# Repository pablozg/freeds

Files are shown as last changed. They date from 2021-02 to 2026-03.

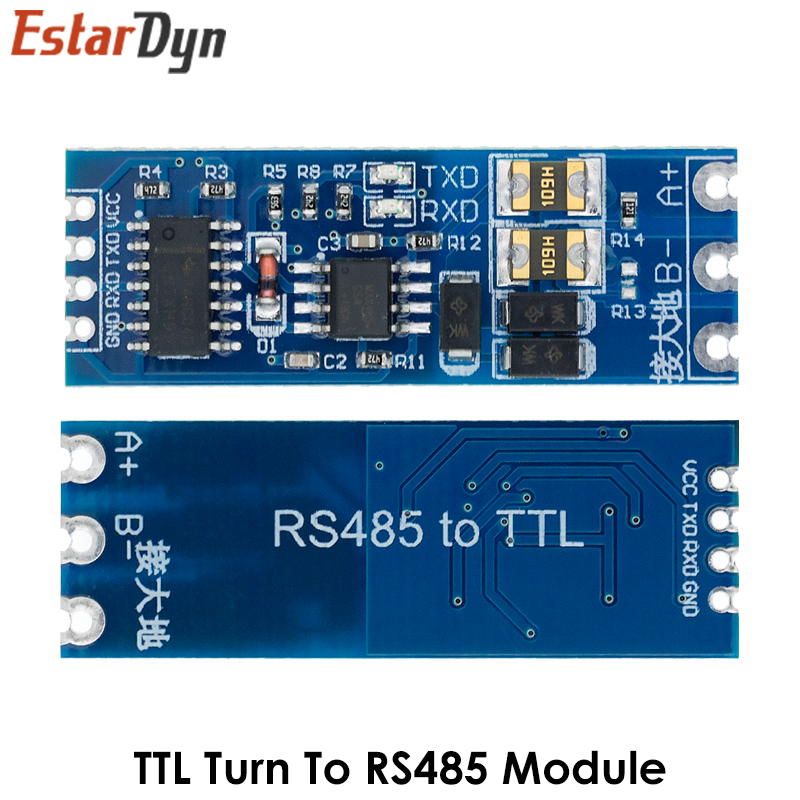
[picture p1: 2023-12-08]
hardware/Clinxer - Version ACS712/FreeDS/Hfd8c04c511834028811a94b4a634df0ex.jpg

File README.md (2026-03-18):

<h1 align="center">
    FreeDS
    <br>
    <a href="#">
        
    </a>
</h1>

**⚠️ ATTENTION / ADVERTENCIA** The project has evolved through different licensing stages. Please check the version you are using:

* **v1.0.7 rev2:** Open Source (GPL-3.0). Source code available in this repo.
* **Betas (up to v1.0.21):** Distributed under CC BY-ND 4.0.
* **v2.0.0 and above:** Proprietary EULA. Requires **Per-Device Activation**.

You can get more info in the Telegram Channel: [http://t.me/freeds_es](http://t.me/freeds_es) or check the community manual: [Community Manual](https://docs.google.com/document/d/1-XLCqHEbpqEPi4geI4CbANmGxodExC__zDvND89xjIU)

**FreeDS** is a universal surplus manager, totally independent of the energy source (photovoltaic and/or wind), created by **Pablo Zerón**, tested by Aeizoon, and PCB Design by amcalo.

---

## 🔑 License & Activation (v2.0.0+)

Starting from **version 2.0.0**, FreeDS uses a **Proprietary EULA**. 

- **Ownership:** The software is the exclusive property of **Pablo Zerón**.
- **Cloud Services:** Powered and managed by **Ibepower Technologies S.L.**
- **Activation:** A unique **Activation Key** is required for each device (linked to Hardware ID).

### How to get a Key?
Send an email to **derivadorfreeds@gmail.com** with:
1. Your **Device ID** (visible on the screen/web interface).
2. **DIY/Contributors:** Proof of contribution or self-assembly (image of the device) to request a **free key**.
3. **Commercial Use:** Request a quote if you are selling hardware with FreeDS firmware.

---

## 📜 License History

| Version Range | License Type | Description |
| :--- | :--- | :--- |
| **<= v1.0.7 rev2** | [GPL-3.0](https://opensource.org/licenses/GPL-3.0) | Open Source. Original legacy code. |
| **v1.0.8 - v1.0.21** | [CC BY-ND 4.0](https://creativecommons.org/licenses/by-nd/4.0/) | Creative Commons. No derivatives allowed. |
| **>= v2.0.0** | **Proprietary EULA** | Proprietary. Requires activation key per hardware. |

*Full legal terms can be found in the [EULA.md](./EULA.md) file.*

---

## ☕ Donate
If you find this project useful, consider supporting its development:



---

## Dependencies (for legacy v1.0.7 compilation)
- **TickerScheduler**: [Toshik/TickerScheduler](https://github.com/Toshik/TickerScheduler)
- **Async MQTT client**: [marvinroger/async-mqtt-client](https://github.com/marvinroger/async-mqtt-client)
- **ArduinoJson**: [bblanchon/ArduinoJson](https://github.com/bblanchon/ArduinoJson)
- **AsyncTCP**: [me-no-dev/AsyncTCP](https://github.com/me-no-dev/AsyncTCP)
- **ESPAsyncWebServer**: [me-no-dev/ESPAsyncWebServer](https://github.com/me-no-dev/ESPAsyncWebServer)
- **ThingPulse OLED SSD1306**: [ThingPulse/esp8266-oled-ssd1306](https://github.com/ThingPulse/esp8266-oled-ssd1306)
- **esp32ModbusTCP**: [bertmelis/esp32ModbusTCP](https://github.com/bertmelis/esp32ModbusTCP)

## Compile (Legacy v1.0.7)
1. **Download:** Clone this repo or download the [PID.zip](https://github.com/pablozg/freeds/archive/refs/heads/PID.zip).
2. **Library Setup:** Extract `lib.zip` into the `/lib` folder.
3. **IDE:** Open with **VSCode** and **PlatformIO**.
4. **Build:** Use PlatformIO to compile and upload to your ESP32.

---
Copyright (c) 2026 Pablo Zerón. Cloud services provided by Ibepower Technologies S.L.

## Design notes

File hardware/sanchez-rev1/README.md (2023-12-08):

La arquitectura "Sánchez rev1" se basa en las ideas de otras arquitecturas hardware para FreeDS, separando el diseño en dos PCBs que caben en las cajas estancas usadas por otras arquitecturas hardware.

La arquitectura Sánchez rev1 incluye:

- Conectores para RS485
- Conectores para sensores de temperatura
  - Espacio para un sensor montado en la parte inferior de la placa de control, pensado para que doblando las patillas pueda tocar el disipador del TRIAC
- Conectores para relés
  - Conector para ventilador controlado por relé 4
- Conectores para pinza amperimétrica
  - Conector de dos pines
  - Conector de jack de audio de 3.5mm

La novedad con respecto a otras arquitecturas es la circuitería y conectores para poder controlar un ventilador por PWM: la idea es que cuanto mayor sea el porcentaje de PWM, más trabajará el ventilador.

El diseño está hecho con KiCAD, y se incluyen los ficheros Gerber (ya compilados y por separado para cada una de las dos PCBs) para comodidad a la hora de pedir la fabricación de las placas.

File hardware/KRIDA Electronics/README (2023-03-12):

Thanks to Olegs Bugrovs from KRIDA Electronics for his contribution to freeDS project publishing
both the pcb schematics and the source code of his dimmer, making it easier to repair and/or upgrade.

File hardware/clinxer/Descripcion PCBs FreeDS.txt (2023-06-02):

Estas PCBs han sido diseñadas siguiendo los esquemas e indicaciones publicados en https://freeds.es con el programa Kicad.
En cuanto a sus dimensiones, estan pensadas para la caja sonoff, que es economica, robusta y tiene la tapa transparente para poder visualizar la pantalla.

He querido hacer unas placas que puedan ser utiles a la mayor parte posible de la gente. Asi, aprovechando la altura de la caja de unos 40mm he pensado en colocar dos circuitos impresos apilados.

El circuito inferior es la placa de potencia.
Se puede escoger entre montar el modulo chino (lowcost) desoldando las bornas y el triac que lleva y puenteando la puerta del modulo con el pin TP1 del circuito impreso, o montar el MOC3041 con sus tres resistencias (ultra lowcost) o cambiar de un sistema a otro para probar cual nos funciona mejor.
Por un tema de espacio, en los bornes de conexion de potencia he incluido uno para unir las tierras de entrada y salida, uno de entrada y salida para el neutro, y las fases de entrada y salida. Las pistas de conexion de potencia al triac y fusible no tienen mascara de soldadura para poder aumentar su seccion depositando una capa gruesa de estaño, soldando un hilo de cobre encima, o lo que se os ocurra.

La placa de control superior dispone de espacio para el modulo RS485 (modbus) a TTL para personas que lo necesiten. El modulo ESP32 escogido es el ESP32-WROOM-32U que tiene conexion de antena externa y deberia dar mas alcance de conexion wifi. La pantalla se monta separada del ESP32.
Tiene pines para conectar los sensores de temperatura, los reles externos, y el sensor de corriente SCT-013-030 si se desea utilizar. El ventilador puede conectarse a 5V para funcionamiento permanente o asociarlo al rele 4 para funcionamiento a partir de un pwm determinado.
Tambien puede colocarse el sensor de temperatura DS18B20 en la placa cerca del triac para poder unir al disipador.

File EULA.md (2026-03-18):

# TÉRMINOS LEGALES, POLÍTICA DE PRIVACIDAD Y CONDICIONES DE USO (EULA)

**Última actualización:** 01/01/2026

Este documento es un acuerdo legal entre el usuario final y **Pablo Zerón** (en adelante, "el Autor") respecto al software/firmware **FreeDS**, así como los términos de privacidad gestionados por **Ibepower Technologies S.L.** (en adelante, "el Proveedor de Servicios Cloud").

---

## 1. RESUMEN DE RESPONSABILIDADES

* **Propiedad Intelectual y Licencia:** **Pablo Zerón** (Autor y Propietario único del código).
* **Tratamiento de Datos y Cloud:** **Ibepower Technologies S.L.** (NIF: B13899117).
* **Finalidad del sistema:** Gestión de licencias, telemetría y servicios de monitorización en la nube.
* **Contacto para Activaciones:** `derivadorfreeds@gmail.com`

---

## 2. INFORMACIÓN DETALLADA

### 2.1 Propiedad Intelectual y Licencia de Uso
El firmware y software **FreeDS** es propiedad intelectual exclusiva de **Pablo Zerón**. 

* **Licencia Propietaria:** Este software (Versiones 2.0.0 o superior) **NO se distribuye bajo licencias Creative Commons**. Se otorga una licencia de uso sujeta a la activación mediante una clave única.
* **Activación por Dispositivo:** El software requiere una **Clave de Activación** vinculada de forma unívoca al identificador de hardware (Hardware ID / ESP32 ID) de cada dispositivo.
* **Restricciones:** Queda estrictamente prohibida la ingeniería inversa del sistema de activación, la distribución de copias activadas sin autorización previa y la eliminación de los créditos de autoría de Pablo Zerón.

### 2.2 Condiciones Comerciales y de Activación
El Autor se reserva el derecho de establecer las condiciones para la entrega de claves:

1.  **Uso Comercial / Reventa:** Cualquier entidad o tercero que comercialice hardware o servicios con el firmware FreeDS deberá obtener y abonar la tarifa por cada Clave de Activación generada.
2.  **Usuarios DIY y Colaboradores:** El Autor podrá facilitar claves **gratuitas** a usuarios particulares (montaje propio no baadas en soluciones comerciales), colaboradores activos o donantes, previa solicitud y validación.

### 2.3 Privacidad y Protección de Datos (RGPD)
Los servicios de infraestructura en la nube y bases de datos son operados por **Ibepower Technologies S.L.**

* **Finalidad:** Monitorización remota y validación técnica de la licencia vinculada al ID de hardware.
* **Datos Recopilados:** Telemetría técnica. Solo se tratarán datos personales (como el email) si el usuario se registra voluntariamente en la plataforma Cloud de Ibepower.
* **Derechos:** Puedes ejercer tus derechos de acceso, rectificación o supresión contactando con `info@ibepower.com`.

### 2.4 Procedimiento de Activación
Para solicitar la clave de activación, envía un correo a **derivadorfreeds@gmail.com** con:
1.  El **ID de dispositivo** (visible en la interfaz o pantalla del hardware).
2.  Justificante de colaboración/donativo (para claves gratuitas) o solicitud comercial.

---

*Pablo Zerón e Ibepower Technologies S.L. se reservan el derecho de modificar estos términos.*

# LEGAL TERMS, PRIVACY POLICY, AND TERMS OF USE (EULA)

**Last updated:** 01/01/2026

This document constitutes a legal agreement between the end-user and **Pablo Zerón** (hereinafter, "the Author") regarding the **FreeDS** software/firmware, as well as the privacy terms managed by **Ibepower Technologies S.L.** (hereinafter, "the Cloud Service Provider").

---

## 1. SUMMARY OF RESPONSIBILITIES

* **Intellectual Property and License:** **Pablo Zerón** (Author and sole Owner of the code).
* **Data Processing and Cloud Services:** **Ibepower Technologies S.L.** (Tax ID/NIF: B13899117).
* **System Purpose:** License management, telemetry, and cloud monitoring services.
* **Activation Contact:** `derivadorfreeds@gmail.com`

---

## 2. DETAILED INFORMATION

### 2.1 Intellectual Property and License of Use
The **FreeDS** firmware and software are the exclusive intellectual property of **Pablo Zerón**.

* **Proprietary License:** This software (Versions 2.0.0 or higher) is **NOT distributed under Creative Commons licenses**. A license of use is granted subject to activation via a unique key.
* **Per-Device Activation:** The software requires an **Activation Key** uniquely linked to the hardware identifier (Hardware ID / ESP32 ID) of each individual device.
* **Restrictions:** Reverse engineering of the activation system, distribution of activated copies without prior authorization, and the removal of Pablo Zerón's authorship credits are strictly prohibited.

### 2.2 Commercial and Activation Conditions
The Author reserves the right to establish the conditions for the issuance of activation keys:

1.  **Commercial Use / Resale:** Any entity or third party marketing hardware or services that include the FreeDS firmware must obtain and pay the established fee for each generated Activation Key.
2.  **DIY Users and Collaborators:** The Author may provide **free** activation keys to individual users (non-commercial self-builds not based on commercial solutions), active collaborators, or donors, subject to request and validation.

### 2.3 Privacy and Data Protection (GDPR)
Cloud infrastructure services and databases are operated by **Ibepower Technologies S.L.**

* **Purpose:** Remote monitoring and technical validation of the license linked to the hardware ID.
* **Data Collection:** Technical telemetry. Personal data (such as email) will only be processed if the user voluntarily registers on the Ibepower Cloud platform.
* **User Rights:** You may exercise your rights of access, rectification, or erasure by contacting `info@ibepower.com`.

### 2.4 Activation Procedure
To request the activation key required for software operation, please send an email to **derivadorfreeds@gmail.com** including:

1.  The **Device ID** (visible on the configuration interface or the hardware screen).
2.  **Proof:** Documentation of collaboration/donation (for free keys) or a commercial license inquiry.

---

*Pablo Zerón and Ibepower Technologies S.L. reserve the right to modify these terms to adapt them to technical or legal developments.*

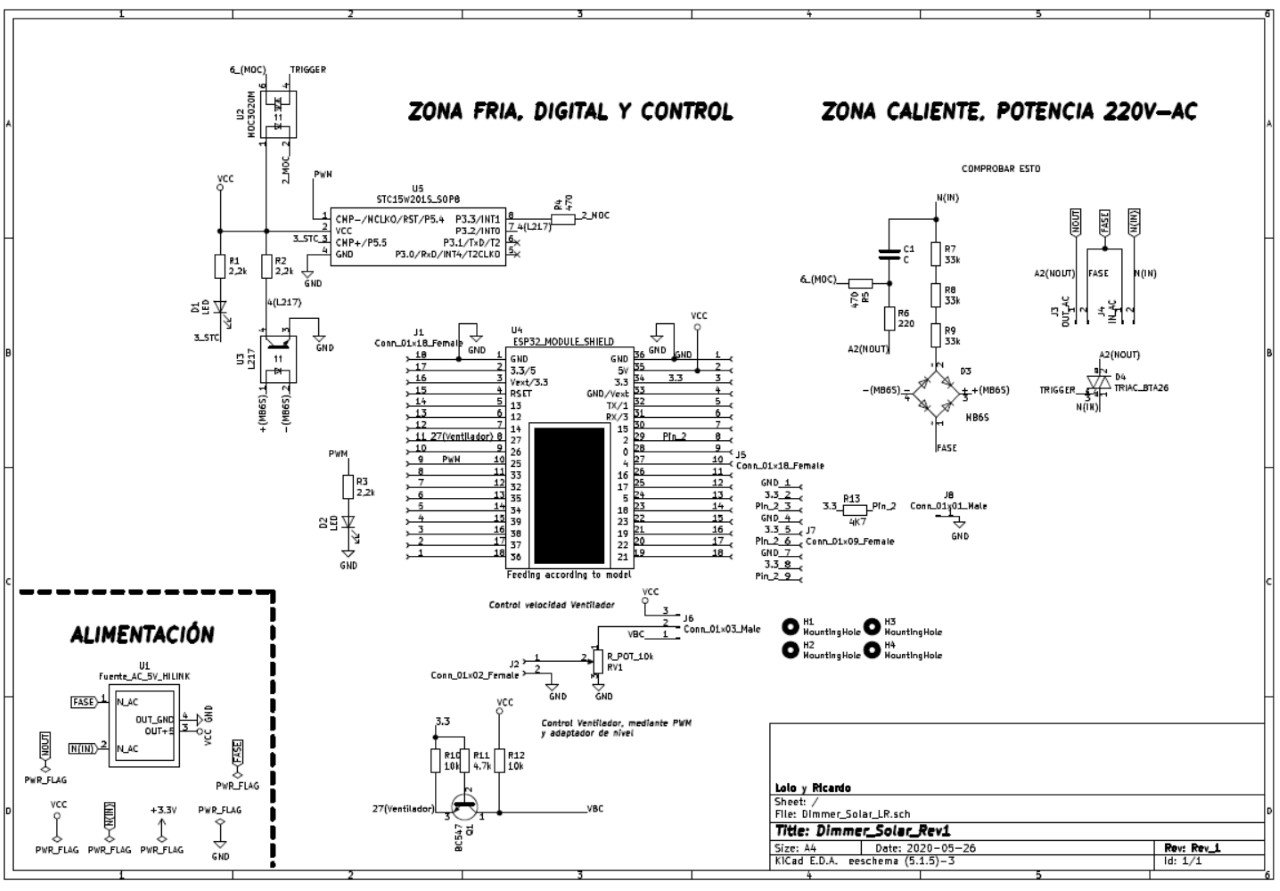
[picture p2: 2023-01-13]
Scheme PCB 1.0.jpg

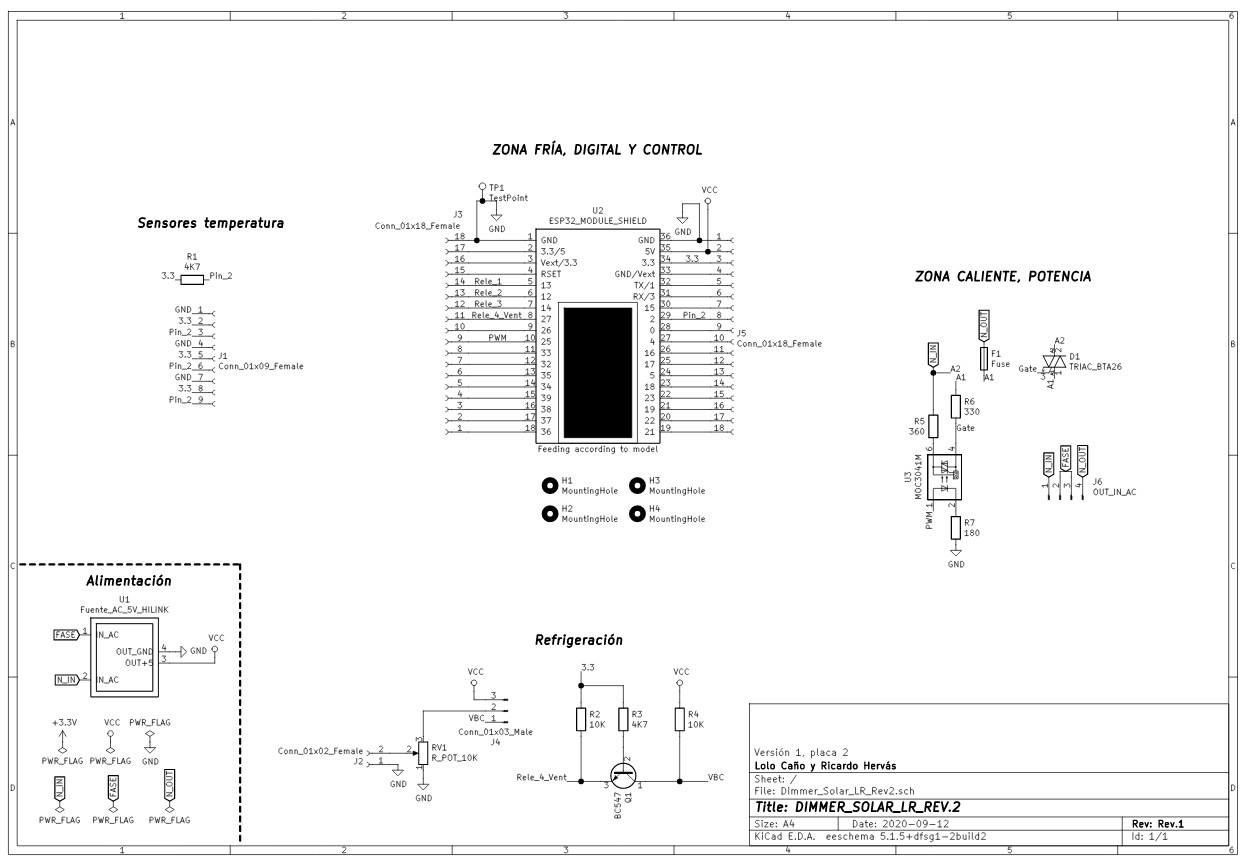
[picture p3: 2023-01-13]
Scheme PCB 2.0.jpg

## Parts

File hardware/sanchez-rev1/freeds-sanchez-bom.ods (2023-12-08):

Item | Qty | Reference(s) | Value | LibPart | Grupo | Footprint | Datasheet | DNP | Compras | Grupo | Nota
1 | 1 | AE1 | Antenna | Device:Antenna | Básico |  | ~ |  | https://www.aliexpress.com/item/32276257238.html | Básico
2 | 2 | C1, C2 | 10µF | Device:C_Small | Pinza Amperimétrica | Capacitor_THT:C_Disc_D4.7mm_W2.5mm_P5.00mm | ~ |  | https://www.aliexpress.com/item/1005001715033995.html | Pinza Amperimétrica
3 | 1 | D2 | 1N4007 | Diode:1N4007 |  | Diode_THT:D_DO-41_SOD81_P10.16mm_Horizontal | http://www.vishay.com/docs/88503/1n4001.pdf
4 | 1 | F1 | Fuse | Device:Fuse | Básico | Fuse:Fuseholder_Clip-5x20mm_Littelfuse_100_Inline_P20.50x4.60mm_D1.30mm_Horizontal | ~ |  | https://www.aliexpress.com/item/1005002876255086.html | Básico
5 | 2 | J1, J2 | Clema K1000 | Connector:Screw_Terminal_01x02 | Básico | componentes-auxiliares:Clema 20x14mm K1000 2P | ~ |  | https://www.aliexpress.com/item/4000170287617.html | Básico
6 | 2 | J3, J4 | Inter-PCB | Connector_Generic:Conn_01x04 | Básico | Connector_PinHeader_2.54mm:PinHeader_1x04_P2.54mm_Vertical | ~ |  |  | Básico
7 | 1 | J5 | Pinza Amper. | Connector:Conn_01x02_Male | Pinza Amperimétrica | Connector_PinHeader_2.54mm:PinHeader_1x02_P2.54mm_Vertical | ~ |  | https://www.aliexpress.com/item/32758380907.html | Pinza Amperimétrica
8 | 1 | J6 | CT Clamp | Connector:AudioJack2 | Pinza Amperimétrica | Connector_Audio:Jack_3.5mm_CUI_SJ1-3525N_Horizontal | ~ |  | https://www.aliexpress.com/item/1005004657628758.html https://www.aliexpress.com/item/32871877936.html | Pinza Amperimétrica | PJ3F07 / PJ-324M
9 | 1 | J7 | Temp sensor | Connector:Conn_01x03_Pin | Temperatura | Connector_PinHeader_2.54mm:PinHeader_1x03_P2.54mm_Vertical | ~ |  | https://www.aliexpress.com/item/32758380907.html | Temperatura
10 | 1 | J8 | Temp Sensor | Connector:Conn_01x03_Pin | Temperatura | Connector_PinHeader_2.54mm:PinHeader_1x03_P2.54mm_Vertical | ~ |  | https://www.aliexpress.com/item/32758380907.html | Temperatura
11 | 1 | J9 | R4_FAN | Connector:Conn_01x03_Pin | Ventilador relé | Connector_PinHeader_2.54mm:PinHeader_1x03_P2.54mm_Vertical | ~ |  | https://www.aliexpress.com/item/32758380907.html | Ventilador relé
12 | 1 | J10 | RELÉS | Connector:Conn_01x08_Pin | Relés | Connector_PinHeader_2.54mm:PinHeader_1x08_P2.54mm_Vertical | ~ |  | https://www.aliexpress.com/item/32758380907.html | Relés
13 | 1 | J16 | Conn_01x02_Male | Connector:Conn_01x02_Male | Ventilador PWM | Connector_PinHeader_2.54mm:PinHeader_1x02_P2.54mm_Vertical | ~ |  | https://www.aliexpress.com/item/32758380907.html | Ventilador PWM
14 | 1 | M1 | 40mm 5V PWM Fan | Motor:Fan_4pin |  |  | https://noctua.at/en/products/fan/nf-a4x10-pwm/specification | DNP | https://www.aliexpress.com/item/1005003661639143.html |  | https://electronics.stackexchange.com/questions/446128/5v-4-pin-noctua-a4x10-on-raspberry-pi
15 | 1 | M2 | 40mm Fan | Motor:Fan |  |  | ~ |  | https://www.aliexpress.com/item/33050954650.html
16 | 1 | N1 | Housing | Mechanical:Housing | Básico |  | ~ |  | https://www.aliexpress.com/item/32856717327.html | Básico
17 | 1 | PS1 | HLK-PM01 | Converter_ACDC:HLK-PM01 | Básico | Converter_ACDC:Converter_ACDC_HiLink_HLK-PMxx | http://www.hlktech.net/product_detail.php?ProId=54 |  | https://www.aliexpress.com/item/32408565688.html | Básico
18 | 1 | Q1 | BTA26-600BW | Triac_Thyristor:BTA16-600BW | Básico | componentes-auxiliares:TOP3_Vertical | https://www.st.com/resource/en/datasheet/bta16.pdf |  | https://www.aliexpress.com/item/32508392409.html | Básico
19 | 1 | Q2 | BC337 | Transistor_BJT:BC337 | Ventilador relé | Package_TO_SOT_THT:TO-92_Inline | https://diotec.com/tl_files/diotec/files/pdf/datasheets/bc337.pdf |  | https://www.aliexpress.com/item/1005003391155385.html | Ventilador relé
20 | 1 | Q3 | DS18B20 | Sensor_Temperature:DS18B20 | Temperatura | Package_TO_SOT_THT:TO-92_Inline | http://datasheets.maximintegrated.com/en/ds/DS18B20.pdf |  | https://www.aliexpress.com/item/1783091649.html | Temperatura
21 | 1 | Q4 | BS170 | Transistor_FET:BS170 |  | Package_TO_SOT_THT:TO-92_Inline | https://www.onsemi.com/pub/Collateral/BS170-D.PDF |  | https://www.aliexpress.com/item/33043571478.html
22 | 1 | R1 | 360Ω | Device:R_Small | Básico | Resistor_THT:R_Axial_DIN0207_L6.3mm_D2.5mm_P10.16mm_Horizontal | ~ |  | https://www.aliexpress.com/item/1005001931818502.html | Básico
23 | 1 | R2 | 330Ω | Device:R_Small | Básico | Resistor_THT:R_Axial_DIN0207_L6.3mm_D2.5mm_P10.16mm_Horizontal | ~ |  | https://www.aliexpress.com/item/1005001931818502.html | Básico
24 | 2 | R3, R4 | 180Ω | Device:R_Small | Básico | Resistor_THT:R_Axial_DIN0207_L6.3mm_D2.5mm_P10.16mm_Horizontal | ~ |  | https://www.aliexpress.com/item/1005001931818502.html | Básico
25 | 3 | R5, R6, R9 | 10KΩ | Device:R_Small | Pinza Amperimétrica | Resistor_THT:R_Axial_DIN0207_L6.3mm_D2.5mm_P10.16mm_Horizontal | ~ |  | https://www.aliexpress.com/item/1005001931818502.html | Pinza Amperimétrica
26 | 1 | R7 | 4.7KΩ | Device:R_Small | Temperatura | Resistor_THT:R_Axial_DIN0207_L6.3mm_D2.5mm_P10.16mm_Horizontal | ~ |  | https://www.aliexpress.com/item/1005001931818502.html | Temperatura
27 | 1 | R8 | 3.3Ω | Device:R_Small | Ventilador PWM | Resistor_THT:R_Axial_DIN0207_L6.3mm_D2.5mm_P10.16mm_Horizontal | ~ |  | https://www.aliexpress.com/item/1005001931818502.html | Ventilador PWM
28 | 1 | SW1 | PRG | Switch:SW_SPST | Botón | Button_Switch_THT:SW_Tactile_SPST_Angled_PTS645Vx83-2LFS | ~ |  | https://www.aliexpress.com/item/32912894177.html | Botón
29 | 1 | U2 | MOC3041M | Relay_SolidState:MOC3041M | Básico | Package_DIP:DIP-6_W7.62mm | https://www.onsemi.com/pub/Collateral/MOC3043M-D.pdf |  | https://www.aliexpress.com/item/32870289997.html | Básico
30 | 1 | U3 | HW-0519 (Módulo RS485-TTL) | module:HW-519_MODBUS | Modbus | componentes-auxiliares:HW-519 TTL-RS485 |  |  | https://www.aliexpress.com/item/1005001621746811.html | Modbus
31 | 1 | U4 | ESP32-WROOM-32U | Espressif:ESP32-DevKitC | Básico | Espressif:ESP32-DevKitC | https://docs.espressif.com/projects/esp-idf/zh_CN/latest/esp32/hw-reference/esp32/get-started-devkitc.html |  | https://www.aliexpress.com/item/32864722159.html | Básico
32 | 1 | U5 | SSD1306_I2C_128x64 | OLED_SSD1312_I2C:SSD1312_I2C_128x64 | Básico | componentes-auxiliares:OLED_SSD1306_I2C_0.96 |  |  | https://www.aliexpress.com/item/32638662748.html | Básico

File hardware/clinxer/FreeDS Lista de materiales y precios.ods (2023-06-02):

Id | Identificador | Huella | Cantidad | Identificación | Precio | Suministrador y ref
1 | U3 | MW-519 MODBUS | 1 | Modulo MODBUS | 1,88 | https://es.aliexpress.com/item/1005001621746811.html
2 | R1 | R_0805_2012Metric_Pad1.20x1.40mm_HandSolder | 1 | 180R
3 | U1 | OLED_SSD1306_I2C_0.96 | 1 | SSD1306_I2C_128x64 | 1,69 | https://es.aliexpress.com/item/32638662748.html
6 | R2 | R_0805_2012Metric_Pad1.20x1.40mm_HandSolder | 1 | 4K7
7 | Q1 | TO-92_Inline | 1 | DS18B20 | 0,34 | https://es.aliexpress.com/item/1783091649.html?curPageLogUid=4cPm6rJjSKd2
9 | Q2 | TO-92_Inline | 1 | BC337 | 1,4 | https://es.aliexpress.com/item/1005003391155385.html?curPageLogUid=M835OcH09qsy
10 | SW1 | SW_Tactile_SPST_Angled_6X6X12 | 1 | PRG |  | https://es.aliexpress.com/item/32912894177.html?scm_id=1007.12873.274955.0&scm-url=1007.12873.274955.0
11 | U2 | ESP32-WROOM-32U | 1 | ESP32-WROOM-32U | 4,05 | https://es.aliexpress.com/item/32864722159.html
14 |  | Caja sonoff |  |  | 6,39 | https://es.aliexpress.com/item/32856717327.html
15 |  | Disipador y ventilador |  |  | 5,54 | https://es.aliexpress.com/item/33050954650.html
 |  |  |  |  | 1,27 | GASTOS DE ENVIO PANTALLA ANTENA Y MICRO
18 | J2 | PinHeader_1x04_P2.54mm_Vertical | 1 | Tiras DE PINES MACHO | 1,5 | https://es.aliexpress.com/item/32758380907.html?curPageLogUid=IyVioYqjNETk
19 | PS1 | Converter_ACDC_HiLink_HLK-PMxx | 1 | HLK-PM01 | 3,5 | https://es.aliexpress.com/item/32408565688.html?curPageLogUid=ZmRvf0wLucnI
20 | J1 | KF7.62_4P | 1 | Screw_Terminal_01x04 KF7.62_4P | 0,402 | https://es.aliexpress.com/item/33018709631.html
21 | U5 | YYAC-35 PWM TRIAC | 1 | Modulo de Control PWM de potencia | 6,6 | https://es.aliexpress.com/item/1005004149677279.html
22 | F1 | Fuseholder_Clip-5x20mm_Littelfuse_100_Inline_P20.50x4.60mm_D1.30mm_Horizontal | 1 | Fuse | 1,5 | https://es.aliexpress.com/item/1005002876255086.html?curPageLogUid=At3GBBWHi4sC
 | Q3 | TOP3_Vertical | 1 | BTA26-600BW | 0,72 | https://es.aliexpress.com/item/32508392409.html
 |  |  |  | Mica, separadores, etc | 5
 |  | PCBs |  | JPLC | 2,864 | 5 parejas con envio Global Standard Direct Line
 |  |  |  |  | 44,646

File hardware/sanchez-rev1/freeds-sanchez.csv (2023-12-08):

Source: | /home/ivan/devel/freeds-pcb/sanchez/freeds-sanchez/freeds-sanchez.kicad_sch
Date: | vie 14 jul 2023 13:41:45
Tool: | Eeschema 7.0.3+dfsg-1
Generator: | /usr/share/kicad/plugins/bom_csv_grouped_by_value.py
Component Count: | 38
Collated Components:
Item | Qty | Reference(s) | Value | LibPart | Footprint | Datasheet | DNP | Compras | Grupo | Nota
1 | 1 | AE1 | Antenna | Device:Antenna |  | ~ |  | https://www.aliexpress.com/item/32276257238.html | Básico
2 | 2 | C1, C2 | 10µF | Device:C_Small | Capacitor_THT:C_Disc_D4.7mm_W2.5mm_P5.00mm | ~ |  | https://www.aliexpress.com/item/1005001715033995.html | Pinza Amperimétrica
3 | 1 | D2 | 1N4007 | Diode:1N4007 | Diode_THT:D_DO-41_SOD81_P10.16mm_Horizontal | http://www.vishay.com/docs/88503/1n4001.pdf
4 | 1 | F1 | Fuse | Device:Fuse | Fuse:Fuseholder_Clip-5x20mm_Littelfuse_100_Inline_P20.50x4.60mm_D1.30mm_Horizontal | ~ |  | https://www.aliexpress.com/item/1005002876255086.html | Básico
5 | 2 | J1, J2 | Clema K1000 | Connector:Screw_Terminal_01x02 | componentes-auxiliares:Clema 20x14mm K1000 2P | ~ |  | https://www.aliexpress.com/item/4000170287617.html | Básico
6 | 2 | J3, J4 | Inter-PCB | Connector_Generic:Conn_01x04 | Connector_PinHeader_2.54mm:PinHeader_1x04_P2.54mm_Vertical | ~ |  |  | Básico
7 | 1 | J5 | Pinza Amper. | Connector:Conn_01x02_Male | Connector_PinHeader_2.54mm:PinHeader_1x02_P2.54mm_Vertical | ~ |  | https://www.aliexpress.com/item/32758380907.html | Pinza Amperimétrica
8 | 1 | J6 | CT Clamp | Connector:AudioJack2 | Connector_Audio:Jack_3.5mm_CUI_SJ1-3525N_Horizontal | ~ |  | https://www.aliexpress.com/item/1005004657628758.html https://www.aliexpress.com/item/32871877936.html | Pinza Amperimétrica | PJ3F07 / PJ-324M
9 | 1 | J7 | Temp sensor | Connector:Conn_01x03_Pin | Connector_PinHeader_2.54mm:PinHeader_1x03_P2.54mm_Vertical | ~ |  | https://www.aliexpress.com/item/32758380907.html | Temperatura
10 | 1 | J8 | Temp Sensor | Connector:Conn_01x03_Pin | Connector_PinHeader_2.54mm:PinHeader_1x03_P2.54mm_Vertical | ~ |  | https://www.aliexpress.com/item/32758380907.html | Temperatura
11 | 1 | J9 | R4_FAN | Connector:Conn_01x03_Pin | Connector_PinHeader_2.54mm:PinHeader_1x03_P2.54mm_Vertical | ~ |  | https://www.aliexpress.com/item/32758380907.html | Ventilador relé
12 | 1 | J10 | RELÉS | Connector:Conn_01x08_Pin | Connector_PinHeader_2.54mm:PinHeader_1x08_P2.54mm_Vertical | ~ |  | https://www.aliexpress.com/item/32758380907.html | Relés
13 | 1 | J16 | Conn_01x02_Male | Connector:Conn_01x02_Male | Connector_PinHeader_2.54mm:PinHeader_1x02_P2.54mm_Vertical | ~ |  | https://www.aliexpress.com/item/32758380907.html | Ventilador PWM
14 | 1 | M1 | 40mm 5V PWM Fan | Motor:Fan_4pin |  | https://noctua.at/en/products/fan/nf-a4x10-pwm/specification | DNP | https://www.aliexpress.com/item/1005003661639143.html |  | https://electronics.stackexchange.com/questions/446128/5v-4-pin-noctua-a4x10-on-raspberry-pi
15 | 1 | M2 | 40mm Fan | Motor:Fan |  | ~ |  | https://www.aliexpress.com/item/33050954650.html
16 | 1 | N1 | Housing | Mechanical:Housing |  | ~ |  | https://www.aliexpress.com/item/32856717327.html | Básico
17 | 1 | PS1 | HLK-PM01 | Converter_ACDC:HLK-PM01 | Converter_ACDC:Converter_ACDC_HiLink_HLK-PMxx | http://www.hlktech.net/product_detail.php?ProId=54 |  | https://www.aliexpress.com/item/32408565688.html | Básico
18 | 1 | Q1 | BTA26-600BW | Triac_Thyristor:BTA16-600BW | componentes-auxiliares:TOP3_Vertical | https://www.st.com/resource/en/datasheet/bta16.pdf |  | https://www.aliexpress.com/item/32508392409.html | Básico
19 | 1 | Q2 | BC337 | Transistor_BJT:BC337 | Package_TO_SOT_THT:TO-92_Inline | https://diotec.com/tl_files/diotec/files/pdf/datasheets/bc337.pdf |  | https://www.aliexpress.com/item/1005003391155385.html | Ventilador relé
20 | 1 | Q3 | DS18B20 | Sensor_Temperature:DS18B20 | Package_TO_SOT_THT:TO-92_Inline | http://datasheets.maximintegrated.com/en/ds/DS18B20.pdf |  | https://www.aliexpress.com/item/1783091649.html | Temperatura
21 | 1 | Q4 | BS170 | Transistor_FET:BS170 | Package_TO_SOT_THT:TO-92_Inline | https://www.onsemi.com/pub/Collateral/BS170-D.PDF |  | https://www.aliexpress.com/item/33043571478.html
22 | 1 | R1 | 360Ω | Device:R_Small | Resistor_THT:R_Axial_DIN0207_L6.3mm_D2.5mm_P10.16mm_Horizontal | ~ |  | https://www.aliexpress.com/item/1005001931818502.html | Básico
23 | 1 | R2 | 330Ω | Device:R_Small | Resistor_THT:R_Axial_DIN0207_L6.3mm_D2.5mm_P10.16mm_Horizontal | ~ |  | https://www.aliexpress.com/item/1005001931818502.html | Básico
24 | 2 | R3, R4 | 180Ω | Device:R_Small | Resistor_THT:R_Axial_DIN0207_L6.3mm_D2.5mm_P10.16mm_Horizontal | ~ |  | https://www.aliexpress.com/item/1005001931818502.html | Básico
25 | 3 | R5, R6, R9 | 10KΩ | Device:R_Small | Resistor_THT:R_Axial_DIN0207_L6.3mm_D2.5mm_P10.16mm_Horizontal | ~ |  | https://www.aliexpress.com/item/1005001931818502.html | Pinza Amperimétrica
26 | 1 | R7 | 4.7KΩ | Device:R_Small | Resistor_THT:R_Axial_DIN0207_L6.3mm_D2.5mm_P10.16mm_Horizontal | ~ |  | https://www.aliexpress.com/item/1005001931818502.html | Temperatura
27 | 1 | R8 | 3.3Ω | Device:R_Small | Resistor_THT:R_Axial_DIN0207_L6.3mm_D2.5mm_P10.16mm_Horizontal | ~ |  | https://www.aliexpress.com/item/1005001931818502.html | Ventilador PWM
28 | 1 | SW1 | PRG | Switch:SW_SPST | Button_Switch_THT:SW_Tactile_SPST_Angled_PTS645Vx83-2LFS | ~ |  | https://www.aliexpress.com/item/32912894177.html | Botón
29 | 1 | U2 | MOC3041M | Relay_SolidState:MOC3041M | Package_DIP:DIP-6_W7.62mm | https://www.onsemi.com/pub/Collateral/MOC3043M-D.pdf |  | https://www.aliexpress.com/item/32870289997.html | Básico
30 | 1 | U3 | HW-0519 (Módulo RS485-TTL) | module:HW-519_MODBUS | componentes-auxiliares:HW-519 TTL-RS485 |  |  | https://www.aliexpress.com/item/1005001621746811.html | Modbus
31 | 1 | U4 | ESP32-WROOM-32U | Espressif:ESP32-DevKitC | Espressif:ESP32-DevKitC | https://docs.espressif.com/projects/esp-idf/zh_CN/latest/esp32/hw-reference/esp32/get-started-devkitc.html |  | https://www.aliexpress.com/item/32864722159.html | Básico
32 | 1 | U5 | SSD1306_I2C_128x64 | OLED_SSD1312_I2C:SSD1312_I2C_128x64 | componentes-auxiliares:OLED_SSD1306_I2C_0.96 |  |  | https://www.aliexpress.com/item/32638662748.html | Básico

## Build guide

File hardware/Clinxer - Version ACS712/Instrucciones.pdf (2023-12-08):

FREEDS

Toda la información descrita en este manual está sacada del proyecto FreeDS y quiero agradecer a sus desarrolladores y colaboradores su difusión desinteresada.

El diseño de las PCBs

Este diseño consta de dos placas interconectadas por una tira de pines. Tal y como se ha realizado hace falta un poco de maña y algunas herramientas como soldador de punta muy fina para los componentes SMD, desoldador de aire caliente, y herramientas varias para el mecanizado como diferentes tipos de brocas, machos de roscar, limas, etc.

Este montaje lleva varias horas y es algo a tener en cuenta antes de decidirse a llevarlo a cabo. Con este manual solo se pretende intentar aportar alguna idea y contribuir a este gran proyecto.

Circuito impreso de potencia.

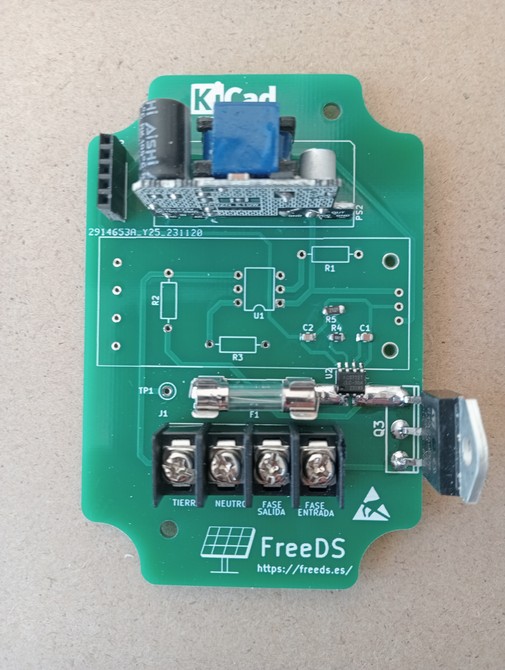
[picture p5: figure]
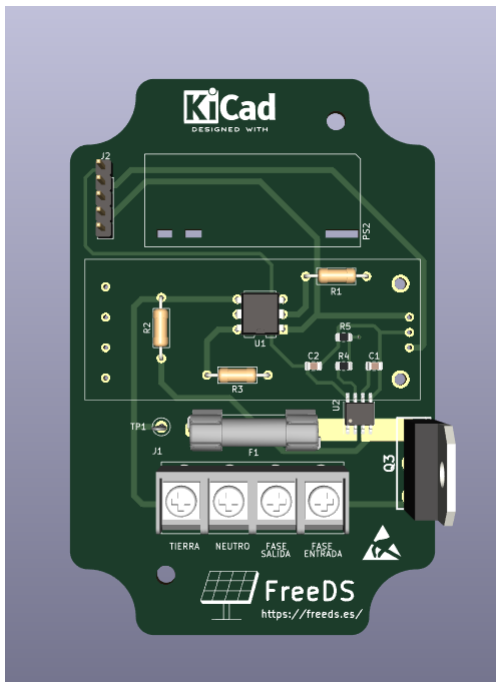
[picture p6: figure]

Incorpora los bornes de conexión, fuente de alimentación de 5V 2A, fusible y triac. Las pistas de potencia no llevan mascara de soldadura para poder aumentar su sección depositando estaño en su superficie.

Esta preparado para realizar el montaje ultralowcost (soldando los componentes de la imagen 3D de la izquierda, fuente de alimentación incluida), o el diseño lowcost incorporando un modulo PWM,

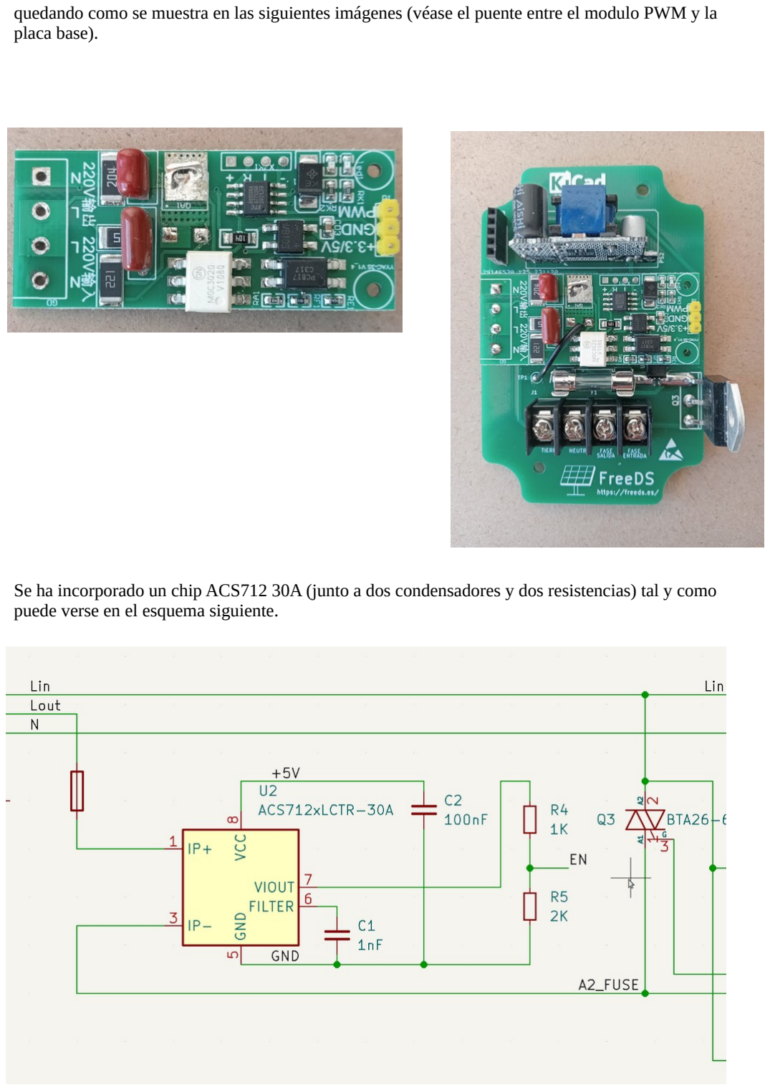
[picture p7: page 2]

quedando como se muestra en las siguientes imágenes (véase el puente entre el modulo PWM y la placa base).

Se ha incorporado un chip ACS712 30A (junto a dos condensadores y dos resistencias) tal y como puede verse en el esquema siguiente.

Dicho chip proporciona la analógica para la medición de energía a la salida del TRIAC y el software se encarga de realizar la conversión para la gestión y visualización de este consumo.

La ventaja frente a la pinza es su reducido tamaño y poco precio, por lo que se puede incluir de serie en el circuito simplificando el montaje.

Como inconveniente citar que es un circuito invasivo ya que está intercalado en el circuito de potencia en serie con el triac. Aun así, el modelo empleado es de 30A por lo que no debería dar problemas.

Circuito impreso superior para el microprocesador.

Incorpora la placa del microprocesador ESP32-WROOM-32U (con antena externa), la pantalla, y el control del ventilador y los sensores de temperatura, conector para salidas a relés y pulsador.
Se puede instalar un módulo de comunicaciones (opcional) para los sistemas cerrados donde el inversor no pueda comunicar con el FreeDS y necesite hacerlo a través de un meter externo.

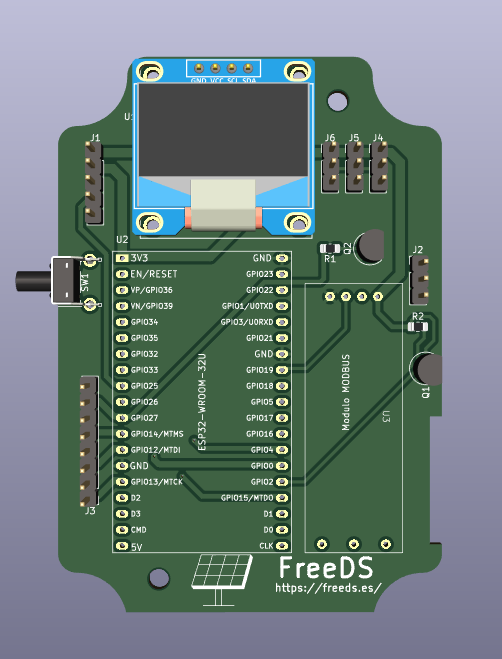
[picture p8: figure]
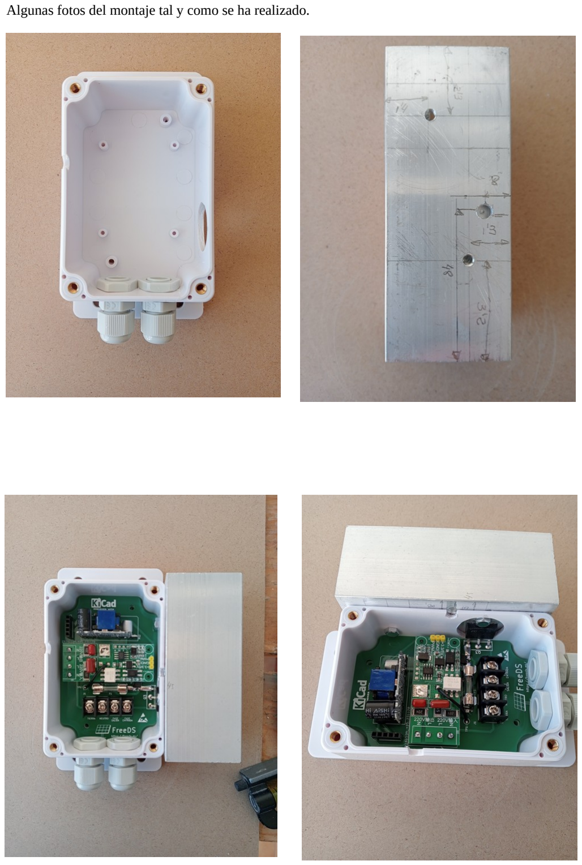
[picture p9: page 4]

Algunas fotos del montaje tal y como se ha realizado.

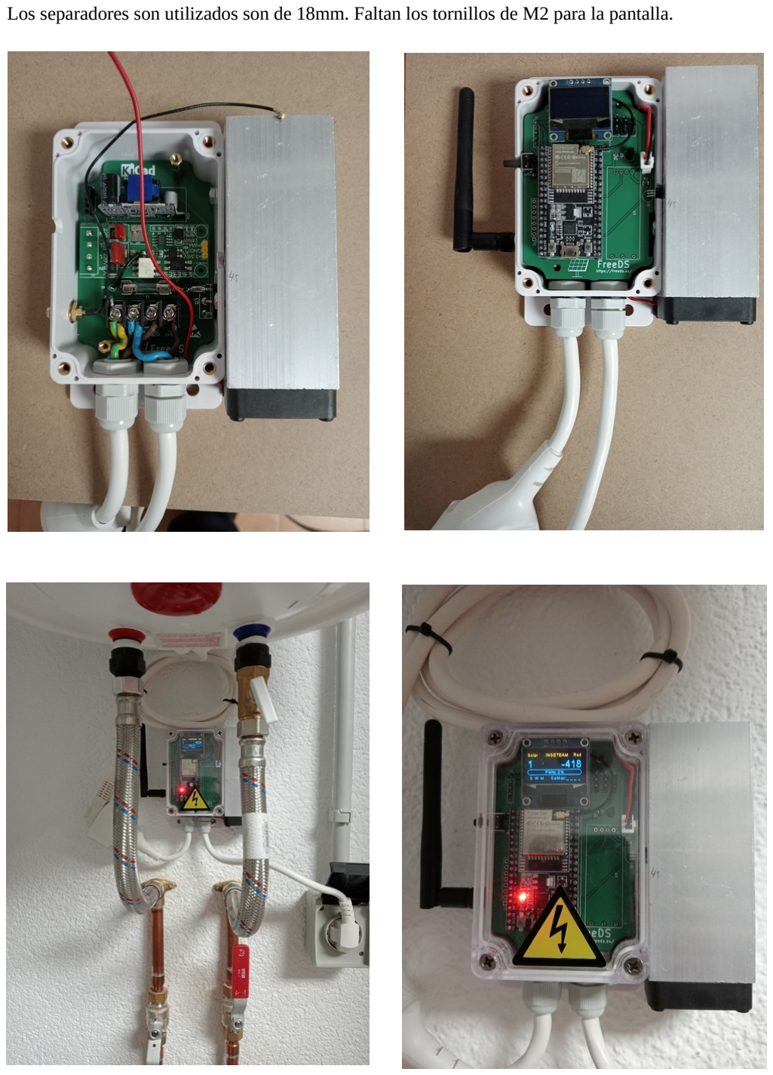
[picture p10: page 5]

Los separadores son utilizados son de 18mm. Faltan los tornillos de M2 para la pantalla.

Lista de los principales materiales y enlaces de aliexpress:

Caja sonoff
https://es.aliexpress.com/item/32856717327.html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 (https://es.aliexpress.com/item/32856717327.html)

Disipador de 40x40x100
https://es.aliexpress.com/item/1005003352858467.html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 (https://es.aliexpress.com/item/1005003352858467.html)

Micro ESP32-WROOM-32U (con conector de antena externa) https://es.aliexpress.com/item/32864722159.html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 (https://es.aliexpress.com/item/32864722159.html)

SSD1306
https://es.aliexpress.com/item/32638662748.html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 (https://es.aliexpress.com/item/32638662748.html)

Antena externa
https://es.aliexpress.com/item/32957527411.html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 (https://es.aliexpress.com/item/32957527411.html)

ACS712TELC-30A
https://es.aliexpress.com/item/1005003973175552.html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 (https://es.aliexpress.com/item/1005003973175552.html)

Ventilador 40x40x10 5V
https://es.aliexpress.com/item/32640103358.html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 (https://es.aliexpress.com/item/32640103358.html)

Módulo de Control PWM
https://es.aliexpress.com/item/1005004149677279.html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 (https://es.aliexpress.com/item/1005004149677279.html)

Conector de bloque de terminales https://es.aliexpress.com/item/1005003493308832.html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 (https://es.aliexpress.com/item/1005003493308832.html) Fuente de alimentación 5V 2A. https://es.aliexpress.com/item/1005001970797548.html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 (https://es.aliexpress.com/item/1005001970797548.html) Modulo RS485
https://es.aliexpress.com/item/1005001621746811.html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 (https://es.aliexpress.com/item/1005001621746811.html)

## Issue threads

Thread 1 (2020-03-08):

Fallo PWM manual

Tjchispas, 2020-03-08:
Hola, ante todo darte las gracias por el curro que te has pegado.
El problema que le encuentro es que al activar el PWM manualmente en la monitorización web del esp si aparece el porcentaje correcto, pero por mqtt envía uno totalmente diferente en 50% por mqtt envía pwm=283 mi derivador esta conectado por mqtt y funciona de 0 a 100, no he podido probar con energía solar era demasiado tarde, en caso de que necesites mas datos o servir de betatester no dudes en contactar. Saludos

pablozg, 2020-03-08:
Hola, efectivamente era un fallo a la hora de convertir el valor de pwm para enviarlo por mqtt, bájate los binarios que acabo de subir y actualizas mediante la página web. No importa el orden, solamente tienes que esperar a que reinicie para actualizar el siguiente.

Tjchispas, 2020-03-08:
Ahora perfecto gracias, al 50% 750w de mi termo de 1500w, me gusta el modo de actualizar muy simple y efectivo.
Una petición para futuras versiones, puedes poner el configurar uno de los relés mqtt como un pwm mqtt, tengo un ESP8266 con tasmota configurado como dimmer y lo enlazo con el porcentaje de pwm mediante node red, pero hacerlo desde el FreeDs seria mucho mas fácil y podría usarlo mas gente.

pablozg, 2020-03-08:
No te entiendo con lo del relé pwm mqtt. ¿Puedes poner un ejemplo?

Respecto a lo del mqtt, el manual está puliendose, pero estos son los comandos por mqtt que puedes usar:

freeds/cmnd/pwm -> Acepta 1 para encender y 0 para apagar
freeds/cmnd/pwmman -> Acepta 1 para manual y 0 para auto
freeds/cmnd/pwmmanvalue -> Acepta valores de 0 a 100 que corresponde al % en modo manual
freeds/cmnd/screen -> Acepta valores de 0 a 4 corresponden a las pantallas de información en el oled
freeds/cmnd/pwmfrec -> Acepta valores entre 0 y 3000 corresponde a la frecuencia pwm
freeds/cmnd/brightness -> Acepta valores de 0 a 100 % corresponde al brillo de la pantalla

Tjchispas, 2020-03-08:
A cojonudo que ya tienes implementados los comandos, perfecto crearé algunos switch en HA

Le que no he sido capaz de explicarte es simplemente que uno de los 4 reles que de pueden configurar desde la web sea un pwm por mqtt con tasmota

Tjchispas, 2020-03-08:
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

pablozg, 2020-03-08:
Lo que quieres hacer es que cuando se active el relé envie un comando mqtt que tu elijas, en este caso uno para activar un switch en tasmota, no?

Tjchispas, 2020-03-08:
No exactamente lo que debe de enviar el el porcentaje pwm para que el tasmota configurado como dimmer actué sobre el dimmer físico, el esp32 no esta conectado físicamente al dimmer, por eso uso node red no encontré otro modo de enlazarlos, tampoco tengo los conocimientos suficientes

pablozg, 2020-03-08:
Vale, pero además de enviar el pwm con valor, el tema lo debes escribir tú, ya que si no lo indicas no hay forma de saber a quien enviarlo.

Ok, lo tengo en cuenta y pensaré como integrarlo.

altusis1, 2020-03-09:
hola

altusis1, 2020-03-09:
hola pablozg. Muchas gracias por compartir esta maravilla de programa.
Tengo algunas dudas que si puedes me gustaria aclarases.
1-Tenéis algún grupo en telegram?
2-tengo sdm120 + Módulo TTL a RS485(xy-017)+ esp2866. Con lo que consigo que la info que aporta el sdm la paso a home assistant mediante mqtt. Puedo usar esto para conectarlo a freeds?
Un saludo muchas gracias por tu gran aporte.

vacarisses, 2020-03-15:
Hola,
el topic freeds/cmnd/pwmman a 0 para poner el PWM en AUTO no funciona, podrias poner un listado de topics.

Gracias

pablozg, 2020-03-15:
Gracias por el aviso, ya está solucionado, en cuanto pueda subo la nueva versión que será la 1.0.3.

Un poco más arriba puse el listado de comandos mqtt actuales, pero te los vuelvo a poner aquí, si creéis necesario alguno más indicarlo.

````
freeds/cmnd/pwm -> Acepta 1 para encender y 0 para apagar
freeds/cmnd/pwmman -> Acepta 1 para manual y 0 para auto
freeds/cmnd/pwmmanvalue -> Acepta valores de 0 a 100 que corresponde al % en modo manual
freeds/cmnd/screen -> Acepta valores de 0 a 4 corresponden a las pantallas de información en el oled
freeds/cmnd/pwmfrec -> Acepta valores entre 0 y 3000 corresponde a la frecuencia pwm
freeds/cmnd/brightness -> Acepta valores de 0 a 100 % corresponde al brillo de la pantalla
````

vacarisses, 2020-03-15:
Perfecto!!! Gracias, para mi con eso ya puedo automatizar en homeassistant, por otro lado, como puntalización ayer monte el ESP01 y en la web, no aparece que hay que puentearlo para que funcione, hasta que no lo hice no me funciono, solo como dato.

Gracias por tu proyecto y por tu ayuda

lito333, 2020-04-01:
Hola amigo gran trabajo.
Yo no puedo conectarlo porque el inversor que tengo es un easun power 5kw y no esta en la lista,pero tengo el icc solar que tiene mqtt.
mi pregunta es no se puede conectar mediante mqtt al icc solar,si es asi hay algun manual o alguna guia,
gracias y un saludo

Closed 2020-05-02.

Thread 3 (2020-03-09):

Vale, pero además de enviar el pwm con valor, el tema lo debes escribir tú, ya que si no lo indicas no hay forma de saber a quien enviarlo.

altusis1, 2020-03-09:
Vale, pero además de enviar el pwm con valor, el tema lo debes escribir tú, ya que si no lo indicas no hay forma de saber a quien enviarlo.

Ok, lo tengo en cuenta y pensaré como integrarlo.

_Originally posted by @pablozg in https://github.com/pablozg/freeds/issues/1#issuecomment-596253783_

altusis1, 2020-03-09:
hola pablozg. Lo primero agradecerte en trabajo que estas haciendo pra que podamos utilizar esta maravilla de programa.
Si es posible me gustaria podrías solucionar una duda que tengo.
Tengo un sdm120 + un convertidor serie  a 485 + un esp 8266. Con ello lo que consigo es enviar los datos del sdm 120 medianto mqtt a home assistant.
Puedo hacer que freeds recoja estos datos?

pablozg, 2020-03-09:
Hola, lo puedes hacer sin problema, sólo tienes que usar tasmota que tiene soporte para el sdm y mqtt, eliges la opción solax mqtt y configuras como tema del meter tudispositivo\tele\SENSOR, con eso debe conectarse y obtener datos del meter. También debes bajar la velocidad de publicación de tasmota a 10 segundos.

altusis1, 2020-03-09:
muchas gracias ahora lo pruebo

altusis1, 2020-03-09:
perdona no consigo que enlace.

Esta es mi configuración del sdm 120.
Host ()
192.168.2.50
Port (1883)
1883
Client (DVES_CAECB6)
DVES_%06X
User (DVES_USER)
test1
Password
••••
Topic = %topic% (sonoff)
SDM_120
Full Topic (%prefix%/%topic%/)
%prefix%/%topic%/

y esto lo que le envió a home assistan

19:32:30 MQT: tele/SDM_120/SENSOR = {"Time":"2020-03-09T19:32:30","ENERGY":{"Total":2180.327,"ActivePower":1203,"ApparentPower":1225,"ReactivePower":-246,"Frequency":50,"Factor":0.98,"Voltage":231,"Current":5.400,"PhaseAngle":0.00,"ImportActivePower":2142,"ExportActivePower":38,"ImportReactivePower":37,"ExportReactivePower":625,"TotalReactivePower":662}}

Configuración freeds:
monitorizacion - solax mqtt (tasmota)
configuración -

DATOS MQTT
MQTT Activado
MQTT Broker:
192.168.2.50
MQTT Usuario:
test1
MQTT Password:
•••••
MQTT Puerto:
1883
Tema R1:
freeds/relay/1/STATUS
Tema R2:
freeds/relay/2/STATUS
Tema R3:
freeds/relay/3/STATUS
Tema R4:
freeds/relay/4/STATUS
Tema Solax:
tele/PZEM004T/SENSOR         **meter midiendo aporte solar**
Tema Meter:
tele/SDM_120/SENSOR           **meter midiendo entrada acometida**
CAMBIO DE PASSWORD
Clave de acceso:
Nueva clave de acceso:
API REMOTA
Web Api:

altusis1, 2020-03-09:
puede crear conflicto por estar enlazo a home assistant?

altusis1, 2020-03-09:
perdona otro dato importante no tengo todavía el esp32 con la pantalla y estoy utilizando uno normal sin pantalla el esp32 devkit v1

altusis1, 2020-03-09:
veo que me esta cogiendo la energía diaria solar del pzem. Aunque el valor aparece y desaparece.

Error en la recepción de los datos de medida
Monitorización
Potencia solar:
0.00 W
Potencia de red:
0.00 W
Energía diaria solar:
1.77 KWH
Potencia string 1:
0.00 W (0.00 V) (0.00 A)
Potencia string 2:
0.00 W (0.00 V) (0.00 A)
PWM (AUTO):

que coincide con lo leido hoy por el pzem

PZEM004T_V3 Module
Pzem004T

Voltage | 231 V
Energy Today 0.030 A
Energy Today 0 W
Energy Today 7 VA
Power Factor 7 VAr
Power Factor 0.00
Power Factor 50 Hz
Energy Today  1.775 kWh
Power Factor 1.179 kWh
Power Factor 162.459 kWh

pablozg, 2020-03-10:
Buenos días, he subido la release 1.0.1 donde se corrige el fallo en la obtención de los datos mediante mqtt, pruébalo y me comentas.

altusis1, 2020-03-10:
Buenas tardes muchas gracias por tu dedicación y esfuerzo.
he subido los firmware.bin y spiffs.bin atravas de la web como indicas.
veo que la versión ahora es la
Copyright © 2020. Derivador de energía solar excedente 1.0.1
Basado en openDS+ de Iqas, betatester: Aeizoon, (C) 2020 Pablo Zerón
Fecha compilación: Mar 10 2020 11:47:46

y después de ello sigo con el mismo problema.

Error en la recepción de los datos de medida
Monitorización
Potencia solar:
38.00 W
Potencia de red:
0.00 W
Energía diaria solar:
2.37 KWH
Potencia string 1:
0.00 W (0.00 V) (0.00 A)
Potencia string 2:
0.00 W (0.00 V) (0.00 A)
PWM (AUTO):

no recoge la lectura del sdm120. pero si la del pzem.
esta es la confi que tengo puesta.

Configuración
DATOS MQTT
MQTT Activado
MQTT Broker:
192.168.2.50
MQTT Usuario:
test1
MQTT Password:
•••••
MQTT Puerto:
1883
Tema R1:
freeds/relay/1/STATUS
Tema R2:
freeds/relay/2/STATUS
Tema R3:
freeds/relay/3/STATUS
Tema R4:
freeds/relay/4/STATUS
Tema Solax:
tele/PZEM004T/SENSOR
Tema Meter:
tele/SDM_120/SENSOR
CAMBIO DE PASSWORD
Clave de acceso:
Nueva clave de acceso:
API REMOTA
Web Api:
CONFIGURACIÓN PANTALLA OLED
Apagado autómatico de la pantalla desactivado
Tiempo para apagado automático (ms):
30000
CONFIGURACIÓN METER
Baud rate:
9600
Meter Id:
1
TIEMPO MÁXIMO DE ERROR
Tiempo máximo de error (ms):
20000
TIEMPO DE ADQUISICIÓN DE DATOS
Tiempo adquisición datos (ms):
1500

si invierto de esta manera

Tema Solax:
tele/SDM_120/SENSOR
Tema Meter:
tele/PZEM004T/SENSOR

aparece y desaparece el Error en la recepción de los datos de medida
Potencia solar:
0.00 W
Potencia de red:
-18.00 W                  esta media es la producción de los paneles solares que es positiva POWER 18W pero la convierte en negativa

Energía diaria solar:
0.00 KWH
Potencia string 1:
0.00 W (0.00 V) (0.00 A)
Potencia string 2:
0.00 W (0.00 V) (0.00 A)
PWM (AUTO):
17 %
SAL

no se donde puede estar el error ?

Si necesitas que realice algún tipo de prueba me comentas.
Un saludo y gracias por tu tiempo y dedicación.

altusis1, 2020-03-10:
se me olvida , si dejo solo el pzem no monitoriza nada

Tema Solax:
tele/PZEM004T/SENSOR
Tema Meter:

si añado
Tema Solax:
tele/PZEM004T/SENSOR
Tema Meter:
ddsu666/
o
tele/SDM_120/SENSOR

entonces recoge datos del pzem pero no quiere los del sdm120
Potencia solar:
10.00 W
Potencia de red:
0.00 W
Energía diaria solar:
2.38 KWH

pablozg, 2020-03-10:
Fijate en tu log de tasmota y en el mío:

Tu log:
````
tele/SDM_120/SENSOR = {"Time":"2020-03-09T19:32:30","ENERGY":{"Total":2180.327,"ActivePower":1203,"ApparentPower":1225,"ReactivePower":-246,"Frequency":50,"Factor":0.98,"Voltage":231,"Current":5.400,"PhaseAngle":0.00,"ImportActivePower":2142,"ExportActivePower":38,"ImportReactivePower":37,"ExportReactivePower":625,"TotalReactivePower":662}}
````

Mi log sdm120:
````
 Casa/PB/sdm120/tele/SENSOR = {"Time":"2020-03-10T19:18:20","ENERGY":{"TotalStartTime":"2020-03-06T10:10:01","Total":[2765.851,1951.085,2012.301],"Yesterday":13.198,"Today":9.491,"ExportActive":[551.061,185.302,365.759],"Period":2.93,"Power":367.50,"ApparentPower":391.41,"ReactivePower":139.30,"Factor":0.93,"Frequency":50.00,"Voltage":229.3,"Current":1.80,"ImportActive":2765.852,"ImportReactive":592.294,"ExportReactive":76.662,"PhaseAngle":0.00}}
````

Mi log ddsu666:
````
Casa/PB/ddsu666/tele/SENSOR = {"Time":"2020-03-10T19:21:27","ENERGY":{"TotalStartTime":"2020-03-09T00:00:00","Total":[2768.080,42310.609,3406.769],"Yesterday":4.660,"Today":3.860,"ExportActive":[953.010,662.020,290.990],"Period":0,"Power":429,"ApparentPower":475,"ReactivePower":161,"Factor":0.91,"Frequency":50,"Voltage":231,"Current":2.057}}
````

Si te das cuenta en los míos se reporta el valor de consumo de energía como "Power", que es el valor que leo en el derivador, por lo que creo que tienes una versión antigua de tasmota (yo tengo la 8.1.0.2), primero prueba a actualizarla y me comentas.

Respecto a que el valor desaparece es un acción programada, ya que una vez que supera el tiempo indicado sin leer el valor del meter resetea los valores a 0 y comienza de nuevo la cuenta.

Un saludo.

altusis1, 2020-03-10:
actualizado a la Tasmota 8.1.0 by Theo Arends y funciona lo tenea en la 6.6 . muchas gracias. 👍 fantástico, ............. que guay cundo funciona todo. bueno me queda cambiarlo en home assistant

Potencia solar:
0.00 W
Potencia de red:
-2302.00 W
Energía diaria solar:
2.38 KWH
Potencia string 1:
0.00 W (0.00 V) (0.00 A)
Potencia string 2:

o porque es negativa la potencia de red , no tendria que ser + puesto que entra de la acometida a casa

pablozg, 2020-03-10:
Viene heredado del firmware original de iqas y se ha mantenido por
compatibilidad y para no liar a las personas que usan opends+ y quieren
pasar a freeds.

El mar., 10 mar. 2020 20:33, altusis1 <notifications@github.com> escribió:

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

altusis1, 2020-03-10:
ok muchas gracias por la aclaración

Closed 2020-03-10.

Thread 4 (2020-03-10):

Reinicios con inversor Fronius

usuariokike, 2020-03-10:
Hola, gracias de antemano por vuestro trabajo, estoy probado el gestor con un inversor Fronius y se reinicia constantemente, con el IQUAS no ocurre, no se si a alguien más le ocurre.

pablozg, 2020-03-10:
Hola, necesito más datos para valorar que puede ocurrir, necesito saber si sale algún mensaje en la Pantalla y si tienes opción de conectar el esp32 al ordenador y abrir un monitor serie (por ejemplo el que viene en el ide de arduino) con una velocidad de 115200bps para poder ver exactamente donde da el fallo.

Antes probaría si no lo has hecho ya, a borrar primero el esp32 antes de subir el nuevo firmware.

Cuando tengas el log del puerto serie lo añades en el mensaje y así puedo hacerme una idea de lo que pasa.

Gracias.

usuariokike, 2020-03-10:
Hola, es lo que he podido capturar del monitor serie.

CPU0 reset reason: Vbat power on reset
CPU1 reset reason: for APP CPU, reseted by PRO CPU

Testing EEPROM Library

EEPROM Size: 1028 bytes
[D][WiFiGeneric.cpp:337] _eventCallback(): Event: 0 - WIFI_READY
[WiFi-event] event: [D][WiFiGeneric.cpp:337] _eventCallback(): Event: 2 - STA_START
2
0
Connecting to Wi-Fi...
[I][WiFiMulti.cpp:84] addAP(): [WIFI][APlistAdd] add SSID: HOME
[E][WiFiMulti.cpp:55] addAP(): [WIFI][APlistAdd] no ssid or ssid too long
[D][WiFiGeneric.cpp:337] _eventCallback(): Event: 1 - SCAN_DONE
[WiFi-event] event: 1
[I][WiFiMulti.cpp:114] run(): [WIFI] scan done
[I][WiFiMulti.cpp:119] run(): [WIFI] 2 networks found
[D][WiFiMulti.cpp:151] run():        0: [11][C0:25:E9:7B:4A:6A] Home_2 (-79) *
[D][WiFiMulti.cpp:149] run():  --->   1: [1][44:D4:37:3F:7A:39] HOME (-82) *
[I][WiFiMulti.cpp:160] run(): [WIFI] Connecting BSSID: 44:D4:37:3F:7A:39 SSID: HOME Channal: 1 (-82)
[D][WiFiGeneric.cpp:337] _eventCallback(): Event: 7 - STA_GOT_IP
[D][WiFiGeneric.cpp:381] _eventCallback(): STA IP: 192.168.1.159, MASK: 255.255.255.0, GW: 192.168.1.1
7
WiFi connected
IP address:
192.168.1.159
[D][WiFiGeneric.cpp:337] _eventCallback(): Event: 7 - STA_GOT_IP
[D][WiFiGeneric.cpp:381] _eventCallback(): STA IP: 192.168.1.159, MASK: 255.255.255.0, GW: 192.168.1.1
7
WiFi connected
IP address:
192.168.1.159
[I][WiFiMulti.cpp:174] run(): [WIFI] Connecting done.
[D][WiFiMulti.cpp:175] run(): [WIFI] SSID: HOME
[D][WiFiMulti.cpp:176] run(): [WIFI] IP: 192.168.1.159
[D][WiFiMulti.cpp:177] run(): [WIFI] MAC: 44:D4:37:3F:7A:39
[D][WiFiMulti.cpp:178] run(): [WIFI] Channel: 1

WiFi connected
SSID:
HOME
IP address:
192.168.1.159
[D][WiFiGeneric.cpp:337] _eventCallback(): Event: 1 - SCAN_DONE
[WiFi-event] event: 1
HOME
Home_2
Welcome to FreeDS
Hostname: freeds_cbdc
mDNS responder started
[V][HTTPClient.cpp:235] beginInternal(): url: http://192.168.1.181/solar_api/v1/GetPowerFlowRealtimeData.fcgi
[D][HTTPClient.cpp:276] beginInternal(): host: 192.168.1.181 port: 80 url: /solar_api/v1/GetPowerFlowRealtimeData.fcgi
[D][HTTPClient.cpp:1025] connect():  connected to 192.168.1.181:80
[V][HTTPClient.cpp:1123] handleHeaderResponse(): RX: 'HTTP/1.1 200 OK'
[V][HTTPClient.cpp:1123] handleHeaderResponse(): RX: 'Content-Type: application/json'
[V][HTTPClient.cpp:1123] handleHeaderResponse(): RX: 'Cache-Control: no-cache, no-store, must-revalidate'
[V][HTTPClient.cpp:1123] handleHeaderResponse(): RX: 'Pragma: no-cache'
[V][HTTPClient.cpp:1123] handleHeaderResponse(): RX: 'Expires: 0'
[V][HTTPClient.cpp:1123] handleHeaderResponse(): RX: 'Transfer-Encoding: chunked'
[V][HTTPClient.cpp:1123] handleHeaderResponse(): RX: 'Date: Tue, 10 Mar 2020 18:27:52 GMT'
[V][HTTPClient.cpp:1123] handleHeaderResponse(): RX: 'Server: webserver'
[V][HTTPClient.cpp:1123] handleHeaderResponse(): RX: ''
[D][HTTPClient.cpp:1158] handleHeaderResponse(): code: 200
[D][HTTPClient.cpp:1165] handleHeaderResponse(): Transfer-Encoding: chunked
[D][HTTPClient.cpp:797] writeToStream():  read chunk len: 918
[D][HTTPClient.cpp:1295] writeToStreamDataBlock(): connection closed or file end (written: 918).
[D][HTTPClient.cpp:797] writeToStream():  read chunk len: 0
[D][HTTPClient.cpp:361] disconnect(): still data in buffer (2), clean up.

[D][HTTPClient.cpp:368] disconnect(): tcp keep open for reuse

[D][HTTPClient.cpp:368] disconnect(): tcp keep open for reuse

[V][HTTPClient.cpp:235] beginInternal(): url: http://192.168.1.181/solar_api/v1/GetPowerFlowRealtimeData.fcgi
[D][HTTPClient.cpp:276] beginInternal(): host: 192.168.1.181 port: 80 url: /solar_api/v1/GetPowerFlowRealtimeData.fcgi
[D][HTTPClient.cpp:991] connect(): already connected, reusing connection
[V][HTTPClient.cpp:1123] handleHeaderResponse(): RX: 'HTTP/1.1 200 OK'
[V][HTTPClient.cpp:1123] handleHeaderResponse(): RX: 'Content-Type: application/json'
[V][HTTPClient.cpp:1123] handleHeaderResponse(): RX: 'Cache-Control: no-cache, no-store, must-revalidate'
[V][HTTPClient.cpp:1123] handleHeaderResponse(): RX: 'Pragma: no-cache'
[V][HTTPClient.cpp:1123] handleHeaderResponse(): RX: 'Expires: 0'
[V][HTTPClient.cpp:1123] handleHeaderResponse(): RX: 'Transfer-Encoding: chunked'
[V][HTTPClient.cpp:1123] handleHeaderResponse(): RX: 'Date: Tue, 10 Mar 2020 18:27:53 GMT'
[V][HTTPClient.cpp:1123] handleHeaderResponse(): RX: 'Server: webserver'
[V][HTTPClient.cpp:1123] handleHeaderResponse(): RX: ''
[D][HTTPClient.cpp:1158] handleHeaderResponse(): code: 200
[D][HTTPClient.cpp:1165] handleHeaderResponse(): Transfer-Encoding: chunked
[D][HTTPClient.cpp:797] writeToStream():  read chunk len: 918
[D][HTTPClient.cpp:1295] writeToStreamDataBlock(): connection closed or file end (written: 918).
[D][HTTPClient.cpp:797] writeToStream():  read chunk len: 0
[D][HTTPClient.cpp:361] disconnect(): still data in buffer (2), clean up.

[D][HTTPClient.cpp:368] disconnect(): tcp keep open for reuse

[D][HTTPClient.cpp:368] disconnect(): tcp keep open for reuse

[V][HTTPClient.cpp:235] beginInternal(): url: http://192.168.1.181/solar_api/v1/GetPowerFlowRealtimeData.fcgi
[D][HTTPClient.cpp:276] beginInternal(): host: 192.168.1.181 port: 80 url: /solar_api/v1/GetPowerFlowRealtimeData.fcgi
[D][HTTPClient.cpp:991] connect(): already connected, reusing connection
[V][HTTPClient.cpp:1123] handleHeaderResponse(): RX: 'HTTP/1.1 200 OK'
[V][HTTPClient.cpp:1123] handleHeaderResponse(): RX: 'Content-Type: application/json'
[V][HTTPClient.cpp:1123] handleHeaderResponse(): RX: 'Cache-Control: no-cache, no-store, must-revalidate'
[V][HTTPClient.cpp:1123] handleHeaderResponse(): RX: 'Pragma: no-cache'
[V][HTTPClient.cpp:1123] handleHeaderResponse(): RX: 'Expires: 0'
[V][HTTPClient.cpp:1123] handleHeaderResponse(): RX: 'Transfer-Encoding: chunked'
[V][HTTPClient.cpp:1123] handleHeaderResponse(): RX: 'Date: Tue, 10 Mar 2020 18:27:55 GMT'
[V][HTTPClient.cpp:1123] handleHeaderResponse(): RX: 'Server: webserver'
[V][HTTPClient.cpp:1123] handleHeaderResponse(): RX: ''
[D][HTTPClient.cpp:1158] handleHeaderResponse(): code: 200
[D][HTTPClient.cpp:1165] handleHeaderResponse(): Transfer-Encoding: chunked
[D][HTTPClient.cpp:797] writeToStream():  read chunk len: 918
[D][HTTPClient.cpp:1295] writeToStreamDataBlock(): connection closed or file end (written: 918).
[D][HTTPClient.cpp:797] writeToStream():  read chunk len: 0
[D][HTTPClient.cpp:361] disconnect(): still data in buffer (2), clean up.

[D][HTTPClient.cpp:368] disconnect(): tcp keep open for reuse

[D][HTTPClient.cpp:368] disconnect(): tcp keep open for reuse

[V][HTTPClient.cpp:235] beginInternal(): url: http://192.168.1.181/solar_api/v1/GetPowerFlowRealtimeData.fcgi
[D][HTTPClient.cpp:276] beginInternal(): host: 192.168.1.181 port: 80 url: /solar_api/v1/GetPowerFlowRealtimeData.fcgi
[D][HTTPClient.cpp:991] connect(): already connected, reusing connection
[V][HTTPClient.cpp:1123] handleHeaderResponse(): RX: 'HTTP/1.1 200 OK'
[V][HTTPClient.cpp:1123] handleHeaderResponse(): RX: 'Content-Type: application/json'
[V][HTTPClient.cpp:1123] handleHeaderResponse(): RX: 'Cache-Control: no-cache, no-store, must-revalidate'
[V][HTTPClient.cpp:1123] handleHeaderResponse(): RX: 'Pragma: no-cache'
[V][HTTPClient.cpp:1123] handleHeaderResponse(): RX: 'Expires: 0'
[V][HTTPClient.cpp:1123] handleHeaderResponse(): RX: 'Transfer-Encoding: chunked'
[V][HTTPClient.cpp:1123] handleHeaderResponse(): RX: 'Date: Tue, 10 Mar 2020 18:27:56 GMT'
[V][HTTPClient.cpp:1123] handleHeaderResponse(): RX: 'Server: webserver'
[V][HTTPClient.cpp:1123] handleHeaderResponse(): RX: ''
[D][HTTPClient.cpp:1158] handleHeaderResponse(): code: 200
[D][HTTPClient.cpp:1165] handleHeaderResponse(): Transfer-Encoding: chunked
[D][HTTPClient.cpp:797] writeToStream():  read chunk len: 918
[D][HTTPClient.cpp:1295] writeToStreamDataBlock(): connection closed or file end (written: 918).
[D][HTTPClient.cpp:797] writeToStream():  read chunk len: 0
[D][HTTPClient.cpp:361] disconnect(): still data in buffer (2), clean up.

[D][HTTPClient.cpp:368] disconnect(): tcp keep open for reuse

[D][HTTPClient.cpp:368] disconnect(): tcp keep open for reuse

[V][HTTPClient.cpp:235] beginInternal(): url: http://192.168.1.181/solar_api/v1/GetPowerFlowRealtimeData.fcgi
[D][HTTPClient.cpp:276] beginInternal(): host: 192.168.1.181 port: 80 url: /solar_api/v1/GetPowerFlowRealtimeData.fcgi
[D][HTTPClient.cpp:991] connect(): already connected, reusing connection
[V][HTTPClient.cpp:1123] handleHeaderResponse(): RX: 'HTTP/1.1 200 OK'
[V][HTTPClient.cpp:1123] handleHeaderResponse(): RX: 'Content-Type: application/json'
[V][HTTPClient.cpp:1123] handleHeaderResponse(): RX: 'Cache-Control: no-cache, no-store, must-revalidate'
[V][HTTPClient.cpp:1123] handleHeaderResponse(): RX: 'Pragma: no-cache'
[V][HTTPClient.cpp:1123] handleHeaderResponse(): RX: 'Expires: 0'
[V][HTTPClient.cpp:1123] handleHeaderResponse(): RX: 'Transfer-Encoding: chunked'
[V][HTTPClient.cpp:1123] handleHeaderResponse(): RX: 'Date: Tue, 10 Mar 2020 18:27:58 GMT'
[V][HTTPClient.cpp:1123] handleHeaderResponse(): RX: 'Server: webserver'
[V][HTTPClient.cpp:1123] handleHeaderResponse(): RX: ''
[D][HTTPClient.cpp:1158] handleHeaderResponse(): code: 200
[D][HTTPClient.cpp:1165] handleHeaderResponse(): Transfer-Encoding: chunked
[D][HTTPClient.cpp:797] writeToStream():  read chunk len: 918
[D][HTTPClient.cpp:1295] writeToStreamDataBlock(): connection closed or file end (written: 918).
[D][HTTPClient.cpp:797] writeToStream():  read chunk len: 0
[D][HTTPClient.cpp:361] disconnect(): still data in buffer (2), clean up.

[D][HTTPClient.cpp:368] disconnect(): tcp keep open for reuse

[D][HTTPClient.cpp:368] disconnect(): tcp keep open for reuse

[V][HTTPClient.cpp:235] beginInternal(): url: http://192.168.1.181/solar_api/v1/GetPowerFlowRealtimeData.fcgi
[D][HTTPClient.cpp:276] beginInternal(): host: 192.168.1.181 port: 80 url: /solar_api/v1/GetPowerFlowRealtimeData.fcgi
[D][HTTPClient.cpp:991] connect(): already connected, reusing connection
[V][HTTPClient.cpp:1123] handleHeaderResponse(): RX: 'HTTP/1.1 200 OK'
[V][HTTPClient.cpp:1123] handleHeaderResponse(): RX: 'Content-Type: application/json'
[V][HTTPClient.cpp:1123] handleHeaderResponse(): RX: 'Cache-Control: no-cache, no-store, must-revalidate'
[V][HTTPClient.cpp:1123] handleHeaderResponse(): RX: 'Pragma: no-cache'
[V][HTTPClient.cpp:1123] handleHeaderResponse(): RX: 'Expires: 0'
[V][HTTPClient.cpp:1123] handleHeaderResponse(): RX: 'Transfer-Encoding: chunked'
[V][HTTPClient.cpp:1123] handleHeaderResponse(): RX: 'Date: Tue, 10 Mar 2020 18:27:59 GMT'
[V][HTTPClient.cpp:1123] handleHeaderResponse(): RX: 'Server: webserver'
[V][HTTPClient.cpp:1123] handleHeaderResponse(): RX: ''
[D][HTTPClient.cpp:1158] handleHeaderResponse(): code: 200
[D][HTTPClient.cpp:1165] handleHeaderResponse(): Transfer-Encoding: chunked
[D][HTTPClient.cpp:797] writeToStream():  read chunk len: 918
[D][HTTPClient.cpp:1295] writeToStreamDataBlock(): connection closed or file end (written: 918).
[D][HTTPClient.cpp:797] writeToStream():  read chunk len: 0
[D][HTTPClient.cpp:361] disconnect(): still data in buffer (2), clean up.

[D][HTTPClient.cpp:368] disconnect(): tcp keep open for reuse
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

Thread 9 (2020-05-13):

Modbus Victron

avm162, 2020-05-13:
Hola Pablo,
No se si lo tienes reportado. Al usar los datos Modbus del Victron, me da un error en el Unit id 288 en la instancia 239( en errores del modbus del del CCGX. Gran trabajo.
Gracias.

pablozg, 2020-05-13:
Hola, lo primero necesito que actualices a la última versión, tienes que borrarlo y graba todo de nuevo, ya que han habido numerosos cambios.

Cuando lo hayas hecho dime si te sigue saliendo el error.

Gracias.

https://github.com/pablozg/freeds/releases/download/1.0.5/FreeDS_Pre1.0.5Rev7.zip

avm162, 2020-05-13:
Sigue igual. De hecho el id 239 corresponde al VE.Direct por usb. Normalmente se consulta los valores principales en el id 100. No se si ahí puede estar el fallo.

pablozg, 2020-05-13:
Hola, el victron está así porque otro usuario estuvo haciendo pruebas y lo dejamos funcionando con esos valores.

Del id 239 obtengo:
 Frecuencia (red), potencia (red), voltaje (batería), intensidad (batería) y temperatura.

y del id 100 la potencia de las baterías.

Mándame un privado por alguno de los grupos de telegram de solares o solax. y te mando una versión sacando los datos desde el id 100, ¿puedes enviarme que instancias tienes disponibles en tu victron?

metragi, 2020-05-20:
Hola, yo tengo el mismo problema que avm162. No tengo ninguno de estos grupos de telegrama pero si me dejas enlace te mando la lista de ids que permite de un Excel de victron y las instancias que tengo disponibles, que también tengo un Carlo gavazzi. Gracias y un saludo

pablozg, 2020-05-20:
> Hola, yo tengo el mismo problema que avm162. No tengo ninguno de estos grupos de telegrama pero si me dejas enlace te mando la lista de ids que permite de un Excel de victron y las instancias que tengo disponibles, que también tengo un Carlo gavazzi. Gracias y un saludo

Hola, en principio este problema ya está solucionado, en breve sacaré de nuevo la revisión 8 donde estará funcionado. Si aún así tuvieras alguna pega me lo dices.

Gracias

Closed 2020-05-30.

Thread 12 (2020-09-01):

HomeAssistant

rdaguerre, 2020-09-01:
Hola, como estas? te felicito por este proyecto.
Tengo un mpp solar 5048gk y lo conecte por MQTT (usando ned-kelly/docker-voltronic-homeassistant) y después de ardua lucha pude hacer que mandara al servidor. Después eso si fácilmente me quedo conectado con HomeAssistant.
Debido a que tengo todos los datos ahí tanto ahora lo del inversor como el consumo a la red (por un esphome sonoff pow R1 tambien en HA)
Estaria bueno poder sacar los datos de consumo de la carga y consumo hacia la red (y temperatura) desde un servidor mqtt …
Si tenes alguna idea de como hacerlo te agradezco
Saludos
muy amable

Ronnie

pablozg, 2020-09-02:
Hola, no uso HomeAssitant, por lo que no te puedo ayudar, pero si puedo añadir a los parámetros que publica mediante mqtt, el consumo de la carga (debes saber que es estimado ya que freeds no soporta la medición de la carga mediante pinza), ya que el consumo de red ya lo indica en el valor "wgrid" donde negativo es que está consumiendo y positivo es que está vertiendo, igual que la temperatura del inversor que es publicada en el valor "invtemp".

Siento no poder ayudarte más.

rdaguerre, 2020-09-10:
Capaz que no me explique bien. En vez de que el consumo venga por el RS485 o el inversor o etc... que el freeds lo saque de una publicacion en un servidor mqtt. Esto permitiria que todos que no sea compatible lo pueda leer de ahi y ahi si que trabaje normalmente. No se si me explique? saludos y muy amable, saludos

pablozg, 2020-09-14:
Hola eso ya lo hace usando la opción tasmota mqtt, los datos los extrae de una publicación json como la siguiente, siempre la puedes replicar con nodered o similar y elegir esa opción.

Meter:

````
Casa/PB/sdm230/tele/SENSOR = {"Time":"2020-09-14T14:54:56","ENERGY":{"TotalStartTime":"2020-05-27T21:00:58","Total":2183.985,"TotalTariff":[986.462,1197.499],"Yesterday":8.521,"Today":3.552,"ExportActive":1470.398,"ExportTariff":[512.002,958.178],"Period":1.96,"Power":2172.84,"ApparentPower":2178.72,"ReactivePower":-51.48,"Factor":1.00,"Frequency":50,"Voltage":225.6,"Current":9.68,"ImportActive":1634.135,"ImportReactive":577.035,"ExportReactive":46.551,"PhaseAngle":358.63}}
````

En el caso del meter solo necesitas crear el valor 'power' dentro de ENERGY.

Solar:
````
Casa/PB/solaxX1/tele/SENSOR = {"Time":"2020-09-14T14:58:17","ENERGY":{"TotalStartTime":"2020-09-14T14:56:07","Total":5855.4,"TotalTariff":[14638.5,20284.6],"Yesterday":17.4,"Today":6.2,"Period":0.00,"Power":2591.00,"ApparentPower":2631.12,"ReactivePower":457.70,"Factor":0.98,"Frequency":50.00,"Voltage":230.8,"Current":11.40,"SolarPower":2712.50,"Pv1Voltage":176.4,"Pv1Current":8.00,"Pv1Power":1411.20,"Pv2Voltage":185.9,"Pv2Current":7.00,"Pv2Power":1301.30,"Temperature":50.0,"Runtime":5631,"Status":"Working","Error":0},"TempUnit":"C"}
````

Closed 2021-02-14.

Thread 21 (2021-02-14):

Homeassistant

tfael, 2021-02-14:
Hola, algún plan de desarrollar una integración en Homeassistant?

pablozg, 2021-02-14:
Hola, en estos momentos estoy liado con temas de trabajo y estoy ultimando la última versión que voy a publicar antes de centrarme en el trabajo y serán unos dos o tres meses en los que sólo tocaré el proyecto para temas urgentes.

Respecto a HA no creo que vaya a desarrollar ninguna implementación a no ser que alguien lo haga por su cuenta, ya que uso Domoticz en su lugar y como te digo ahora mismo no tengo demasiado tiempo libre, pero te animo a que lo intentes tú directamente.

Un saludo.

jorgestima, 2021-09-28:
I'm also using HA and indeed, it would be great to have some integration. For example, if just two things were possible to integrate in HA as ON/OFF button and target power value, that would be really good.

fizcris, 2021-09-28:
Hi,

I have started to do the integration here [aquí](https://github.com/fizcris/home-assistant-freeds).

But since then I have found [MQTT discovery](https://www.home-assistant.io/docs/mqtt/discovery/), whit this there is no need anymore for a has integration as if MQTT discovery is included in the ESP32 all the sensors would be automatically available in hassio as long as they are using the same broker.

pablozg, 2021-09-28:
> I'm also using HA and indeed, it would be great to have some integration. For example, if just two things were possible to integrate in HA as ON/OFF button and target power value, that would be really good.

Hi, I suggest you to suscribe to the [Telegram Channel](https://t.me/freeds_es) and ask for the HA integration, I think someone it has done.

You can use a 'POST' message to freeDS to switch ON/OFF with http://FREEDSIP/tooglebuttons?data=6
And switch it between AUTO / MAN with http://FREEDSIP/tooglebuttons?data=7

Or use mqtt as fizcris said, in the future we can integrate MQTT discovery topics.

jorgestima, 2021-09-28:
I know that MQTT is a possibility and very powerfull but more complicated to configure. As only recently I've entered in HA world, it is not easy for me to configure that. So, if a simple tool in HACS would be available, for me it would be great.

jorgestima, 2021-09-28:
Many thanks @fizcris

I will have a look on that. I already have all that data because I have my Goodwe solar inverter communicating using GoodWe Inverter Solar Sensor UDP installed by HACS.

What I was really looking for was to turn ON/OFF the excess power compensation and adjust the target power value using HA. Therefore, I could program and interact with all my other devices in just one single monitoring/control platform.

Do you have any idea on how this could be made in HA?

fizcris, 2021-09-29:
Hi,

That's not possible to do at the moment for any third party app regarding
an Goodwe inverter as we are still understanding how to change the
registers of the inverter using inverse engineering.

I think it will be available shortly as most of the protocol is understood
now but I suggest you to join the discord group of the Goodwe integration
to follow/assist with the development of such avanced features.

Regards

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

jorgestima, 2021-09-29:
Well, I think that I didn't explain correctly. The idea is not to change or interact with inverter. What I was saying is putting HA sending commands to MCU/FreeDS to turn ON/OFF the excess power compensation and adjust the target power value.

So, you already sent the code to read values from MCU using MQTT in HA. What would be the code to send command to turn ON/OFF compensation and change target power value?

IvanSanchez, 2023-04-07:
Hi, folks,

I've found out that setting up MQTT is a bit too fiddly, so in the end I've created a HASS integration that relies on the `http://$ip/events` endpoint - values available at that endpoint are automatically exposed as HASS sensors.

It may be buggy at the moment, and can only handle one FreeDS in the same network (because of #82), but the basics work.

See https://gitlab.com/IvanSanchez/homeassistant-freeds

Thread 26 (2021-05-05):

Placa de potencia

Moradventure, 2021-05-05:
Hola.
Soy nuevo por aquí, en primer lugar felicitar a los desarrolladores por este proyecto.
Planteo mi problema por si a alguien le ha sucedido antes. Tengo configurado Freeds, con la visualización web correcta y corriendo la rutina correctamente, modificando los parámetros y con la lectura de consumo desde un medidor SDM 120, la lógica de control de escedente en la visualización funciona correctamente.
Sin embargo en la placa de potencia, alimentada a 230v, en la salida me da permanentemente 230v en vacío, 0v si le conecto la resistencia del termo electrico de 1500w y 20v si le conecto una bombilla. No consigo tener alimentacion ni regulación al termo. No se si la placa de potencia viene mala o algo estoy haciendo yo mal. La placa de potencia es la Tindie.
Agradezco cualquier comentario.
Un saludo.

pablozg, 2021-05-05:
Hola, este repositorio es sólo para mantener el código, no se da soporte a los problemas de funcionamiento desde aquí.

Por eso te recomiendo que entres al grupo oficial de Telegram usando el siguiente enlace y formules allí tu consulta.

https://t.me/freeds_es

Saludos.

Closed 2021-05-05.

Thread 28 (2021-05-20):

Errores en la compilación y en la ejecución

fjsalc, 2021-05-20:
Hola, estoy tratando de hacer algunas pequeñas modificaciones, pero la verdad, es que me está resultando imposible porque de partida no va bien, lo que me hace sospechar que las librerías que se utilizan, o no están actualizadas, o bien no son con las que realmente se compilan finalmente con el programa. Voy a explicar paso a paso los errores con los que me he ido encontrando.

1. Me he bajado la versión PID como aconseja @pablozg, y sin hacer ningún cambio intento compilarla en **platformio**. Primer error: no compila porque dice que no encuentra el archivo _**preprocessor.hpp**_ de la librería **ArduinoJson**. Lo busco, y efectivamente, no está. Para resolverlo actualizo la librería a la última versión, que sí trae dicho archivo. Problema resuelto, ahora ya compila por completo **FreeDS**.
2. Cuando paso el programa al **wifi kit 32** y empieza a ejecutarse, por el terminal aparece un error: "_**Error al analizar el archivo de lenguajes**_". No parece un error importante porque permite que se siga ejecutando el programa.
3. Lo peor viene ahora. Consigo conectarme vía wifi al AP creado FreeDS, aunque en el display no aparece el texto "**_Conectarse al   SSID_**" ni la IP a la que conectarse. De todos modos me puedo conectar a la web en la IP 192.168.1.4, selecciono la wifi de mi casa o la del inversor, y no conecta con ninguna de las dos. Aparece el mensaje en el display de "**_WIFI ERROR_**". Y en el terminal conectado a platformio aparece ésto:
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

Agradecería que alguien pudiera echarme una mano en este punto en el que ya no veo una posible solución. Espero hacer una pequeña contribución al proyecto.

Gracias

pablozg, 2021-05-20:
Hola, efectivamente ArduinoJson no viene incluido en el repositorio, respecto a los textos, debes compilar el fichero spiffs.bin y subirlo también al esp32.

Primero lo compilas desde la consola de platformio con  `pio run -t buildfs`
Y luego lo subes con `pio run -t uploadfs`

Sobre el error al conectar puede ser por señal o por la clave que tenga el ssid, pero dudo mucho que sea problema de compilación.

También decirte que la versión subida al repositorio no está totalmente actualizada, ahora mismo estoy liado con temas de trabajo, pero en un mes o así ya podré retomar de nuevo el proyecto.

¿Qué cambios quieres hacer?

Saludos.

fjsalc, 2021-05-21:
Gracias @pablozg.

He compilado y subido el fichero **_spiffs_**.bin y ahora los mensajes aparecen correctamente en el display. Sin embargo, sigo teniendo problemas con las conexión a las wifi. He probado varias veces  y siempre da el mismo error, el que puse en el mensaje anterior. Por supuesto no es problema de la contraseña, e incluso para probar si es problema de hardware, he subido al ESP32 los binarios de la versión PID y funcionan correctamente, se conectan a las wifi. Por eso sigo pensando que es un problema de versiones de librerías wifi o algo así.

Lo que quiero hacer es que dé la posibilidad de tener en cuenta la compensación por horas. Todo el que tiene compensación de excedentes reconocido por la comercializadora y distribuidora, se le hace primero una compensación dentro de cada hora, donde los Kwh vertidos se compensan con los consumidos. Este el mejor modo de rentabilizar los KWh que produce tu instalación solar. Por ello, sería interesante que el freeds calculara el balance de Kwh vertidos y consumidos en cada hora para no activar el consumo de las salidas o del derivador si en la hora que corre se ha consumido más de lo que se ha vertido. Como esta situación viene bien sólo en determinadas circunstancias, habría que poner un interruptor en la web para decidir si se activa o no este modo.
 Yo tengo hecho ya los cambios en los fuentes para hacer la contabilidad de este balance por horas y hacer que se pare o activen las salidas y el derivador. Lo único que me queda es buscarle un sitio en el display para mostrar cuál es este balance en cada momento y el activar o desactivar este modo de funcionamiento en la web.  Si quieres te paso lo que he hecho o lo subo como un fork para que puedas utilizarlo y no te calientes mucho la cabeza, aunque no es muy difícil.

pablozg, 2021-05-23:
Hola he actualizado el código fuente a la versión que tengo actualmente y he subido un archivo .zip con las librerias tal y como las tengo yo en mi sistema.

Prueba a compilar con las librerías que he subido, si te sigue fallando ya debe ser problema de configuración del platformio.

Respecto a los cambios, cuando lo tengas todo compilado y probado, crea un pull request para que me sea más sencillo comprobar los cambios y hacer los ajustes si fueran necesarios.

Gracias.

fjsalc, 2021-05-28:
Hola de nuevo. Bien parece que ahora va todo mejor. Compila sin problemas y pasa el código al ESP32. El único inconveniente es que yo tengo un Solax (no híbrido) y cuando lo conecto en modo local lee perfectamente los datos de producción y de consumo. Sin embargo, cuando lo conecto a través del ESP01 (no local), se conecta al inversor, pero ya no le llegan bien los parámetros. Parece como si no interpretara bien el vector de datos que le llega.

En el código fuente que subiste no está la fuente de los programas del ESP01, no? Si es así, te pediría que lo subieras también, o al menos el binario, porque para mí es más fácil hacer los cambios y correcciones sobre la conexión no local, es decir, usando el ESP01. (Por cierto, el ESP01 está bien porque funciona perfectamente con OpenDS en conexión no local)

Gracias.

pablozg, 2021-05-28:
El binario para el esp01 lo tienes en el zip de las releases: [https://github.com/pablozg/freeds/releases/download/1.0.7/FreeDS_1.0.7Rev2.zip](url)

Ten en cuenta que el binario del esp01 ya no es compatible con opends por eso no te lee los datos, en cuanto lo programes, tendrás que elegir en la configuración el ssid del solax para que lo envíe al esp01.

Si los datos no te salen de forma correcta prueba a enviar el comando "solaxVersion 2" desde la consola o "solaxVersion 3", el comando depende de la versión de solax que tengas.

fjsalc, 2021-05-29:
Gracias  @pablozg.

El comando era lo que faltaba. Ya puedo compilar y comprobar los cambios. Te aviso cuando los tenga subidas las modificaciones.

Closed 2021-08-23.

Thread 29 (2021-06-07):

Error conectar wifi solax v2 local

polcino, 2021-06-07:
Hola, buenas noches. Ante todo dar las gracias a pablozg y a la gente que esta trabajando en este proyecto.

No se si estoy haciendo algo mal, pero despues de seleccionar la wifi local del solax y meter la clave, el ESP32 reinicia y siempre me dices ERROR WIFI.

He probado con la 1.0.7 beta, la 1.0.7 Final y la 1.0.6 todas con el mismo resultado.

He cambiado la clave de la wifi local, mismo error, sin embargo a la wifi de casa si conecta bien.

No se si hago algo mal o es algun otro tipo de problema.

Saludos

xelect75, 2021-06-08:
Olá, parabens por todo o trabalho neste projecto.
Eu não consigo conectar na minha rede DHCP, dá sempre "Error Wifi"
quais são os requisitos para conectar correctamente numa rede wifi?
Obrigado,
Nelson

RoyGeova07, 2024-08-16:
Hola, todo esta bien

Closed 2021-11-18.

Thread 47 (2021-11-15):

Bug error WiFiMulti

ABarrosoG, 2021-11-15:
Con la placa HELTEC HTIT-WB32 (WIFI KIT 32), v2, no se puede conectar a la red wifi local, se abre la configuración de AP, se introducen los datos y este es el resultado de error en la versión FreeDS.1.1.0004.Beta, FreeDS_1.1.0.Beta, y también con la versión FreeDS_1.0.7Rev2.
Aunque si funciona con el binario de la versión FreeDS_1.0.7Rev1, pero el código fuente de la Rev1 no está publicado, solo están los de la Rev2.
```
/////inicio de ejemplo del loop en el terminal de arduino
..................[WiFi-event] event: 1
Time before enter in failsafe mode: 25 seconds
.[WiFi-event] event: 1
Time before enter in failsafe mode: 22 seconds
[E][WiFiMulti.cpp:187] run(): [WIFI] Connecting Failed (6).
.[W][WiFiGeneric.cpp:391] _eventCallback(): Reason: 8 - ASSOC_LEAVE
[WiFi-event] event: 5
WiFi lost connection
..................[WiFi-event] event: 1
Time before enter in failsafe mode: 25 seconds
.[WiFi-event] event: 1
Time before enter in failsafe mode: 22 seconds
[E][WiFiMulti.cpp:187] run(): [WIFI] Connecting Failed (6).
.[W][WiFiGeneric.cpp:391] _eventCallback(): Reason: 8 - ASSOC_LEAVE
[WiFi-event] event: 5
WiFi lost connection
..................[WiFi-event] event: 1
Time before enter in failsafe mode: 25 seconds
.[WiFi-event] event: 1
Time before enter in failsafe mode: 22 seconds
[E][WiFiMulti.cpp:187] run(): [WIFI] Connecting Failed (6).
.[W][WiFiGeneric.cpp:391] _eventCallback(): Reason: 8 - ASSOC_LEAVE
[WiFi-event] event: 5
WiFi lost connection
..................[WiFi-event] event: 1
Time before enter in failsafe mode: 25 seconds
.[WiFi-event] event: 1
Time before enter in failsafe mode: 22 seconds
[E][WiFiMulti.cpp:187] run(): [WIFI] Connecting Failed (6).
.[W][WiFiGeneric.cpp:391] _eventCallback(): Reason: 8 - ASSOC_LEAVE
[WiFi-event] event: 5
WiFi lost connection
..................[WiFi-event] event: 1
Time before enter in failsafe mode: 25 seconds
.[WiFi-event] event: 1
Time before enter in failsafe mode: 22 seconds
[E][WiFiMulti.cpp:187] run(): [WIFI] Connecting Failed (6).
.[W][WiFiGeneric.cpp:391] _eventCallback(): Reason: 8 - ASSOC_LEAVE
[WiFi-event] event: 5
WiFi lost connection
/////fin de ejemplo del loop
```
Esta es la salida del terminal por Visual Studio Code: (evidentemente he probado en todos los puntos de acceso pero no conecta a ninguno)
```
[WiFi-event] event: 1
[I][WiFiMulti.cpp:114] run(): [WIFI] scan done
[I][WiFiMulti.cpp:119] run(): [WIFI] 4 networks found
[D][WiFiMulti.cpp:149] run():  --->   0: [2][74:5D:29:4A:FE:6D] ElWifi (-46) *
[D][WiFiMulti.cpp:151] run():        1: [10][E4:4B:D6:1C:67:FC] OpenWrt (-72) *
[D][WiFiMulti.cpp:151] run():        2: [10][00:05:B8:77:10:9F] Bio (-81) *
[D][WiFiMulti.cpp:151] run():        3: [6][10:0D:B0:0A:B8:1C] OpenWrt (-87) *
[I][WiFiMulti.cpp:160] run(): [WIFI] Connecting BSSID: 74:9D:79:0A:FE:3D SSID: ElWifi Channel: 2 (-46)
[E][WiFiMulti.cpp:187] run(): [WIFI] Connecting Failed (6).
.[D][WiFiMulti.cpp:195] run(): [WIFI] delete old wifi config...
[D][WiFiMulti.cpp:198] run(): [WIFI] start scan
[D][WiFiGeneric.cpp:374] _eventCallback(): Event: 5 - STA_DISCONNECTED
[W][WiFiGeneric.cpp:391] _eventCallback(): Reason: 8 - ASSOC_LEAVE
WiFi lost connection
...[D][WiFiGeneric.cpp:374] _eventCallback(): Event: 1 - SCAN_DONE
[WiFi-event] event: 1
.[D][WiFiGeneric.cpp:374] _eventCallback(): Event: 1 - SCAN_DONE
[WiFi-event] event: 1
```

pablozg, 2021-11-16:
He grabado desde cero uno de mis esp32 y como puedes observar se conecta a la primera

```
20:00:56.395 -> ESP model ESP32-D0WDQ6, Revision 1, SDK version v3.3.5-1-g85c43024c, Core: 160Mhz, Xtal: 40Mhz, APB: 80Mhz, MAC Address: 24:6F:28:21:DD:30, Heap Size: 341472, Free Heap: 310072
20:00:56.395 -> Testing EEPROM Library
20:00:56.395 -> EEPROM Size: 2048 bytes
20:00:58.517 -> Configuration Not Found, initializing
20:01:00.540 -> DATA SAVED!!!!
20:01:00.633 -> Current language: es
20:01:00.680 -> CPU0 reset reason: Vbat power on reset
20:01:00.680 -> CPU1 reset reason: for APP CPU, reseted by PRO CPU
20:01:00.680 -> ESP reset reason: Reset due to power-on event
20:01:00.917 -> Local IP address: 192.168.4.1
20:01:00.917 -> SSID: FreeDS - 192.168.4.1
20:01:00.917 -> Hostname: freeds_dd30
20:01:06.652 -> SSID 0 - Invitados (100%, -28 dBm), BSSID: C6:AD:34:B7:64:E7
20:01:06.652 -> SSID 1 - Consolas (100%, -28 dBm), BSSID: C6:AD:34:B7:64:E8
20:01:06.652 -> SSID 2 - Isabella (100%, -30 dBm), BSSID: C4:AD:34:B7:64:E7
20:01:06.652 -> SSID 3 - Consolas (58%, -71 dBm), BSSID: 4A:8F:5A:80:8B:72
20:01:06.652 -> SSID 4 - Isabella (56%, -72 dBm), BSSID: 48:8F:5A:80:8B:71
20:01:06.652 -> SSID 5 - VegaFibra_EXT_402C2 (52%, -74 dBm), BSSID: B0:4E:26:C3:FC:94
20:01:06.652 -> SSID 6 - Invitados (50%, -75 dBm), BSSID: 4A:8F:5A:80:8B:71
20:01:06.652 -> SSID 7 - Consolas (44%, -78 dBm), BSSID: 4A:8F:5A:80:77:66
20:01:06.652 -> SSID 8 - Invitados (44%, -78 dBm), BSSID: 4A:8F:5A:80:77:65
20:01:06.698 -> SSID 9 - Isabella (42%, -79 dBm), BSSID: 48:8F:5A:80:77:65
20:01:06.698 -> SSID 10 - VegaFibra_EB49E_EXT (36%, -82 dBm), BSSID: 98:DA:C4:44:73:B3
20:01:06.698 -> SSID 11 - VegaFibra_325A2_EXT (26%, -87 dBm), BSSID: 40:3F:8C:A2:52:EA
20:01:06.698 -> SSID 12 - VegaFibra_EB49E (18%, -91 dBm), BSSID: E0:CC:7A:15:6D:2C
20:01:34.745 -> DATA SAVED!!!!, RESTARTING!!!!ets Jun  8 2016 00:22:57
20:01:35.311 ->
20:01:35.311 -> rst:0xc (SW_CPU_RESET),boot:0x13 (SPI_FAST_FLASH_BOOT)
20:01:35.311 -> configsip: 0, SPIWP:0xee
20:01:35.311 -> clk_drv:0x00,q_drv:0x00,d_drv:0x00,cs0_drv:0x00,hd_drv:0x00,wp_drv:0x00
20:01:35.311 -> mode:DIO, clock div:2
20:01:35.311 -> load:0x3fff0018,len:4
20:01:35.311 -> load:0x3fff001c,len:1044
20:01:35.311 -> load:0x40078000,len:10124
20:01:35.311 -> load:0x40080400,len:5828
20:01:35.311 -> entry 0x400806a8
20:01:36.868 -> ESP model ESP32-D0WDQ6, Revision 1, SDK version v3.3.5-1-g85c43024c, Core: 160Mhz, Xtal: 40Mhz, APB: 80Mhz, MAC Address: 24:6F:28:21:DD:30, Heap Size: 341328, Free Heap: 309176
20:01:36.868 -> Testing EEPROM Library
20:01:36.868 -> EEPROM Size: 2048 bytes
20:01:39.035 -> Current language: es
20:01:39.081 -> CPU0 reset reason: Software reset CPU
20:01:39.081 -> CPU1 reset reason: Software reset CPU
20:01:39.081 -> ESP reset reason: Software reset via esp_restart
20:01:41.194 -> [WiFi-event] event: 0
20:01:41.194 -> Time before enter in failsafe mode: 27 seconds
20:01:41.194 -> [WiFi-event] event: 2
20:01:41.194 -> Connecting to Wi-Fi...
20:01:43.359 -> [WiFi-event] event: 1
20:01:43.359 -> Time before enter in failsafe mode: 25 seconds
20:01:46.930 -> [WiFi-event] event: 4
20:01:46.930 -> [WiFi-event] event: 7
20:01:46.930 -> WiFi connected to IP address: 10.10.0.78
20:01:46.930 ->
20:01:49.048 -> Welcome to FreeDS
20:01:49.048 -> Hostname: freeds_dd30
20:01:49.048 -> mDNS responder started
20:01:49.095 -> Booting Relay 1 Forced Off
20:01:49.095 -> Booting Relay 2 Forced Off
20:01:49.095 -> Booting Relay 3 Forced Off
20:01:49.095 -> Booting Relay 4 Forced Off
20:01:49.095 -> Desactivando timer mqtt
20:01:50.041 -> ws[/uptime][1] connect
20:01:51.882 -> [WiFi-event] event: 1
20:01:51.882 -> SSID 0 - Isabella (100%, -28 dBm), BSSID: C4:AD:34:B7:64:E7
20:01:51.882 -> SSID 1 - Invitados (100%, -28 dBm), BSSID: C6:AD:34:B7:64:E7
20:01:51.882 -> SSID 2 - Consolas (100%, -29 dBm), BSSID: C6:AD:34:B7:64:E8
20:01:51.882 -> SSID 3 - Consolas (58%, -71 dBm), BSSID: 4A:8F:5A:80:8B:72
20:01:51.882 -> SSID 4 - Invitados (58%, -71 dBm), BSSID: 4A:8F:5A:80:8B:71
20:01:51.882 -> SSID 5 - Isabella (58%, -71 dBm), BSSID: 48:8F:5A:80:8B:71
20:01:51.882 -> SSID 6 - VegaFibra_EXT_402C2 (52%, -74 dBm), BSSID: B0:4E:26:C3:FC:94
20:01:51.882 -> SSID 7 - Invitados (40%, -80 dBm), BSSID: 4A:8F:5A:80:77:65
20:01:51.882 -> SSID 8 - Consolas (38%, -81 dBm), BSSID: 4A:8F:5A:80:77:66
20:01:51.882 -> SSID 9 - Isabella (36%, -82 dBm), BSSID: 48:8F:5A:80:77:65
20:01:51.882 -> SSID 10 - VegaFibra_325A2_EXT (30%, -85 dBm), BSSID: 40:3F:8C:A2:52:EA
20:01:51.882 -> SSID 11 - VegaFibra_EB49E_EXT (24%, -88 dBm), BSSID: 98:DA:C4:44:73:B3
20:01:51.882 -> SSID 12 - VegaFibra_EB49E (16%, -92 dBm), BSSID: E0:CC:7A:15:6D:2C
```

Closed 2021-11-18.

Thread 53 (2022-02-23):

Battery SOC with Goodwe ES/EM

jorgestima, 2022-02-23:
In my case that I have a inverter Goodwe EM, the battery SOC value in FreeDS is wrong. For example, it shows 13568% when the real value is 53%. It seems that the shown value must be divided by 256 to get the corret SOC value.

Also, it shows the battery with negative power and providing power, which is wrong, because battery negative power means that it is charging.

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

pablozg, 2022-09-14:
Please, check with the last beta again.

ibm8999, 2022-10-04:
Buenas noches Pablo
Lo comenté por el grupo y te lo pongo por aquí también.
La beta 12 funcionando perfectamente en GoodWe.

Muchas gracias por tu trabajo
Un saludo
Paco

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

Closed 2022-10-12.

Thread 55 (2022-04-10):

Huawei RTU

epserra, 2022-04-10:
Gracias por el entorno.
Puedes para los que hemos perdido el modbus tcp de Huawei incluir la conexión de modbus-rtu a traves del conversor modbus ?
Gracias

diyeasy-es, 2022-08-03:
Hola, acabo de hacerle una modificación partiendo del branch PID que hay en el repositorio y parece que me está funcionando.

En mi caso tomé un ESP32 y le soldé el conversor modbus que recomiendan en la WEB siguiendo el diagrama de conexión de la web  http://freeds.es/img/WIFI%20Kit%2032.jpg

Despues conecté el pin 1 del conector del inversor (B) con el pin (B) del conversor modbus y el pin 2 del conector del inversor (A) con el pin (A) del conversor modbus. Si esos pines los hubiera usado tu instalador creo que podrias probar con el pin 3 y 4 y si los tuvieras libres

Adjunto los binarios por si los quieres probar y te funcionan... Supongo que tendrás que flashearlos por USB como indican en la web

[FreeDS_1.1.0010_ModHuaweiRTU.zip](https://github.com/pablozg/freeds/files/9252240/FreeDS_1.1.0010_ModHuaweiRTU.zip)

Muchas gracias a los desarrolladores por compartir las fuentes que me han permitido hacer la modificación. Copio y pego la función que he creado por si quieren incluirla en el release oficial

const uint16_t HuaweiRTU_start_addresses[] {
  37113,   // HUAWEI Wgrid (2)             [W]    0
  32114,   // HUAWEI Wtoday(2)             [W]    1
  32064,   // HUAWEI Wsolar(2)             [W]   2
  32016,   // HUAWEI PV1v (1)      [KVAR] 3
  32017,   // HUAWEI PV1c (1)               4
  32018,   // HUAWEI PV2v (1)           [Hz]   5
  32019,   // HUAWEI PV2c (1)       [kWh]  6
  32087,   // HUAWEI Temperature (1)       [kWh]  7
  37001,   // HUAWEI BatteryW (2)
};

void huaweiRTU(void)
{
  bool data_ready = modbusReceiveReady();

  if (data_ready) {
    uint8_t buffer[14];  // At least 5 + (2 * 2) = 9

    uint32_t error = modbusReceiveBuffer(buffer, 2);
 //   for(int i = 0; i<8;i++){Serial.print(buffer[i],HEX);Serial.print(" ");}
 //   Serial.println();

    if (error) {
      INFOV("HUAWEI RTU error: %i\n", error);
    } else {
      int32_t value32 = int32_t(
            (uint8_t)(buffer[3]) << 24 |
            (uint8_t)(buffer[4]) << 16 |
            (uint8_t)(buffer[5]) << 8 |
            (uint8_t)(buffer[6]));

      int16_t value16 = int16_t(
            (uint8_t)(buffer[3]) << 8 |
            (uint8_t)(buffer[4]));

      switch(meter.read_state) {
        case 0: //power_meter_active_power
          inverter.wgrid = (float)(value32 / 1.0); //Gain 1
          //Serial.print("power_meter_active_power: "); Serial.println(inverter.wgrid, 0);
          break;

        case 1: //daily_yield_energy
          inverter.wtoday = (float)(value32 / 100.0); //Gain 100
          //Serial.print("daily_yield_energy: "); Serial.println(inverter.wtoday,2);
          break;

        case 2: //input_power
          inverter.wsolar = (float)(value32 / 1.0); //Gain 1
          //Serial.print("input_power: "); Serial.println(inverter.wsolar,0);
          break;

        case 3://pv_01_voltage
          inverter.pv1v = (float)(value16 / 10.0); //Gain 10
          //Serial.print("pv_01_voltage: "); Serial.println(inverter.pv1v,1);
          break;

        case 4://pv_01_current
          inverter.pv1c = (float)(value16 / 100.0); //Gain 100
          //Serial.print("pv_01_current: "); Serial.println(inverter.pv1c,2);
          break;

        case 5://pv_02_voltage
          inverter.pv2v = (float)(value16 / 10.0); //Gain 10
          //Serial.print("pv_02_voltage: "); Serial.println(inverter.pv2v,1);
          break;

        case 6://pv_02_current
          inverter.pv2c = (float)(value16 / 100.0); //Gain 100
          //Serial.print("pv_02_current: "); Serial.println(inverter.pv2c,2);
          break;

        case 7: //internal_temperature
          inverter.temperature = (float)(value16 / 10.0); //Gain 10
          //Serial.print("internal_temperature: "); Serial.println(inverter.temperature,1);
          break;

        case 8: //storage_unit_1_charge_discharge_power
          inverter.batteryWatts = (float)(value32 / 1.0); //Gain 1
          //Serial.print("storage_unit_1_charge_discharge_power: "); Serial.println(inverter.batteryWatts,0);
          break;
      }

      meter.read_state++;

      // Error.VariacionDatos = false;
      Error.RecepcionDatos = false;
      timers.ErrorRecepcionDatos = millis();

      if (meter.read_state == 9) { // 8
        meter.read_state = 0;

        inverter.pw1 = inverter.pv1v * inverter.pv1c;
        inverter.pw2 = inverter.pv2v * inverter.pv2c;
      }
    }
  } // end data ready

  if (0 == meter.send_retry || data_ready) {
    meter.send_retry = 5;
    modbusSend(config.idMeter, 0x03, HuaweiRTU_start_addresses[meter.read_state], 2);
  } else {
    meter.send_retry--;
  }
}

pablozg, 2022-08-04:
@diyeasy-es El código que se encuentra en el repositorio no es el correspondiente a la Beta 10, contactame por telegram y te pasaré una versión de la última beta con la modificación que has hecho para que compruebes si funciona correctamente, así podré liberar una nueva versión con ese cambio.

crywolf87, 2022-10-03:
@pablozg Me ofrezco a probar el software modbus huawei y deja feedback de la operación si me permites probarlo, gracias

pablozg, 2022-10-04:
> @pablozg Me ofrezco a probar el software modbus huawei y deja feedback de la operación si me permites probarlo, gracias

Sólo tienes que bajarte la última beta disponible para probarlo.

Si no eres miembro del grupo de telegram puedes unirte mediante este enlace: https://t.me/freeds_es

geo99918, 2024-04-29:
Hi guys,
I'm also interested in the Modbus RTU version for Huawei, reason being that the Modbus TCP is not 100% stable.
Where do we get the Modbus RTU version to test it ?
Thank you.

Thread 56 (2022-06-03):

Heltec WiFi Kit 32 reboot loop after soldering pin headers

luisbarreto, 2022-06-03:
Hi Everyone,
First of all thank you for all the work around this excellent open source project!

I've been running the Heltec WiFi Kit 32 (v2) since the end of year 2021 just connected to an USB power source and my home wifi and internal MQTT.

Recently I started to have a little spare time to build my box.
After soldering the WiFi Kit 32 the pin headers, the connection to (previously configured) wifi keeps rebooting eventually connecting to the configured wifi about 5% of the time (at most).

When this occurred to the board I was using for several months without issues I thought the I could have bricked the board due to some short-circuit, excessive heat or something like that.
Since then I flashed the firmware (1.0.7 Final Rev 2) without pins soldered and after confirming everything was working I then soldered the pin headers to 4 additional wifi kits and all experience the same issue.

I consider myself pretty confident at soldering, used lower than I usually use soldering temperature (320ºC), as little solder as possible, nor short circuits and in the last boar I only soldered the pins to power, PWM, DS18B20 and external temporary switch.

If I let the boards turned on, they eventually connect to my wifi, but most of the time they just reboot time after time and are not connected.

at the console I get:

```
ets Jun  8 2016 00:22:57

rst:0x1 (POWERON_RESET),boot:0x17 (SPI_FAST_FLASH_BOOT)
configsip: 0, SPIWP:0xee
clk_drv:0x00,q_drv:0x00,d_drv:0x00,cs0_drv:0x00,hd_drv:0x00,wp_drv:0x00
mode:DIO, clock div:1
load:0x3fff0018,len:4
load:0x3fff001c,len:1044
load:0x40078000,len:10044
load:0x40080400,len:5900
entry 0x400806ac
Testing EEPROM Library
EEPROM Size: 2048 bytes
Current language: es
Connecting to Wi-Fi...
[I][WiFiMulti.cpp:84] addAP(): [WIFI][APlistAdd] add SSID: homeNetwork
[I][WiFiMulti.cpp:84] addAP(): [WIFI][APlistAdd] add SSID: MIWIFI2
[D][WiFiGeneric.cpp:374] _eventCallback(): Event: 0 - WIFI_READY
[WiFi-event] event: 0
[D][WiFiGeneric.cpp:374] _eventCallback(): Event: 2 - STA_START
[WiFi-event] event: 2
[D][WiFiGeneric.cpp:374] _eventCallback(): Event: 1 - SCAN_DONE
[WiFi-event] event: 1
[I][WiFiMulti.cpp:114] run(): [WIFI] scan done
[I][WiFiMulti.cpp:119] run(): [WIFI] 9 networks found
[D][WiFiMulti.cpp:151] run():        0: [11][xx:xx:xx:xx:xx:xx] homeNetwork_2 (-45) *
[D][WiFiMulti.cpp:149] run():  --->   1: [11][xx:xx:xx:xx:xx:xx] homeNetwork (-46) *
[D][WiFiMulti.cpp:151] run():        2: [11][xx:xx:xx:xx:xx:xx] REDACTED (-82) *
[D][WiFiMulti.cpp:149] run():  --->   3: [1][xx:xx:xx:xx:xx:xx] homeNetwork (-87) *
[D][WiFiMulti.cpp:151] run():        4: [1][xx:xx:xx:xx:xx:xx] REDACTED (-88) *
[D][WiFiMulti.cpp:151] run():        5: [1][xx:xx:xx:xx:xx:xx] REDACTED (-89)
[D][WiFiMulti.cpp:151] run():        6: [1][xx:xx:xx:xx:xx:xx] REDACTED (-90)
[D][WiFiMulti.cpp:151] run():        7: [11][xx:xx:xx:xx:xx:xx] REDACTED (-92) *
[D][WiFiMulti.cpp:151] run():        8: [11][xx:xx:xx:xx:xx:xx] REDACTED (-93) *
[I][WiFiMulti.cpp:160] run(): [WIFI] Connecting BSSID: xx:xx:xx:xx:xx:xx SSID: homeNetwork Channel: 11 (-46)
E (11625) wifi:Set status to INIT
[D][WiFiGeneric.cpp:374] _eventCallback(): Event: 5 - STA_DISCONNECTED
[W][WiFiGeneric.cpp:391] _eventCallback(): Reason: 203 - ASSOC_FAIL
[WiFi-event] event: 5
WiFi lost connection
[E][WiFiMulti.cpp:184] run(): [WIFI] Connecting Failed.
.[D][WiFiMulti.cpp:195] run(): [WIFI] delete old wifi config...
[D][WiFiMulti.cpp:198] run(): [WIFI] start scan
...[D][WiFiGeneric.cpp:374] _eventCallback(): Event: 1 - SCAN_DONE
[WiFi-event] event: 1
.[D][WiFiGeneric.cpp:374] _eventCallback(): Event: 1 - SCAN_DONE
[WiFi-event] event: 1
[I][WiFiMulti.cpp:114] run(): [WIFI] scan done
[I][WiFiMulti.cpp:119] run(): [WIFI] 11 networks found
[D][WiFiMulti.cpp:151] run():        0: [11][xx:xx:xx:xx:xx:xx] homeNetwork_2 (-47) *
[D][WiFiMulti.cpp:149] run():  --->   1: [11][xx:xx:xx:xx:xx:xx] homeNetwork (-47) *
[D][WiFiMulti.cpp:151] run():        2: [9][xx:xx:xx:xx:xx:xx] REDACTED (-77) *
[D][WiFiMulti.cpp:151] run():        3: [11][xx:xx:xx:xx:xx:xx] REDACTED (-84) *
[D][WiFiMulti.cpp:151] run():        4: [1][xx:xx:xx:xx:xx:xx] REDACTED (-87) *
[D][WiFiMulti.cpp:151] run():        5: [1][xx:xx:xx:xx:xx:xx] REDACTED (-88)
[D][WiFiMulti.cpp:151] run():        6: [1][xx:xx:xx:xx:xx:xx] REDACTED (-89)
[D][WiFiMulti.cpp:149] run():  --->   7: [1][xx:xx:xx:xx:xx:xx] homeNetwork (-89) *
[D][WiFiMulti.cpp:151] run():        8: [11][xx:xx:xx:xx:xx:xx] REDACTED (-92) *
[D][WiFiMulti.cpp:151] run():        9: [3][xx:xx:xx:xx:xx:xx] REDACTED (-93) *
[D][WiFiMulti.cpp:151] run():        10: [9][xx:xx:xx:xx:xx:xx] REDACTED (-94) *
[I][WiFiMulti.cpp:160] run(): [WIFI] Connecting BSSID: xx:xx:xx:xx:xx:xx SSID: homeNetwork Channel: 11 (-47)
[E][WiFiMulti.cpp:184] run(): [WIFI] Connecting Failed.
.[D][WiFiMulti.cpp:195] run(): [WIFI] delete old wifi config...
[D][WiFiMulti.cpp:198] run(): [WIFI] start scan
....[D][WiFiGeneric.cpp:374] _eventCallback(): Event: 1 - SCAN_DONE
[WiFi-event] event: 1
AP Not valid, Waiting 30 seconds before restart, press 'prg' button to defaults settings or 'rst' button to restart now
ets Jun  8 2016 00:22:57

rst:0x1 (POWERON_RESET),boot:0x17 (SPI_FAST_FLASH_BOOT)
configsip: 0, SPIWP:0xee
clk_drv:0x00,q_drv:0x00,d_drv:0x00,cs0_drv:0x00,hd_drv:0x00,wp_drv:0x00
mode:DIO, clock div:1
load:0x3fff0018,len:4
load:0x3fff001c,len:1044
load:0x40078000,len:10044
load:0x40080400,len:5900
entry 0x400806ac
Testing EEPROM Library
EEPROM Size: 2048 bytes
Current language: es
Connecting to Wi-Fi...
[I][WiFiMulti.cpp:84] addAP(): [WIFI][APlistAdd] add SSID: homeNetwork
[I][WiFiMulti.cpp:84] addAP(): [WIFI][APlistAdd] add SSID: MIWIFI2
[D][WiFiGeneric.cpp:374] _eventCallback(): Event: 0 - WIFI_READY
[WiFi-event] event: 0
[D][WiFiGeneric.cpp:374] _eventCallback(): Event: 2 - STA_START
[WiFi-event] event: 2
[D][WiFiGeneric.cpp:374] _eventCallback(): Event: 1 - SCAN_DONE
[WiFi-event] event: 1
[I][WiFiMulti.cpp:114] run(): [WIFI] scan done
[I][WiFiMulti.cpp:119] run(): [WIFI] 5 networks found
[D][WiFiMulti.cpp:151] run():        0: [11][xx:xx:xx:xx:xx:xx] homeNetwork_2 (-58) *
[D][WiFiMulti.cpp:149] run():  --->   1: [11][xx:xx:xx:xx:xx:xx] homeNetwork (-59) *
[D][WiFiMulti.cpp:151] run():        2: [11][xx:xx:xx:xx:xx:xx] REDACTED (-80) *
[D][WiFiMulti.cpp:151] run():        3: [9][xx:xx:xx:xx:xx:xx] REDACTED (-91) *
[D][WiFiMulti.cpp:151] run():        4: [4][xx:xx:xx:xx:xx:xx] REDACTED (-92) *
[I][WiFiMulti.cpp:160] run(): [WIFI] Connecting BSSID: xx:xx:xx:xx:xx:xx SSID: homeNetwork Channel: 11 (-59)
[D][WiFiGeneric.cpp:374] _eventCallback(): Event: 4 - STA_CONNECTED
[WiFi-event] event: 4
[D][WiFiGeneric.cpp:374] _eventCallback(): Event: 7 - STA_GOT_IP
[D][WiFiGeneric.cpp:419] _eventCallback(): STA IP: 1.1.1.82, MASK: 255.255.255.0, GW: 1.1.1.1
WiFi connected to IP address: 1.1.1.82
[I][WiFiMulti.cpp:174] run(): [WIFI] Connecting done.
[D][WiFiMulti.cpp:175] run(): [WIFI] SSID: homeNetwork
[D][WiFiMulti.cpp:176] run(): [WIFI] IP: 1.1.1.82
[D][WiFiMulti.cpp:177] run(): [WIFI] MAC: xx:xx:xx:xx:xx:xx
[D][WiFiMulti.cpp:178] run(): [WIFI] Channel: 11
Desactivando timer mqtt
[D][WiFiGeneric.cpp:374] _eventCallback(): Event: 1 - SCAN_DONE
[WiFi-event] event: 1
SSID 0 - wifi (92%, -54 dBm)
SSID 1 - wifi_2 (92%, -54 dBm)
SSID 2 - NOS-E736 (40%, -80 dBm)
SSID 3 - MEO-F255F0 (18%, -91 dBm)
SSID 4 - Vodafone-2EB31B (16%, -92 dBm)
SSID 5 - NOS-13B7 (12%, -94 dBm)
Welcome to FreeDS
Hostname: freeds_9c9c
mDNS responder started
Relay 1 Forced Off
Relay 2 Forced Off
Relay 3 Forced Off
Relay 4 Forced Off
ets Jun  8 2016 00:22:57
```

As I said FreeDS worked without issues for months before I soldered the pin headers.
This network has 2 Access Points for the whole house coverage as can be seen in the wifi scan.
It does not help to shut down one of those keeping only one in the spectrum...
I also tested with a really easy and simple WPA password in a new SSID homeNetwork_2, but it does not help either...

From the Access Point logs, I mostly get:

`xx:xx:xx:xx:xx:xx@wlan1: disconnected, extensive data loss, signal strength -55` (MAC Address of the WiFi 32 Kit)

This make me suspect that somehow I might be introducing some kind of interference when soldering the pin headers...

Any help or hint would be very appreciated.

Thanks

pablozg, 2022-06-04:
Hi, Please try first the last beta version https://github.com/pablozg/freeds/releases/download/1.1.0_Beta/FreeDS_1.1.0010_Beta.zip, because the Rev 2 is obsolete, if you still having issues then write here or you can use the official telegram channel at: https://t.me/freeds_es.

Thanks.

luisbarreto, 2022-06-09:
Hi Pablo,

Thanks for taking time answering me, mostly because this hardly seem to be a FreeDS specific software problem by itself...
I flashed the latest firmware Release 1.1.0010 Beta but the issue remains.
Considering this, the issue isn't probably not FreeDS related, so sorry for raising this issue here, you can close it anytime you want.

Even so I just want to share a little more on the subject.
The connection to the wifi network is poor and I consistently seed the message `disconnected, extensive data loss, signal strength -51` being logged on the Access Point logs.

I've been testing this issue with 4 Heltec WiFi Kit 32 with same results regardless the FreeDS version (tested 1.0.7 Final Rev 2 and 1.1.0010 Beta) or the board itself - all 4 suffer from the same wifi connectivity issue and this seems to be mainly a hardware/antenna design or at some extent might need some work at the wifi library level...
For the record, I was running one of these boards with FreeDS 1.0.7 Final Rev 2, for more than 4 months, without soldering their pin headers (fed by micro USB), without any noticeable problem. As soon as I soldered the pin headers, the wifi connectivity problems started.

Things already tested and their outcomes regarding the wifi connectivity of these boards:
Baseline for comprehension:
- 1 SSID with 2 APs (both Mikrotik haP AC2), basically wired connected bridges, to extend the wifi range;

- channels 1 and 11 used initially, one  on each AP. It seems that changing the AP on channel 11 to channel 6 might have improved (very) little - channel 11 seems more crowded by neighbors;
- change from 20/40 channel bandwidth to just 20 Mhz (only) does not seem to improve anything;
- change from G/N band to either G or N (only) does not seem to improve anything;
- powering from micro USB or +5V pin (low noise good quality adapter +5v 1A) doesn't seem to have any impact

Seems that the pin headers cause some kind of antenna or impedance problem that make this board very difficult to work with even on a relatively small house.
For contextual purposes, I have several wifi networked devices like ESP8266, Sonoff's and shellys, inside the walls, on a balcony at a higher distance from the nearest AP and none of these have had any connectivity issues for several years now.

A final question: would it be feasible to put together an ESP32 with a separate 0.96" OLED display for this purpose using the same codebase and libraries?

Thanks.

Closed 2022-09-14.

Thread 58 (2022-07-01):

What does the 'Inverter/LoadWatts' topic mean?

dml33, 2022-07-01:
Hi.

I am trying to publish via MQTT the set of topics related to the "ICC Solar MQTT" inverter type, as stated in the FreeDS manual:

```
Para dispositivo "ICC Solar MQTT".- Los topics son:
"Inverter/GridWatts" // Potencia de red
"Inverter/MPPT1_Watts" // Potencia string 1
"Inverter/MPPT2_Watts" // Potencia string 2
"Inverter/MPPT1_Volts" // Tension string 1
"Inverter/MPPT2_Volts" // Tension string 2
"Inverter/MPPT1_Amps" // Corriente string 1
"Inverter/MPPT2_Amps" // Corriente string 2
"Inverter/PvWattsTotal" // Potencia solar
"Inverter/SolarKwUse" // Energía diaria solar
"Inverter/BatteryVolts" // Voltaje batería
"Inverter/BatteryAmps" // Corriente bateria
"Inverter/BatteryWatts" // Potencia batería
"Inverter/BatterySOC" // Nivel batería
"Inverter/LoadWatts" // Consumo actual
"Inverter/Temperature" // Temperatura Inversor
```

What is exactly the "Inverter/LoadWatts" topic about? What is it used for?

Because, with that description, it would be equivalent to "Inverter/GridWatts", which is the current grid power (negative: taken from the grid; positive: exported to the grid).

Thanks for the clarification.

Best regards.

pablozg, 2022-07-04:
Hi, LoadWatts means the total amount of watts of the load connected to the inverted, if you have your whole house connected to the inverter, then you should put the total watts that the house is using.

GridWatts means the amount of watts exporting / importing from the grid.

dml33, 2022-07-05:
Thank you, Pablo.

Understood. It is the current total consumption of the house. In my case, since the inverter does not give it directly, I have to calculate it as (PvWattsTotal + BatteryWatts) - GridWatts.

Great!

Closed 2022-09-14.

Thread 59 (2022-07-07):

Toggle PWM without writting eeprom each time

jorgemiguel4, 2022-07-07:
I have been using freeds for a few weeks now coupled with home assistant and it's been great.  In Portugal we have a "quarter hour netmetering" period, to squeeze most of the solar energy sometimes I have to toggle PWM on/off every couple minutes or so.  My weblog looks like this:
11:45:00 - [Command] PWM control: ON
11:45:00 - [Eeprom] DATA SAVED!!!!
11:45:56 - [Command] PWM control: OFF
11:45:56 - [Eeprom] DATA SAVED!!!!
11:54:00 - [Command] PWM control: ON
11:54:00 - [Eeprom] DATA SAVED!!!!
11:54:06 - [Command] PWM control: OFF
11:54:06 - [Eeprom] DATA SAVED!!!!
11:55:02 - [Command] PWM control: ON
11:55:02 - [Eeprom] DATA SAVED!!!!
11:58:26 - [Command] PWM control: OFF
11:58:26 - [Eeprom] DATA SAVED!!!!

Is there a way to disable eeprom writes to preserve eeprom or is a non issue?

pablozg, 2022-07-07:
Hi,

It's not a problem because freeDS is receiving a manual instruction, so freeDS needs to save the actual state to avoid failure on a eventul power loss or reboot.

If you send the "pwm to shutdown" command, freeDS needs to know and store it, because if you restart or shutdown it, when it starts up it will be in the same operating mode before the restart or shutdown.

Maybe you should take a look at your hassio routine to avoid sending continuous on/off commands.

jorgemiguel4, 2022-07-07:
I already keep the current state to avoid some writes but it's hard to do better since I have to pause PWM to recover some energy after use of some devices that consume more than my solar production in the 15min interval. I would be nice to have a flag in the payload to make it permanent or volatile.

pablozg, 2022-10-04:
Hola, @jorgemiguel4, tu propuesta la he integrado para la siguente beta que publique, si quieres probarla únete al grupo de telegram: https://t.me/freeds_es y te la mando por privado.

El payload es así:
```
/*
	Payload
	0 PWM OFF Permanent
	1 PWM ON  Permanent
	2 PWM OFF Volatile
	3 PWM ON  Volatile
*/
```

Y el comando se envia a ``` nombre_de_host/cmnd ``` y en formato json: ``` {"command":"pwm","payload":"3"} ```

jorgemiguel4, 2022-10-04:
Muchas gracias @pablozg

svcabre, 2022-11-05:
Hola @jorgemiguel4 @pablozg,

Esta programación es realmente interesante para alargar la vida del ESP32. Podrías añadir esta opción de Volatile o Permanent también para PWM AUTO/MAN

pablozg, 2022-11-09:
> Hola @jorgemiguel4 @pablozg,
>
> Esta programación es realmente interesante para alargar la vida del ESP32. Podrías añadir esta opción de Volatile o Permanent también para PWM AUTO/MAN

Hola, efectivamente para la opción de cambio entre auto / man también está implementado, lo podrás probar en cuanto se publique la beta 13.

svcabre, 2022-11-12:
Hola @pablozg,

Acabo de actualizar mi ESP32 otra vez desde 0 usando el programarESP32.bat y he realizado las pruebas.

La implementación funciona correctamente para PWM ON o OFF

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

Pero en cambio para PWM MAN o AUTO me sigue apareciendo [Eeprom] DATA SAVED!!!!

20:23:27 - [Command] PWM control: OFF
20:23:30 - [Command] PWM control: ON
20:23:32 - [Command] PWM control: OFF
20:23:33 - [Command] PWM control: ON
20:23:47 - [Command] PWM mode set to: AUTO
20:23:47 - [Eeprom] DATA SAVED!!!!
20:23:49 - [Command] PWM mode set to: MANUAL
20:23:49 - [Eeprom] DATA SAVED!!!!
20:23:51 - [Command] PWM mode set to: AUTO
20:23:51 - [Eeprom] DATA SAVED!!!!
20:23:52 - [Command] PWM mode set to: MANUAL
20:23:52 - [Eeprom] DATA SAVED!!!!

Estoy utilizando MQTT y desde NodeRed mando los siguientes comandos:

Para AUTO {"command":"pwmman","payload":"2"}
Para MAN  {"command":"pwmman","payload":"3"}

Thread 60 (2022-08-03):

Compile freeds

jorgemiguel4, 2022-08-03:
What's the easiest way to compile freeds?

Thank you

pablozg, 2022-08-04:
Hi, The best way is use VSCODE + platformio, then open the folder and compile.

jorgemiguel4, 2022-08-04:
I'm trying to compile 1.1.0 beta but some libs are missing. Can you provide a package with everything?

In file included from lib/ArduinoJson/src/ArduinoJson/Collection/CollectionData.hpp:7,
                 from lib/ArduinoJson/src/ArduinoJson/Array/ArrayFunctions.hpp:7,
                 from lib/ArduinoJson/src/ArduinoJson/Array/ArrayRef.hpp:7,
                 from lib/ArduinoJson/src/ArduinoJson.hpp:17,
                 from lib/ArduinoJson/src/ArduinoJson.h:9,
                 from C:/Users/Jorge/Desktop/FreeDS Compile/freeds-1.1.0_Beta/freeds-1.1.0_Beta/src/FreeDS.ino:37:
lib/ArduinoJson/src/ArduinoJson/Namespace.hpp:8:10: fatal error: ArduinoJson/Polyfills/preprocessor.hpp: No such file or directory
 #include <ArduinoJson/Polyfills/preprocessor.hpp>
          ^~~~~~~~~~~~~~~~~~~~~~~~~~~~~~~~~~~~~~~~
compilation terminated.
*** [.pio\build\heltec_wifi_kit_32\src\FreeDS.ino.cpp.o] Error 1

diyeasy-es, 2022-08-04:
Hello, I had the same issue, but if you download the repository PID from https://github.com/pablozg/freeds you will find the lib.zip (I used this one and its working)

jorgemiguel4, 2022-08-09:
I'm still getting this:

lib/esp32ModbusTCP/src/esp32ModbusTCP.h:30:10: fatal error: FreeRTOS.h: No such file or directory

jorgemiguel4, 2022-08-16:
Can you share the entire folder please? Thank you

pablozg, 2022-08-16:
Freertos is part of the main framework and platformio must install it. I can't send you as a lib.

You can try to compile with arduino ide, but you have to install the esp32 framework and the libs from arduino library manager.

diyeasy-es, 2022-08-18:
Yes,

I think that is a framework version issue. Try to downgrade till Platform Espressif 32 v3.5.0

I think that new frameworks has embebed FreeRTOS, so you don't need the .h library

jorgemiguel4, 2022-08-18:
Downgrade Platformio IDE?

diyeasy-es, 2022-08-18:
No, in platform, only you need downgrade the espressif 32  platfrom

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

jorgemiguel4, 2022-08-18:
espressif32 downgrade did the trick. thank you very much

jorgemiguel4, 2022-08-18:
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

Can you share the new code here?

pablozg, 2022-09-14:
The new code will be available when it changes its status from beta to stable.

Could you say me what changes wants to do in the code?

jorgemiguel4, 2022-09-14:
Like a said in the other thread I started, I want to disable eeprom writes for pwm and pwmman mqtt commands. The way it's implemented in freeds it rewrites all the configuration everytime it receives a command and I'm  concerned about the longevity of ESP32 in my use case.

Closed 2022-10-12.

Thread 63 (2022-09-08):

Freeds browser error

alyn304, 2022-09-08:
Hello. can you tell me what I'm doing wrong or why after loading one of the 1.0.7 or 1.1.0011 versions I can no longer access the program either from the desktop browser or from the phone browser, version 1.0.6 works, only the ones mentioned above I'm having problems, I'm using an esp32 oled board. I am attaching pictures of the board I use and the error that appears in my browser. thanks a lot
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

pablozg, 2022-09-14:
Solved in telegram group, bad programming parameters.

Closed 2022-09-14.

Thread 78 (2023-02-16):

ESP32-S3

Rsalvador2008, 2023-02-16:
is this compatible with the freeds? how?

Amazon only send me the esp32 v3 (esp32-s3)

Mizuba74, 2023-02-28:
I'm having the same problem, do you found a solution?
Thanks!

Rsalvador2008, 2023-02-28:
I have swapped my esp32 s3 for the normal esp32-d0

-------- Mensagem original --------
De : Mizuba74 ***@***.***>
Data: 28/02/23 12:51 (GMT+00:00)
Para: pablozg/freeds ***@***.***>
Cc: Rsalvador2008 ***@***.***>, Author ***@***.***>
Assunto: Re: [pablozg/freeds] ESP32-S3 (Issue #78)

I'm having the same problem, do you found a solution?
Thanks!

—
Reply to this email directly, view it on GitHub<https://github.com/pablozg/freeds/issues/78#issuecomment-1448125618>, or unsubscribe<https://github.com/notifications/unsubscribe-auth/AITIZCLQKBO5JNQHFEUB5KTWZXYDFANCNFSM6AAAAAAU6CQL5M>.
You are receiving this because you authored the thread.Message ID: ***@***.***>

Mizuba74, 2023-02-28:
Do you by any chance have a link for the esp32-d0?

Rsalvador2008, 2023-02-28:
I have bought it in Portugal in the following store

https://www.botnroll.com/pt/arduino-controladores/2985-esp32-com-display-oled-128x64.html

Check with vendor first before place the order
-------- Mensagem original --------
De : Mizuba74 ***@***.***>
Data: 28/02/23 12:54 (GMT+00:00)
Para: pablozg/freeds ***@***.***>
Cc: Rsalvador2008 ***@***.***>, Author ***@***.***>
Assunto: Re: [pablozg/freeds] ESP32-S3 (Issue #78)

Do you by any chance have a link for the esp32-d0?

—
Reply to this email directly, view it on GitHub<https://github.com/pablozg/freeds/issues/78#issuecomment-1448130020>, or unsubscribe<https://github.com/notifications/unsubscribe-auth/AITIZCLPKNQKBXWXWOQSANDWZXYQHANCNFSM6AAAAAAU6CQL5M>.
You are receiving this because you authored the thread.Message ID: ***@***.***>

Goaheadz, 2023-06-20:
Any update how to program esp32-s3?
Its getting hard to find old versions.
I have bougth one and dont want to return it.

Goaheadz, 2023-06-21:
I tried to compile the source to esp32 V3, but theres alot of standard libraries missing.
It would not be hard for pablozg, to compile this for S3-V3, using "visual code source" free software.

Already sent back my esp32-S3-V3 to seller...Now I dont know what to buy :(

JohnnyPleasures, 2023-06-30:
https://www.amazon.es/-/pt/dp/B07RWHHJXT/ref=cfb_at_prodpg

Used this One. Works great using shelly EM

joanorsky, 2023-09-05:
So.. no solution for the S3 then?

pablozg, 2023-09-06:
> I tried to compile the source to esp32 V3, but theres alot of standard libraries missing. It would not be hard for pablozg, to compile this for S3-V3, using "visual code source" free software.
>
> Already sent back my esp32-S3-V3 to seller...Now I dont know what to buy :(

The problem with S3 is this chip version lost some need functionalities as Pin 25 and the analog output, so it's not a good replacement for esp32.

Rsalvador2008, 2023-09-06:
Just order the regular esp32 v1 version you should find some on Google, search for esp32 v1

Ricardo Salvador

-------- Mensagem original --------
De : pablozg ***@***.***>
Data: 06/09/23 21:01 (GMT+01:00)
Para: pablozg/freeds ***@***.***>
Cc: Rsalvador2008 ***@***.***>, Author ***@***.***>
Assunto: Re: [pablozg/freeds] ESP32-S3 (Issue #78)

I tried to compile the source to esp32 V3, but theres alot of standard libraries missing. It would not be hard for pablozg, to compile this for S3-V3, using "visual code source" free software.

Already sent back my esp32-S3-V3 to seller...Now I dont know what to buy :(

The problem with S3 is this chip version lost some need functionalities as Pin 25 and the analog output, so it's not a good replacement for esp32.

—
Reply to this email directly, view it on GitHub<https://github.com/pablozg/freeds/issues/78#issuecomment-1708930191>, or unsubscribe<https://github.com/notifications/unsubscribe-auth/AITIZCKJDIE4WOTR7OYJAPLXZDCATANCNFSM6AAAAAAU6CQL5M>.
You are receiving this because you authored the thread.Message ID: ***@***.***>

rjsbandeira, 2024-01-27:
Same problem here. Amazon send me the esp32-s3 version :/
any update?

Jocaberto, 2024-03-03:
Hello, I also have the same problem, is there any solution for ESP-S3?

AmshaSharam, 2025-06-25:
settings for  ESP32-S3-WROOM-1-N16R8
i didnt try with this code.

On platformio.ini :
; Flash: 16MB QD, PSRAM: 8MB OT
[env:esp32-s3-devkitc-1-n16r8]
platform = espressif32
board = esp32-s3-devkitc-1-n16r8v
framework = arduino

board_build.arduino.memory_type = qio_opi
board_build.flash_mode = qio
board_build.psram_type = opi
board_upload.flash_size = 16MB
board_upload.maximum_size = 16777216
board_build.partitions = default_16MB.csv
board_build.extra_flags =
-DBOARD_HAS_PSRAM

monitor_speed = 115200
monitor_port = COM4
upload_port = COM4
upload_speed = 921600

pablozg, 2025-06-27:
No es un problema de configuración en platformio, es un problema de hardware, el ESP32-S3 no dispone de pin 25 que es el necesario para controlar las cargas, por lo que no es un reemplazo directo.

IvanSanchez, 2025-06-27:
@pablozg Pero el S3 (incluídas los devkits de S3) tiene GPIOs de sobra (45 en total). Se podría definir el GPIO 25 para ESP32 y, por ejemplo, el GPIO 21 para ESP32S3. Es cuestión de pelearse con los `#ifdef`s y las variables de entorno que meta platformio.

Hasta donde alcanzo a ver, el factor de forma de los devkits de ESP32S3 es distinto de los devkits de ESP32, así que de todas maneras habría que diseñar una PCB distinta.

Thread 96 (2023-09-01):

ICC Solar (MQTT) / Error en la recepción de los datos de medida

cosygarcia, 2023-09-01:
He instalado recientemente el gestor freeds (hardware: gen9 / software: 1.1.0014 Beta BETA Build: 22112022).

Mi inversor (Solax X1 mini 3k) y mi panel eléctrico principal están alejados uno del otro, y no puedo tener un solo Shelly que mida la potencia solar generada y la potencia de la red. Transmito la potencia solar generada a Home Assistant consultando las API locales del inversor. Transmito la potencia de la red a Home Assistant a través del sensor Shelly 3EM.

He creado 2 triggers en Home Assistant:
- Uno que, cada vez que cambia el valor de la potencia solar generada, publica ese valor en mi broker MQTT en el topic "Inverter/PvWattsTotal".
- otro que, cada vez que cambia el valor de la potencia de la red, publica ese valor en mi broker MQTT en el topic "Inverter/GridWatts".

Finalmente, he configurado el gestor freeDS para utilizar una fuente de datos de tipo "ICC Solar (MQTT)". He configurado la conexión MQTT en freeDS.

La página de Monitorización muestra que el excedente se deriva hacia el termo durante unos segundos. Luego, obtengo el mensaje de error "Error en la recepción de los datos de medida" en la página de Monitorización. Al ir a la página de la consola/weblog, tengo los siguientes mensajes de error:
16:59:25 - PWM: Apagando PWM por superar el tiempo máximo en la variación de los datos del consumo de Red
16:59:58 - PWM: Apagando PWM por superar el tiempo máximo en la variación de los datos del consumo de Red
17:00:31 - PWM: Apagando PWM por superar el tiempo máximo en la variación de los datos del consumo de Red
17:01:04 - PWM: Apagando PWM por superar el tiempo máximo en la variación de los datos del consumo de Red

Cual es el problema ? Gracias de antemano

pablozg, 2023-09-06:
El problema es que el dato que recibe como valor de red no varia dentro del tiempo de espera antes de dar error, por defecto son 20 segundos, eso quiere decir que no varia su valor desde el ultimo recibido en ese margen de tiempo, aumenta ese valor, o modifica si puedes para que envie el valor de forma periodica con una pequeña variación, puede ser 0.01 a 0.09 watios de forma aleatoria si quieres para no influir en la decisión que toma freeds pero es suficiente para detectar un cambio en su valor.

cosygarcia, 2023-09-06:
He descubierto que Home Assistant solo recopila los valores del Shelly cada
30 segundos. Así que he creado un nuevo sensor "rest" que se actualiza cada
2 segundos. Parece funcionar mejor ahora.

Le mer. 6 sept. 2023 à 20:51, pablozg ***@***.***> a écrit :

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

articoweb, 2023-09-14:
@cosygarcia Una consulta, qué es eso de hardware Gen9? Sólo vi placas de solarhomer v1 y v2. Soy nuevo, disculpar que haga tan patente mi ignorancia.

pablozg, 2024-01-12:
> @cosygarcia Una consulta, qué es eso de hardware Gen9? Sólo vi placas de solarhomer v1 y v2. Soy nuevo, disculpar que haga tan patente mi ignorancia.

Siento haber leido tan tarde tu pregunta, el hardware Gen9 es el que suministra Francisco de Solares TV, decir que no tiene nada que ver con freeDS, tan solo es un miembro más que facilita hardware compatible tal y como hace solarhomer y otro usuarios, informate bien de los pros y contras de cada placa ya que existen varias versiones que usan tecnologia difente.

Puedes pasarte por el grupo de telegram si quieres estar más informado.

Closed 2024-04-03.

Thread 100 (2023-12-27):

MQTT issue

geo99918, 2023-12-27:
Hi all,

I'm trying to control the FreeDS from MQTT but the code for topic subscription seems to be incomplete in the version I have on the board:
"1.1.0018 Beta Build: 29072023 Web: 1.1.3" , not sure this is in sync with the public source code.

this is what I can observe on the mosquitto server:

```
1703681883: Received SUBSCRIBE from freeds_48e729a384c8
1703681883: 	freeds_84C8/cmnd (QoS 0)
1703681883: freeds_48e729a384c8 0 freeds_84C8/cmnd  // <- here the subscription is incomplete or different
1703681883: Sending SUBACK to freeds_48e729a384c8
```

the FreeDS is subscribing for the "freeds_84C8/cmnd" topic, but in the source code I can see the following:

```
  static char topics[][12] = **{"pwm","pwmman","pwmmanvalue","screen","pwmfrec","brightness","pwmvalue"};**

  int nTopics = sizeof(topics) / sizeof(topics[0]);
  for (int i = 0; i < nTopics; i++)
  {
    sprintf(tmpTopic, "%s/cmnd/%s", config.hostServer, topics[i]); // <- here we're subcsribing to multiple topics of format <freeds>/cmnd/pwm pwmman ...
    mqttClient.subscribe(tmpTopic, 0);
    INFOV("Suscribing to topic %s\n",tmpTopic);
  }

```

and if I publish on the expected topic as in the source code it does not get sent to the FreeDS as it's not something that it subscribes to

```
1703704595: New connection from 127.0.0.1:46916 on port 1883.
1703704595: New client connected from 127.0.0.1:46916 as auto-597E9E4F-488E-D8A7-AD7D-F583CB6FF6BE (p2, c1, k60).
1703704595: No will message specified.
1703704595: Sending CONNACK to auto-597E9E4F-488E-D8A7-AD7D-F583CB6FF6BE (0, 0)
1703704595: Received PUBLISH from auto-597E9E4F-488E-D8A7-AD7D-F583CB6FF6BE (d0, q0, r0, m0, 'freeds_84C8/cmnd/pwmman', ... (1 bytes))  //<- here published to topic as observed in the source code.
// no sending to freeds
1703704595: Received DISCONNECT from auto-597E9E4F-488E-D8A7-AD7D-F583CB6FF6BE
1703704595: Client auto-597E9E4F-488E-D8A7-AD7D-F583CB6FF6BE disconnected.
```

on the other side, I tried to make the INFOV function dump some information on the weblog by using "weblog 1" in the web console but nothing happens ....

also tried to build from source (Release 1.1.0018 Beta), uploaded to new board but I get a nasty esp32 crash dump when logging in

```
Guru Meditation Error: Core  1 panic'ed (LoadProhibited). Exception was unhandled.
Core 1 register dump:
PC      : 0x400d43fc  PS      : 0x00060730  A0      : 0x800fa478  A1      : 0x3ffe8120
A2      : 0x00000000  A3      : 0x3ffcf3e4  A4      : 0x3ffde290  A5      : 0x3ffe8090
A6      : 0x00000000  A7      : 0x3ffe4380  A8      : 0x800d43f9  A9      : 0x3ffe8100
A10     : 0x3ffe8130  A11     : 0x3f400d72  A12     : 0xa07a8b5a  A13     : 0x3ffcf3e4
A14     : 0x00000000  A15     : 0x3ffe813c  SAR     : 0x00000017  EXCCAUSE: 0x0000001c
EXCVADDR: 0x00000000  LBEG    : 0x400014fd  LEND    : 0x4000150d  LCOUNT  : 0xfffffffa

ELF file SHA256: 0000000000000000

Backtrace: 0x400d43fc:0x3ffe8120 0x400fa475:0x3ffe8170 0x400f80f1:0x3ffe81b0 0x400f81b9:0x3ffe81f0 0x400f840d:0x3ffe8240 0x400eb055:0x3ffe8260 0x400eb135:0x3ffe82a0 0x400eb839:0x3ffe82c0 0x4008a736:0x3ffe82f0

```
anyone can give a hint here ?

Thank you,
Geo

pablozg, 2023-12-28:
Actualmente el codigo de las betas es totalmente nuevo y por diversos motivos no es público, pero si libre de uso, para controlar por mqtt tienes que enviar un json con el comando y la carga, puedes consultarlo en la página 30 del manual:

https://docs.google.com/document/d/1-XLCqHEbpqEPi4geI4CbANmGxodExC__zDvND89xjIU/edit?usp=sharing

Saludos.

Closed 2024-04-03.

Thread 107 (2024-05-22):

Aislada con sistema Victron - Valor incorrecto en consumo bateria

fvpedro, 2024-05-22:
Hola, primero de todo quisiera agradecer a todos los involucrados y que mantienen este proyecto.

Descripción de la instalación:
-Sistema aislado con baterias.
-Modo de obtención datos Victron.
-Produccion solar a traves de Mppt Victron.
-Inverter 2x Multiplus-II 5000-70 en paralelo.
-Bmv 712 smart como monitor de barerias.
-Cerbo GX para la optencion de datos Modbus a FreeDS.
-Firmware instalado 1.1.0020 Beta.

Issue:
-Desde la actualizacion a esta version el parametro de "Consumo de bateria" aparece correcto segun mi monitor de baterias pero al segundo siguiente es como si sumara el dato de consumo/descarga que proporciona Victron mas la produccion solar en ese momento y asi sucesivamente. Eso hace que el PID control sea imposible.
 Adjunto capturas con un segundo de diferencia para mostrar el problema.
Gracias
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

fvpedro, 2024-05-22:
Solucionado insertando el comando useBmv 1 en la consola.

Closed 2024-05-22.

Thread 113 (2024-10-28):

Bug: "Failed to read term temperature from DS18B20 sensor" message and automatic control interruption

Csontikka, 2024-10-28:
Bug: "Failed to read term temperature from DS18B20 sensor" message and automatic control interruption
Version: 1.1.0020 Beta Build: 05042024 Web: 1.1.5
Hardware: PWM10A 2200W MOSFET Trailing Edge Dimmer + ESP32 with additional cooling (relay4)
Connected Temperature Sensor: DS18B20 (for measuring boiler temperature)

Description of the Issue:
On 2024-10-28 at 16:33, the error message "Failed to read term temperature from DS18B20 sensor" appeared in the console (see attached image), which led to the interruption of automatic PWM control. PWM was enabled in AUTO mode. Despite this error, I continued to receive real-time boiler temperature data in Home Assistant, suggesting that the issue was transient; however, it still resulted in a control shutdown.

Approximately 2 hours later, at 18:49, I noticed the issue and saved the configuration through the device’s web interface, which I believe restarted the internal processes. Following this, the device resumed operation immediately and has been running without issues since.

Interesting Observation:
While the DS18B20 error interrupted the automatic control, temperature data continued to update in Home Assistant. I suspect the error was temporary, yet it still blocked the system's operation. The device is equipped with additional cooling (relay4), so overheating could not have caused this issue.

Attached Images:
The attached images display the error messages in the console and the data from the two relevant sensors (boiler temperature and PWM percentage values).

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

Request:
I am looking for a solution that prevents a momentary sensor error from stopping the entire system. If a sensor occasionally gives a faulty reading, it should not lead to a complete control shutdown.

If you need any further information, please let me know!

Regards,
Csontikka

Csontikka, 2024-11-06:
The issue has recurred 9 days later. The device exhibited the exact same behavior as before, so I won't go into detail about the events. However, this suggests that the problem is not isolated but rather a recurring, systematic issue that requires further investigation.

Thank you in advance for taking the time to address this!

pablozg, 2024-11-06:
Hola, no especificas la configuración que tienes en el apartado de temperaturas para tratar de replicarlo, aunque en mi opinión no es un fallo como crees, lo más probable (al no disponer de tu configuración) es que la temperatura del termo estuviera dentro del rango configurado (por encima de los 50 grados en tu gráfica) por lo que una vez detenido por el fallo de lectura del termo, este no se pone a funcionar hasta que la temperatura esté por debajo del umbral de activación (vuelvo a repetir que no has puesto una captura de tu configuración), por lo que una vez hubiese llegado a esta temperatura se habría activado de nuevo hasta llegar a la temperatura de corte.

Saludos.

Csontikka, 2024-11-07:
Saludos,

I have taken multiple screenshots of the settings that seem relevant, which I have not modified since. The boiler's heating range was set between 30 and 70 degrees, and the temperature never approached these values. However, the previously recorded boiler temperature graph clearly shows that the control did not stop when reaching a specific temperature. The temperature remained unchanged when the PWM turned off.

Regards,
Csontikka

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

Csontikka, 2024-11-07:
Dear Pablozg,

This issue continues to concern me, so I took a detailed look at the error logs from November 6. I noticed one additional detail that might provide a useful clue for you.

The graphs clearly show that at the moment the error occurred, the status of the "FreeDS ojle Error" sensor briefly changed to "Problem."

Additionally, just a few minutes before the error, at the same temperature, the PWM was still switching correctly.

I've also taken a screenshot related to the specific time of the issue, which shows the status of the sensors. I hope this visual evidence, along with the details provided, can assist in identifying the problem.

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

I tried to annotate the screenshot as thoroughly as possible to highlight the key points.

Regards,
Csontikka

pablozg, 2024-11-09:
Hola,

Con la gráfica me estás dando la confirmación de lo que te indiqué en un principio, la temperatura antes de dar el error de sonda era de 44.5ºC, tu temperatura de activación es inferior a 30ºC.

Cuando da el error de temperatura el sistema se detiene, y una vez obtiene la temperatura de nuevo, como la temperatura actual del termo no es inferior a 30ºC no se activa de nuevo el gestor (esta es la programación establecida).

Si la temperatura del termo llegará a menos de 30ºC entonces volvería a activar el gestor hasta llegar a los 70ºC que tienes configurado.

Cuando reinicias el gestor o cambias la configuración se prioriza el entregar potencia hasta que se vuelvan a cumplir las condiciones.

En todo caso, trataré de pensar una forma para que en caso de dar error la sonda de temperatura, permita seguir calentando si no ha llegado a la temperatura de corte.

Saludos.

Csontikka, 2024-11-09:
Dear Pablozg,

Now I clearly understand the issue. The control stops due to the sensor error, and one of the conditions for it to restart (the "turn on temperature") is not met.

So, my workaround is simple: I will lower the "turn on temperature" value to 10°C, which will always be fulfilled. And of course, I’d be happy if a permanent solution can also be found.

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

Regards,
Csontikka

pablozg, 2024-11-10:
Hola, no has entendido correctamente como funciona el gestor, si colocas la temperatura de encendido a 10ºC no funcionará el gestor hasta que la temperatura del agua esté por debajo de 10ºC, debes aumentar la temperatura a por ejemplo a 45ºC, entonces cuando la temperatura del agua esté a 44.5ºC o menos entonces empezará a calentar hasta llegar a los 70ºC.

Otra opción es activar la opción de temperatura mínima, de forma que siempre tendrás el agua a esa temperatura (enciende a la temperatura conectada y para cuando la supera en 3ºC).

Saludos.

Csontikka, 2024-11-10:
Dear pablozg,

You are absolutely right. After I wrote my comment yesterday, I realized in the evening that what I wrote was nonsense. :)

I will try your suggestion. Thank you.

Regards,
Csontikka

pablozg, 2024-11-11:
Hola, por favor contacta conmigo mediante telegram y te pasaré una versión de prueba.
Saludos.

ruisilva93, 2025-04-05:
I’m having the same problem: it’s bellow the max temperature, the sensor gives an error and PWM stopes until a restart or about 2h. But I still that temperature visível through that sensor on freeds. But 0% power while have exceeding powers available. It’s clearly a bug. Might be hard to reproduce, but it’s happening for more than one.

I’m version .20 too.

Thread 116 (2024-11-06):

Feature Request: Configurable Minimum Run Time for Relay Outputs

Csontikka, 2024-11-06:
**Software:** FreeDS v1.1.0020 Beta Build: 05042024 Web: 1.1.5
**Hardware:** PWM10A 2200W MOSFET Trailing Edge Dimmer + ESP32 with additional cooling (relay4)
Connected Temperature Sensor: DS18B20 (for measuring boiler temperature)

**Description:** Currently, in my setup, I use the 4th relay output to control an external fan, which is configured to turn on when the PWM level exceeds 30%. While the system works as intended, I have noticed that frequent fluctuations around this threshold cause the fan to rapidly switch on and off. This behavior could shorten the fan's lifespan and even lead to operational issues for more significant loads.

Proposed Solution: I would like to request an additional setting in FreeDS to configure a minimum run time for each relay. This setting would ensure that once the relay output activates, the connected device (such as a fan) remains powered for a specified minimum duration before turning off, regardless of changes in the PWM level. Alternatively, another approach could be to implement a minimum switching interval, which would guarantee a minimum time between two consecutive state changes of the relay. Either option would mitigate issues caused by rapid toggling, providing operational stability and protecting connected devices from damage.

**Benefits:**

Protect Equipment: Extends the lifespan of connected devices by reducing wear from frequent on/off cycles.
Operational Stability: Ensures smoother operation by preventing excessive switching.
Versatile Configuration: Offers flexible settings per relay output to accommodate different equipment needs.
Example Use Case:

For a fan controlled by a relay, if the PWM level triggers the relay, the fan would run for a minimum of, say, 60 seconds, even if the PWM drops below the threshold. Alternatively, a minimum switching interval would ensure that the relay does not toggle again until a set time has elapsed.

Thank you for your efforts and contributions to the project and its development!
Regards,
Csontikka

pablozg, 2024-11-06:
Hola,

Las salidas ya poseen un retardo en el encendido y apagado que no se aplica a la salida 4 cuando está configurada como ventilador, lo añadiré a la lista TODO.

Saludos.

Csontikka, 2024-11-07:
Thank you for your positive response and for considering the suggestion! I'm glad to see it being added to the development list, and I’m confident it will enhance the system’s performance. I appreciate your prompt feedback!

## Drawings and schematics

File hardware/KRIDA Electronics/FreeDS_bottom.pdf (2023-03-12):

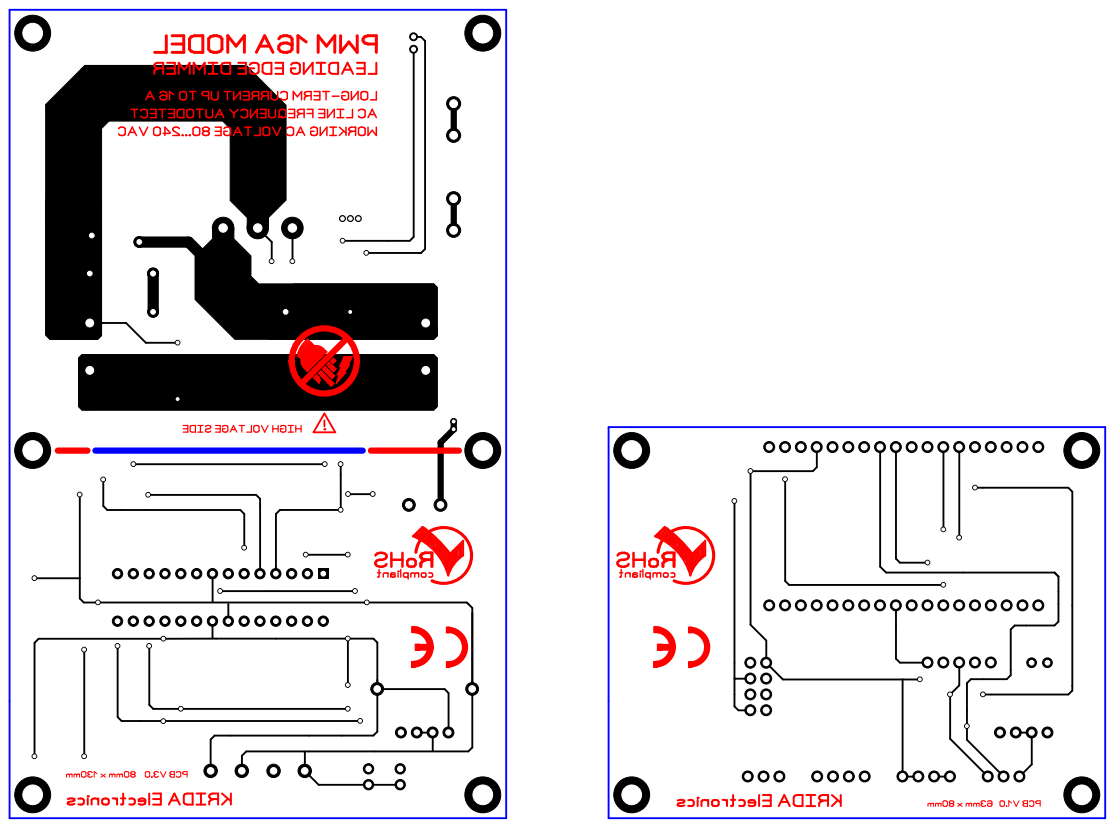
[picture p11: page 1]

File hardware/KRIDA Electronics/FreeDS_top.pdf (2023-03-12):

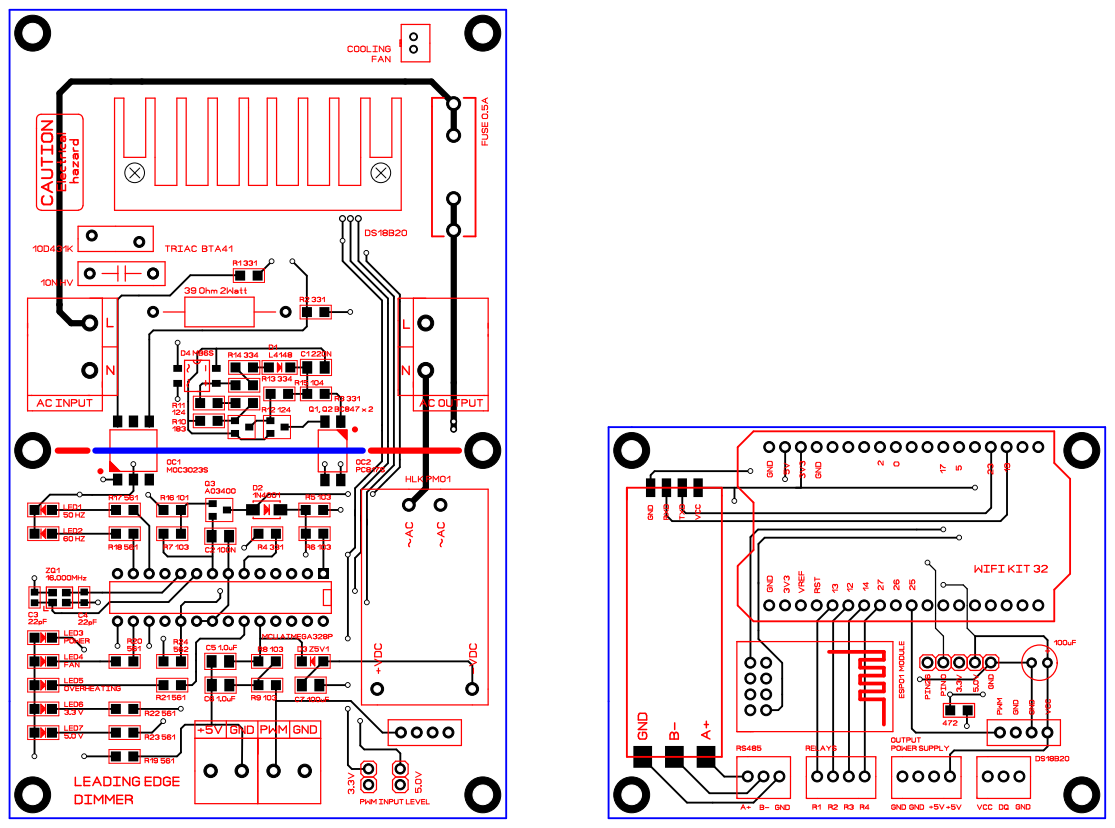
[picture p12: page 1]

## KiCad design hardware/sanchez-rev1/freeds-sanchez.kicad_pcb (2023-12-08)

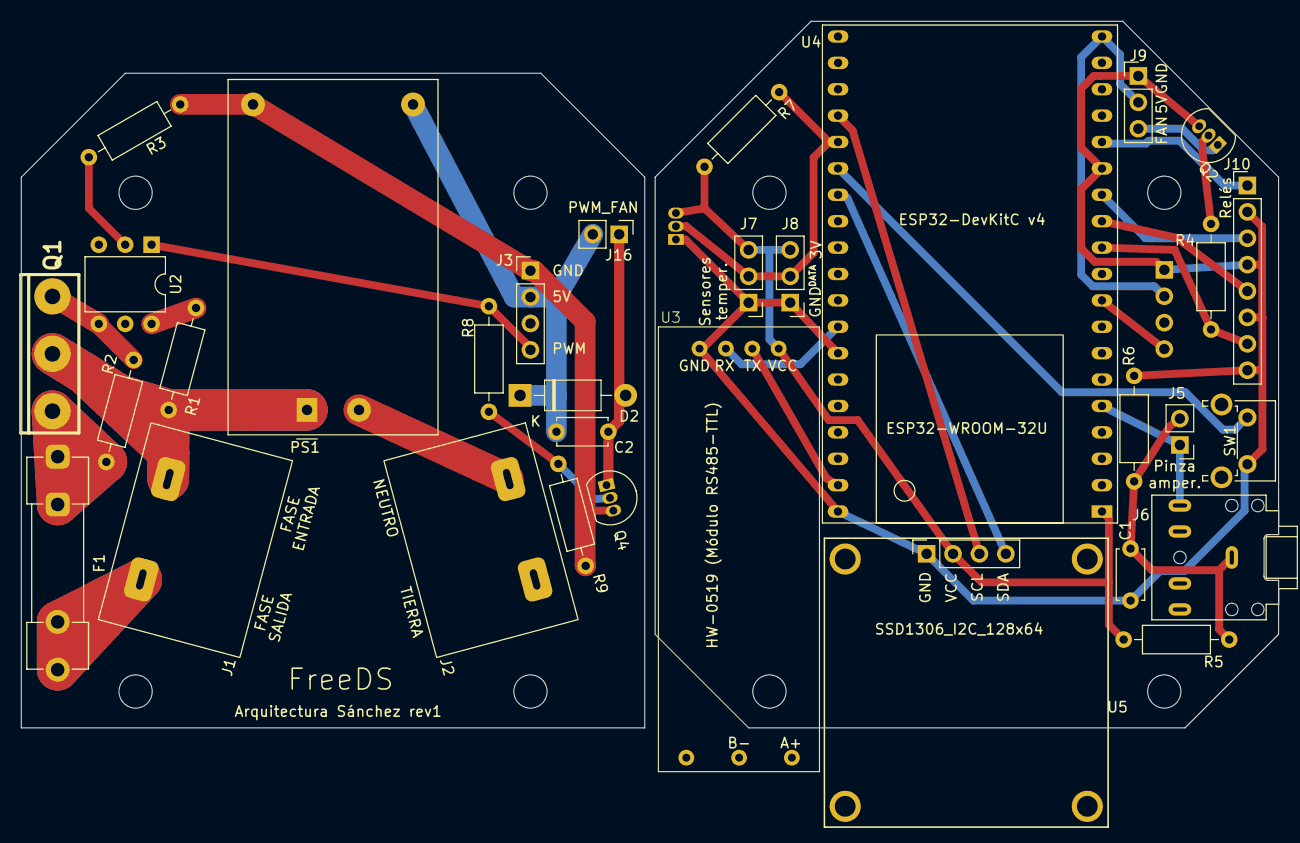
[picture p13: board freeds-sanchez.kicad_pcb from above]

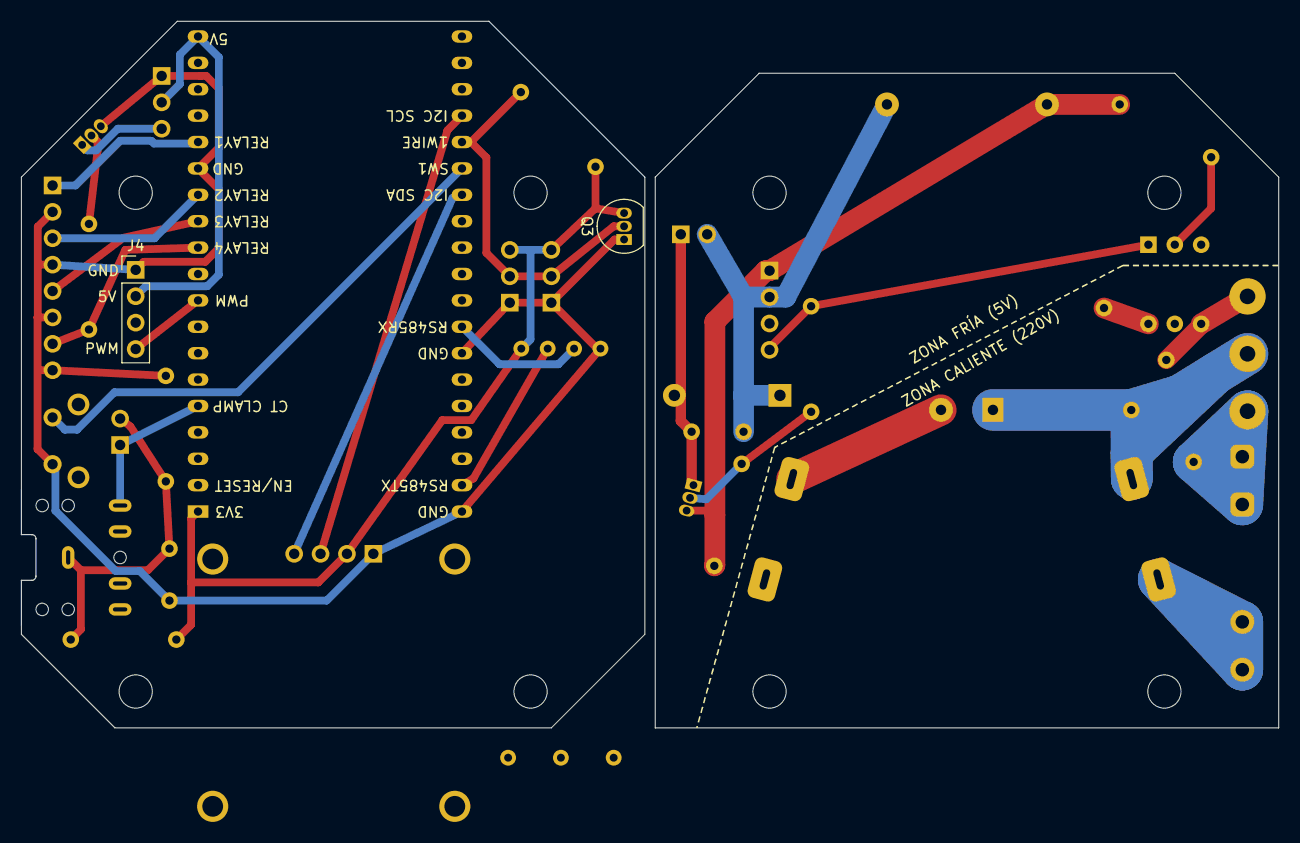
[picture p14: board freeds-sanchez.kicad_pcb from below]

Board: 2 copper layers, 121.0 x 68.0 mm, 42 parts (2 on the bottom side), 30 nets.

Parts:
C1, C2: 10µF; C_Disc_D4.7mm_W2.5mm_P5.00mm
D2: 1N4007; D_DO-41_SOD81_P10.16mm_Horizontal
F1: Fuse; Fuseholder_Clip-5x20mm_Littelfuse_100_Inline_P20.50x4.60mm_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
H2, H2#2, H3, H3#2, H4, H4#2, H5, H5#2: MountingHole; MountingHole_3.2mm_M3
J1, J2: Clema K1000; Clema 20x14mm K1000 2P
J3, J4: Inter-PCB; PinHeader_1x04_P2.54mm_Vertical
J5: Pinza Amper.; PinHeader_1x02_P2.54mm_Vertical
J6: CT Clamp; Jack_3.5mm_CUI_SJ1-3525N_Horizontal
J7: Temp sensor; PinHeader_1x03_P2.54mm_Vertical
J8: Temp Sensor; PinHeader_1x03_P2.54mm_Vertical
J9: R4_FAN; PinHeader_1x03_P2.54mm_Vertical
J10: RELÉS; PinHeader_1x08_P2.54mm_Vertical
J16: Conn_01x02_Male; PinHeader_1x02_P2.54mm_Vertical
PS1: HLK-PM01; Converter_ACDC_HiLink_HLK-PMxx
Q1: BTA26-600BW; TOP3_Vertical
Q2: BC337; TO-92_Inline
Q3: DS18B20; TO-92_Inline
Q4: BS170; TO-92_Inline
R1: 360Ω; R_Axial_DIN0207_L6.3mm_D2.5mm_P10.16mm_Horizontal
R2: 330Ω; R_Axial_DIN0207_L6.3mm_D2.5mm_P10.16mm_Horizontal
R3, R4: 180Ω; R_Axial_DIN0207_L6.3mm_D2.5mm_P10.16mm_Horizontal
R5, R6, R9: 10KΩ; R_Axial_DIN0207_L6.3mm_D2.5mm_P10.16mm_Horizontal
R7: 4.7KΩ; R_Axial_DIN0207_L6.3mm_D2.5mm_P10.16mm_Horizontal
R8: 3.3Ω; R_Axial_DIN0207_L6.3mm_D2.5mm_P10.16mm_Horizontal
SW1: PRG; SW_Tactile_SPST_Angled_PTS645Vx83-2LFS
U2: MOC3041M; DIP-6_W7.62mm
U3: HW-0519 (Módulo RS485-TTL); HW-519 TTL-RS485
U4: ESP32-WROOM-32U; ESP32-DevKitC
U5: SSD1306_I2C_128x64; OLED_SSD1306_I2C_0.96

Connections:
1WIRE: J7.2, J8.2, Q3.2 (DQ), R7.2, U4.24 (ADC2_CH2/GPIO2)
+3V3: J7.3, J8.3, Q3.3 (VDD), R5.1, R7.1, U3.1 (VCC), U4.1 (3V3), U5.2 (VCC)
+5V: J4.2, J9.2, U4.19 (5V)
/control/SW1: SW1.1 (A), U4.25 (GPIO0/BOOT/ADC2_CH1)
/potencia/+5V: C2.2, D2.1 (K), J3.2, J16.2, PS1.4 (+Vout)
/potencia/A1: F1.1, Q1.1 (A1), R2.1
/potencia/GND: J3.1, PS1.3 (-Vout), Q4.3 (S), R3.2, R9.1
/potencia/Gate: Q1.3 (G), R2.2, U2.4
/potencia/PWM POTENCIA: J3.4, R8.1, U2.1
CT CLAMP: J5.1, J6.T, U4.5 (VDET_1/GPIO34/ADC1_CH6)
GND: C1.2, J4.1, J7.1, J8.1, J9.1, J10.2, J10.4, J10.6, J10.8, Q2.3 (E), Q3.1 (GND), R6.2, SW1.2 (B), U3.4 (GND), U4.14 (GND), U4.32 (GND), U4.38 (GND), U5.1 (GND)
I2C SCL: U4.23 (MTDO/GPIO15/ADC2_CH3), U5.3 (SCL)
I2C SDA: U4.26 (ADC2_CH0/GPIO4), U5.4 (SDA)
LINE IN: J1.2, PS1.1 (AC/L), Q1.2 (A2), R1.1
LINE OUT: F1.2, J1.1
NEUT: J2.1, PS1.2 (AC/N)
unnamed: C2.1, D2.2 (A), J16.1, Q4.1 (D)
unnamed: C1.1, J5.2, J6.S, R5.2, R6.1
unnamed: J9.3, Q2.1 (C)
unnamed: Q2.2 (B), R4.1
unnamed: Q4.2 (G), R8.2, R9.2
unnamed: R1.2, U2.6
unnamed: R3.1, U2.2
PWM: J4.4, U4.9 (DAC_1/ADC2_CH8/GPIO25)
RELAY1: J10.1, U4.15 (MTCK/GPIO13/ADC2_CH4)
RELAY2: J10.3, U4.13 (MTDI/GPIO12/ADC2_CH5)
RELAY3: J10.5, U4.12 (MTMS/GPIO14/ADC2_CH6)
RELAY4: J10.7, R4.2, U4.11 (ADC2_CH7/GPIO27)
RS485RX: U3.3 (RXD), U4.31 (GPIO19)
RS485TX: U3.2 (TXD), U4.37 (GPIO23)

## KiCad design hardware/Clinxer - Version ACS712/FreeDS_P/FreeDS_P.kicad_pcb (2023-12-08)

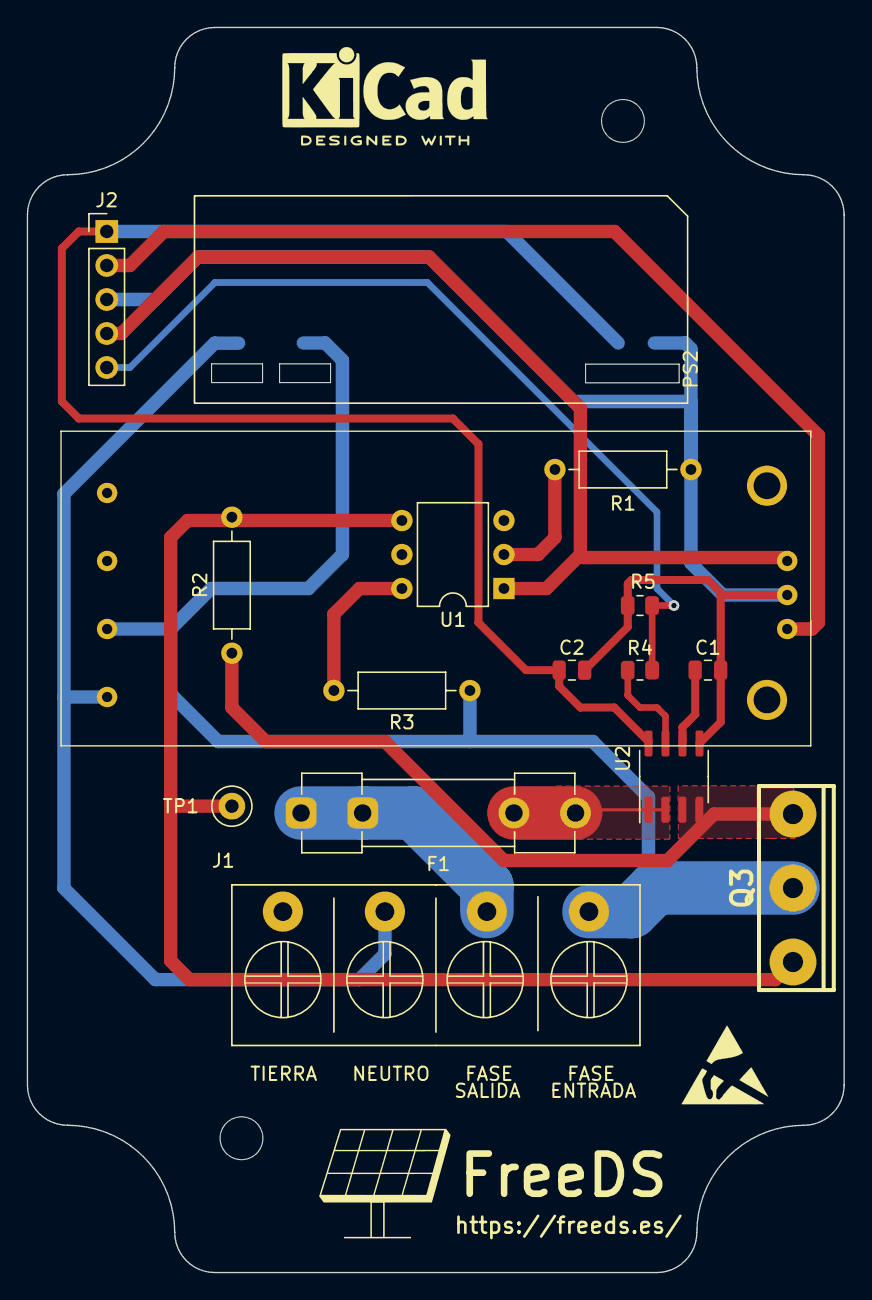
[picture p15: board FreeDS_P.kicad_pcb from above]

Board: 2 copper layers, 61.0 x 93.0 mm, 19 parts (0 on the bottom side), 15 nets.

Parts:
C1: 1nF; C_0805_2012Metric
C2: 100nF; C_0805_2012Metric
F1: Fuse; Fuseholder_Clip-5x20mm_Littelfuse_100_Inline_P20.50x4.60mm_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
FreeDS: LOGO; FreeDS
H1, H2: MountingHole; MountingHole_3.2mm_M3
J1: Screw_Terminal_01x04; KF7.62_4P
J2: Conn_01x05; PinHeader_1x05_P2.54mm_Vertical
PS2: HLK-5M03; 5V10W
Q3: BTA26-600BW; TOP3_Vertical
R1: 180R; R_Axial_DIN0207_L6.3mm_D2.5mm_P10.16mm_Horizontal
R2: 330R; R_Axial_DIN0207_L6.3mm_D2.5mm_P10.16mm_Horizontal
R3: 360R; R_Axial_DIN0207_L6.3mm_D2.5mm_P10.16mm_Horizontal
R4: 1K; R_0805_2012Metric
R5: 2K; R_0805_2012Metric
TP1: TestPoint_Probe; TestPoint_Loop_D2.50mm_Drill1.0mm
U1: MOC3041M; DIP-6_W7.62mm
U2: ACS712xLCTR-30A; SOIC-8_3.9x4.9mm_P1.27mm
U5: YYAC-3S PWM TRIAC

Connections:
/3V3: J2.2, U5.1 (3.3/5V)
/+5V: C2.1, J2.1, PS2.4 (+Vout), U2.8 (VCC)
/A2_FUSE: Q3.1 (A1), R2.1, U2.3 (IP-), U2.4 (IP-)
/EN: J2.5, R4.2, R5.1
/GND: C1.2, C2.2, J2.3, PS2.3 (-Vout), R1.2, R5.2, U2.5 (GND), U5.2 (GND)
/Lin: J1.1, PS2.1 (AC/L), Q3.2 (A2), R3.1, U5.6 (L-IN_230V)
/Lout: F1.1, J1.2
/N: J1.3, PS2.2 (AC/N), U5.7 (N-IN_230V)
/PWM: J2.4, U1.1, U5.3 (PWM)
unnamed: F1.2, U2.1 (IP+), U2.2 (IP+)
unnamed: Q3.3 (G), R2.2, TP1.1, U1.4
unnamed: R1.1, U1.2
unnamed: R3.2, U1.6
unnamed: C1.1, U2.6 (FILTER)
unnamed: R4.1, U2.7 (VIOUT)

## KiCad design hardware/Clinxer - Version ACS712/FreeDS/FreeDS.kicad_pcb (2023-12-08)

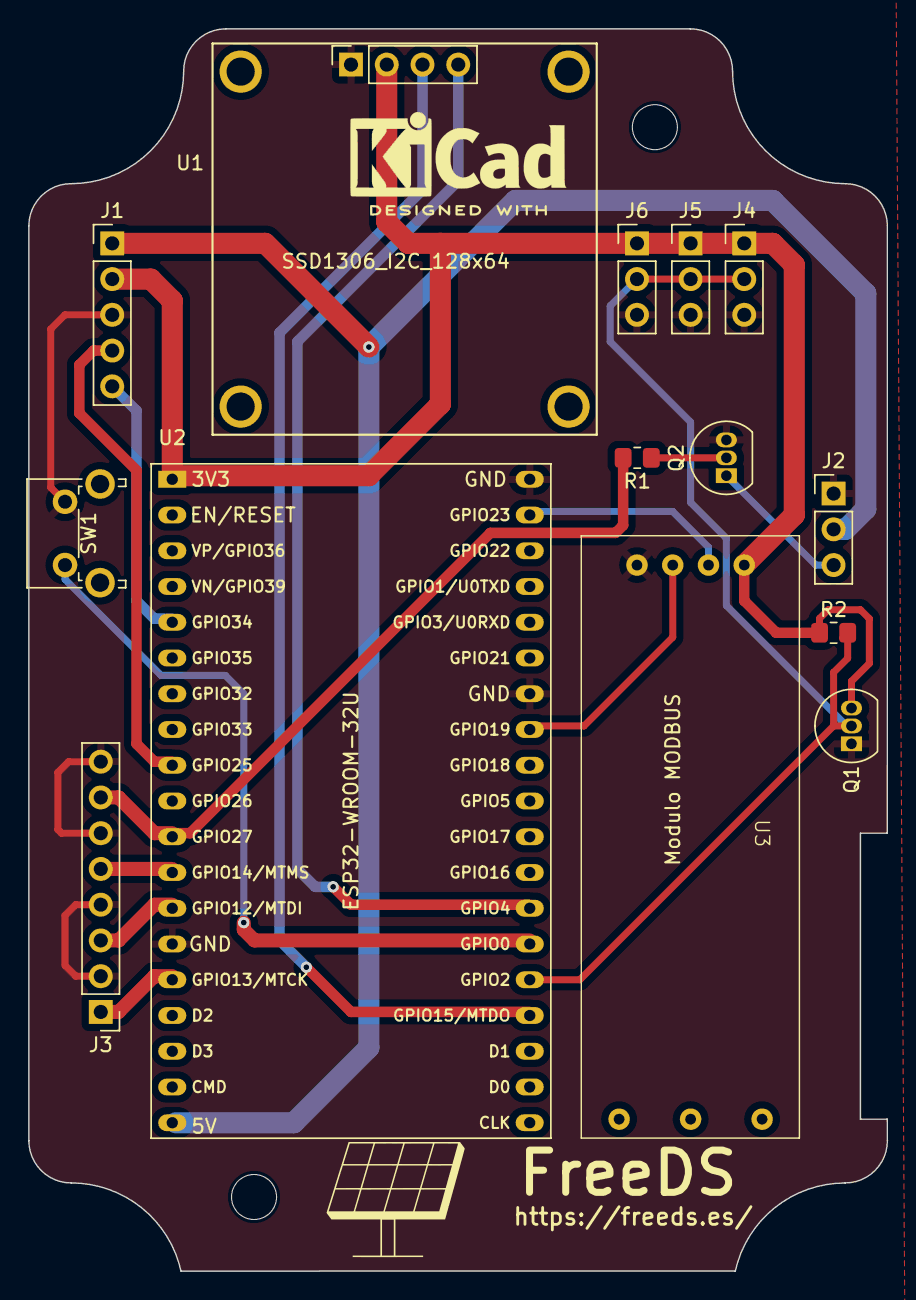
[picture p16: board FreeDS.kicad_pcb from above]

Board: 2 copper layers, 61.0 x 88.3 mm, 17 parts (0 on the bottom side), 17 nets.

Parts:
FreeDS: LOGO; FreeDS
H1, H6: MountingHole; MountingHole_3.2mm_M3
J1: Conn_01x05; PinHeader_1x05_P2.54mm_Vertical
J2: VENTILADOR; PinHeader_1x03_P2.54mm_Vertical
J3: SALIDAS AUXILIARES; PinHeader_1x08_P2.54mm_Vertical
J4, J5, J6: Conn_01x03_Male; PinHeader_1x03_P2.54mm_Vertical
Q1: DS18B20; TO-92_Inline
Q2: BC337; TO-92_Inline
R1: 180R; R_0805_2012Metric_Pad1.20x1.40mm_HandSolder
R2: 4K7; R_0805_2012Metric_Pad1.20x1.40mm_HandSolder
SW1: PRG; SW_Tactile_SPST_Angled_PTS645Vx83-2LFS
U1: SSD1306_I2C_128x64; OLED_SSD1306_I2C_0.96
U2: ESP32-WROOM-32U; ESP32-DevKitC
U3: Modulo MODBUS; MW-519 MODBUS

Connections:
/3V3: J1.2, J4.1, J5.1, J6.1, Q1.3 (VDD), R2.1, U1.2 (VCC), U2.1 (3V3), U3.1 (VCC)
/+5V: J1.1, J2.2, U2.19 (5V)
/DQ_DS18B20: J4.2, J5.2, J6.2, Q1.2 (DQ), R2.2, U2.24 (ADC2_CH2/GPIO2)
/EN: J1.5, U2.5 (VDET_1/GPIO34/ADC1_CH6)
/GND: J1.3, J2.1, J3.2, J3.4, J3.6, J3.8, J4.3, J5.3, J6.3, Q1.1 (GND), Q2.3 (E), SW1.2 (B), U1.1 (GND), U2.14 (GND), U2.32 (GND), U2.38 (GND), U3.4 (GND)
/PWM: J1.4, U2.9 (DAC_1/ADC2_CH8/GPIO25)
/RELE_1: J3.1, U2.15 (MTCK/GPIO13/ADC2_CH4)
/RELE_2: J3.3, U2.13 (MTDI/GPIO12/ADC2_CH5)
/RELE_3: J3.5, U2.12 (MTMS/GPIO14/ADC2_CH6)
/RELE_4: J3.7, R1.2, U2.11 (ADC2_CH7/GPIO27)
/RX: U2.31 (GPIO19), U3.3 (RXD)
/SCL: U1.3 (SCL), U2.23 (MTDO/GPIO15/ADC2_CH3)
/SDA: U1.4 (SDA), U2.26 (ADC2_CH0/GPIO4)
/SW1: SW1.1 (A), U2.25 (GPIO0/BOOT/ADC2_CH1)
/TX: U2.37 (GPIO23), U3.2 (TXD)
unnamed: J2.3, Q2.1 (C)
unnamed: Q2.2 (B), R1.1

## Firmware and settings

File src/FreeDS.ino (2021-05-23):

/*
  FreeDS.ino - Main source file
  Derivador de excedentes para ESP32 DEV Kit // Wifi Kit 32

  Inspired in opends+ (https://github.com/iqas/derivador)
  
  Copyright (C) 2020 Pablo Zerón (https://github.com/pablozg/freeds)

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
  You should have received a copy of the GNU General Public License
  along with this program.  If not, see <http://www.gnu.org/licenses/>.
*/

#define eepromVersion 0x17

#define sizeOfArray(x)  (sizeof(x) / sizeof((x)[0]))

#include <workingmode.h>
#include <Update.h>
#include <Wire.h>
#include <WiFi.h>
#include <WiFiMulti.h>
#include <WiFiUdp.h>
#include <EEPROM.h>
#include <TickerScheduler.h>
#include <HardwareSerial.h>

#include <ArduinoJson.h>
#include <AsyncTCP.h>
#include <ESPAsyncWebServer.h>
#include <AsyncMqttClient.h>
#include <ESPmDNS.h>
#include <SPIFFS.h>
#include <bitmap.h>
#include <DNSServer.h>
#include <esp32ModbusTCP.h>

#include <OneWire.h>
#include <DallasTemperature.h>

#include <PID_v1.h>

extern "C"
{
#include <crypto/base64.h>
#include <freertos/FreeRTOS.h>
#include <freertos/timers.h>
#include <rom/rtc.h>
#include <driver/dac.h>
#include <driver/adc.h>
#include <esp_system.h>
#include <time.h>
#include <esp_adc_cal.h>
}

#include "fauxmoESP.h"

#define OLED

#define MAX_SCREENS 5

#define DS18B20 2

#ifdef OLED
  // PWM Pin
  #define pin_pwm 25 // Cambiar a 25

  // ESP Serial
  #define pin_rx 17
  #define pin_tx 5

  // RELAY PINS
  #define PIN_RL1 13
  #define PIN_RL2 12
  #define PIN_RL3 14
  #define PIN_RL4 27

  // ADC PIN
  #define ADC_INPUT 34

  #include "SSD1306.h"
  SSD1306 display(0x3c, 4, 15);
#endif

// PARTIAL UNSUPPORTED, you must define your own pins to use this module.
#ifndef OLED
  // PWM Pin
  uint8_t pin_pwm = 2;

  // ESP Serial
  uint8_t pin_rx = 16;
  uint8_t pin_tx = 17;

  // RELAY PINS
  #define PIN_RL1 5
  #define PIN_RL2 18
  #define PIN_RL3 19
  #define PIN_RL4 21
#endif

// OVERRIDE DEFAULT CONFIG FOR UART1
#define RX1 19
#define TX1 23

// Variables Globales
const char compile_date[] PROGMEM = __DATE__ " " __TIME__;
const char version[] PROGMEM = "1.0.7";
const char beta[]  PROGMEM = "Rev 2";

const char *www_username = "admin";

// Debounce control
struct BUTTON_CONTROL
{
  unsigned long lastDebounceTime = 0;
  unsigned long debounceDelay = 100;
  bool ButtonState = false;
  bool ButtonLongPress = false;
  uint8_t screen = 0;
} button;

// Variables Globales calculo PWM
struct PWM_CONFIG
{
  uint16_t invert_pwm = 0; // Up 1023 with 10 bits resolution.
  uint16_t targetPwm = 0;
  uint8_t pwmValue = 0;
} pwm;

struct SLAVE
{
  uint8_t workingMode;
  uint8_t masterMode = 0;
  uint8_t masterPwmValue = 0;
} slave;

// Temporizadores
struct {
    unsigned long ErrorConexionWifi = 0;
    unsigned long ErrorVariacionDatos = 0;
    unsigned long ErrorRecepcionDatos = 0;
    unsigned long ErrorLecturaTemperatura[3] = {0};
    unsigned long FlashDisplay = 0;
    unsigned long OledAutoOff = 0;
    unsigned long printDebug = 0;
    unsigned long KwToday = 0;
} timers;

// Flags
union {
  uint32_t data;
  struct {
    uint32_t firstInit : 1;       // Bit 0
    uint32_t Updating : 1;        // Bit 1
    uint32_t flash : 1;           // Bit 2
    uint32_t reboot : 1;          // Bit 3
    uint32_t RelayTurnOn : 1;     // Bit 4
    uint32_t RelayTurnOff : 1;    // Bit 5
    uint32_t Relay01Auto : 1;     // Bit 6
    uint32_t Relay02Auto : 1;     // Bit 7
    uint32_t Relay03Auto : 1;     // Bit 8
    uint32_t Relay04Auto : 1;     // Bit 9
    uint32_t Relay01Man : 1;      // Bit 10
    uint32_t Relay02Man : 1;      // Bit 11
    uint32_t Relay03Man : 1;      // Bit 12
    uint32_t Relay04Man : 1;      // Bit 13
    uint32_t setBrightness : 1;   // Bit 14
    uint32_t weblogConnected : 1; // Bit 15
    uint32_t ntpTime : 1;         // Bit 16
    uint32_t timerSet : 1;        // Bit 17
    uint32_t pwmIsWorking : 1;    // Bit 18
    uint32_t pwmManAuto : 1;      // Bit 19
    uint32_t showClampCurrent : 1;// Bit 20
    uint32_t bootCompleted : 1;   // Bit 21
    uint32_t tempShutdown : 1;    // Bit 22
    uint32_t spare : 10;          // Bit 23 - 31
  };
} Flags;

// Flags Errores
union {
  uint16_t data;
  struct {
    uint16_t ConexionWifi : 1;       // Bit 0
    uint16_t RecepcionDatos : 1;     // Bit 1
    uint16_t ConexionMqtt : 1;       // Bit 2
    uint16_t VariacionDatos : 1;     // Bit 3
    uint16_t RemoteApi : 1;          // Bit 4
    uint16_t temperaturaTermo : 1;   // Bit 5
    uint16_t temperaturaTriac : 1;   // Bit 6
    uint16_t temperaturaCustom : 1;  // Bit 7
    uint16_t spare : 8;              // Bit 8 - 15
  };
} Error;

// Estructuras
typedef union {
  uint32_t data;
  struct {
    uint32_t wifi : 1;               // Bit 0
    uint32_t dhcp : 1;               // Bit 1
    uint32_t mqtt : 1;               // Bit 2
    uint32_t pwmEnabled: 1;          // Bit 3
    uint32_t pwmMan : 1;             // Bit 4
    uint32_t oledPower : 1;          // Bit 5
    uint32_t oledAutoOff : 1;        // Bit 6
    uint32_t potManPwmActive : 1;    // Bit 7
    uint32_t serial : 1;             // Bit 8
    uint32_t debug1 : 1;             // Bit 9
    uint32_t weblog : 1;             // Bit 10
    uint32_t timerEnabled : 1;       // Bit 11
    uint32_t debug2 : 1;             // Bit 12
    uint32_t sensorTemperatura : 1;  // Bit 13
    uint32_t alexaControl : 1;       // Bit 14
    uint32_t domoticz : 1;           // Bit 15
    uint32_t dimmerLowCost : 1;      // Bit 16
    uint32_t changeGridSign : 1;     // Bit 17
    uint32_t debug3 : 1;             // Bit 18
    uint32_t debug4 : 1;             // Bit 19
    uint32_t flipScreen : 1;         // Bit 20
    uint32_t offGrid : 1;            // Bit 21
    uint32_t showEnergyMeter : 1;    // Bit 22
    uint32_t offgridVoltage : 1;     // Bit 23
    uint32_t debug5 : 1;             // Bit 24
    uint32_t useClamp : 1;           // Bit 25
    uint32_t useSolarAsMPTT : 1;     // Bit 26
    uint32_t useBMV : 1;             // Bit 27
    uint32_t useExternalMeter : 1;   // Bit 28
    uint32_t spare : 2;              // Bit 29 - 30
    uint32_t debugPID : 1;           // Bit 31
  };
} SysBitfield;

typedef union {
  uint32_t data;
  struct {
    uint32_t R01Man : 1;   // Bit 0
    uint32_t R02Man : 1;   // Bit 1
    uint32_t R03Man : 1;   // Bit 2
    uint32_t R04Man : 1;   // Bit 3
    uint32_t spare : 28;   // Bit 4 - 31
  };
} RelayFlags;

union {
  uint32_t data;
  struct {
    uint32_t energyTotal : 1;       // Bit 0
    uint32_t voltage : 1;           // Bit 1
    uint32_t current : 1;           // Bit 2
    uint32_t activePower : 1;       // Bit 3
    uint32_t aparentPower : 1;      // Bit 4
    uint32_t reactivePower : 1;     // Bit 5
    uint32_t powerFactor : 1;       // Bit 6
    uint32_t frequency : 1;         // Bit 7
    uint32_t importActive : 1;      // Bit 8
    uint32_t exportActive : 1;      // Bit 9
    uint32_t importReactive : 1;    // Bit 10
    uint32_t exportReactive : 1;    // Bit 11
    uint32_t phaseAngle : 1;        // Bit 12
    uint32_t pv1c : 1;              // Bit 13
    uint32_t pv2c : 1;              // Bit 14
    uint32_t pv1v : 1;              // Bit 15
    uint32_t pv2v : 1;              // Bit 16
    uint32_t pw1 : 1;               // Bit 17
    uint32_t pw2 : 1;               // Bit 18
    uint32_t gridv : 1;             // Bit 19
    uint32_t wsolar : 1;            // Bit 20
    uint32_t wtoday : 1;            // Bit 21
    uint32_t wgrid : 1;             // Bit 22
    uint32_t wtogrid : 1;           // Bit 23
    uint32_t temperature : 1;       // Bit 24
    uint32_t batteryWatts : 1;      // Bit 25
    uint32_t batterySoC : 1;        // Bit 26
    uint32_t loadWatts : 1;         // Bit 27
    uint32_t spare : 4;             // Bit 28 - 31
  };
} webMonitorFields;

struct CONFIG
{
  byte eeinit;
  uint8_t wversion;

  // STATIC IP
  char ip[16];
  char gw[16];
  char mask[16];
  char dns1[16];
  char dns2[16];

  // SALIDAS RELÉS
  int16_t potTarget;
  int16_t free16_1;
 
  uint16_t R01Min;
  int16_t R01PotOn;
  int16_t R01PotOff;

  uint16_t R02Min;
  int16_t R02PotOn;
  int16_t R02PotOff;

  uint16_t R03Min;
  int16_t R03PotOn;
  int16_t R03PotOff;

  uint16_t R04Min;
  int16_t R04PotOn;
  int16_t R04PotOff;
  RelayFlags relaysFlags; // Guarda el estado de los relés
  
  // DATOS SOLAX V2
  char ssid_esp01[30];
  char password_esp01[30];
  
  // ORIGEN DATOS
  char sensor_ip[30];

  // MQTT
  char MQTT_broker[25];
  char MQTT_user[20];
  char MQTT_password[20];
  uint16_t MQTT_port;
  char R01_mqtt[50];
  char R02_mqtt[50];
  char R03_mqtt[50];
  char R04_mqtt[50];
  char password[30];
  char Solax_mqtt[50];
  char Meter_mqtt[50];
  unsigned long publishMqtt;

  // WIFI
  char ssid1[30];
  char pass1[30];
  char ssid2[30];
  char pass2[30];
  char hostServer[12];

  // PANTALLA
  uint8_t oledBrightness;

  // TEMPORIZADORES
  unsigned long oledControlTime;
  unsigned long freeTemp;
  unsigned long maxErrorTime;
  unsigned long getDataTime;

  // PWM
  uint8_t manualControlPWM;
  uint8_t autoControlPWM;
  uint16_t pwmFrequency;
  uint16_t potManPwm;
  
  // METER
  uint16_t baudiosMeter;
  uint8_t idMeter;

  // PROGRAMADOR
  uint16_t timerStart;
  uint16_t timerStop;

  // CONTROL TEMPERATURA
  uint8_t temperaturaEncendido;
  uint8_t temperaturaApagado;
  uint8_t modoTemperatura;
  uint8_t termoSensorAddress[8];
  uint8_t triacSensorAddress[8];
  char nombreSensor[30];
  uint8_t customSensorAddress[8];

  // PWM ACTIVACIÓN ESCLAVO
  uint8_t pwmSlaveOn;
  
  // BANDERAS SISTEMA
  SysBitfield flags;
  
  uint16_t domoticzIdx[3];
  uint16_t attachedLoadWatts;
  uint16_t maxPwmLowCost;

  // CONTROL DE CONSUMO Y VERTIDO
  float KwToday;
  float KwExportToday;
  float KwYesterday;
  float KwExportYesterday;
  float KwTotal;
  float KwExportTotal;

  // OFFGRID
  uint8_t soc;
  int16_t battWatts;

  // TIMEZONE
  // Use https://github.com/nayarsystems/posix_tz_db/blob/master/zones.csv to get the correct tz config.
  char tzConfig[30];

  // User language
  char language[5];
  
  // Maximum watts in user tariff
  uint16_t maxWattsTariff;

  // MQTT SoC Topic ICC Solar
  char SoC_mqtt[30];
  float batteryVoltage;

  // NTP Server
  char ntpServer[30];

  // Calibration Value
  float clampCalibration;

  // Clamp Voltage
  float clampVoltage;
  
  // Store PIDValues
  float PIDValues[3];

  // Battery Offset
  float voltageOffset;

  // Phase to be used
  uint8_t gridPhase;

  // Solax Version
  uint8_t solaxVersion;

  // FREE MEMORY
  uint8_t free[1042];
} config;

struct METER
{
  float energyTotal = 0;
  float voltage = 0;
  float current = 0;
  float activePower = 0;
  float aparentPower = 0;
  float reactivePower = 0;
  float powerFactor = 0;
  float frequency = 0;
  float importActive = 0;
  float exportActive = 0;
  float importReactive = 0;
  float exportReactive = 0;
  float phaseAngle = 0;

  uint8_t read_state = 0;
  uint8_t send_retry = 5;
} meter;

struct INVERTER
{
  float pv1c;              // Corriente string 1
  float pv2c;              // Corriente string 2
  float pv1v;              // Tension string 1
  float pv2v;              // Tension string 2
  float pw1;               // Potencia string 1
  float pw2;               // Potencia string 2
  float gridv;             // Tension de red
  float wsolar;            // Potencia solar
  float wtoday;            // Potencia solar diaria
  float wgrid;             // Potencia de red (Negativo: de red - Positivo: a red)
  float wtogrid;           // Potencia enviada a red
  float wgrid_control = 0; // Control del valor de wgrid
  float temperature;       // Temperatura del Inversor
  float batteryWatts = 0;  // Consumo de las Baterías 
  float batterySoC;
  float loadWatts = 0;
  float currentCalcWatts = 0;
  float acIn = 0;
  float acOut = 0;
} inverter;

struct UPTIME
{
  long Day = 0;
  int Hour = 0;
  int Minute = 0;
  int Second = 0;
  int HighMillis = 0;
  int Rollover = 0;
} uptime;

struct
{
  char _GRID_[8];
  char _SOLAR_[8];
  char _BATTERY_[10];
  char _INVERTERINFO_[18];
  char _METERINFO_[18];
  char _OLEDPOWER_[12];
  char _VOLTAGE_[12];
  char _CURRENT_[12];
  char _IMPORT_[12];
  char _EXPORT_[12];
  char _OLEDTODAY_[8];
  char _START_[16];
  char _CONNECTING_[16];
  char _RELAY_[12];
  char _CONNECTSSID_[22];
  char _CONFIGPAGE_[18];
  char _PRGRESTORE_[32];
  char _WAIT_[32];
  char _UPDATING_[32];
  char _LOSTWIFI_[32];
  char _TEMPERATURES_[22];
  char _INVERTERTEMP_[22];
  char _TERMOTEMP_[22];
  char _TRIACTEMP_[22];
  char _DERIVADOR_[32];
  char _COMPILATION_[22];
} lang;

struct tm timeinfo;

#define LOGGINGSIZE 20 //30
struct LOGGING
{
  char loggingMessage[LOGGINGSIZE][1024];
  int logcount = 0;
} logMessage;

uint8_t webMessageResponse = 0;
boolean processData = false;

String scanNetworks[15];
int32_t rssiNetworks[15];
uint8_t scanDoneCounter = 0;

char jsonResponse[768];

// Definiciones Conexiones
WiFiMulti wifiMulti;

fauxmoESP fauxmo;
AsyncWebServer server(80);
AsyncEventSource events("/events");
AsyncEventSource webLogs("/weblog");
AsyncMqttClient mqttClient;

static esp32ModbusTCP *modbustcp = NULL;
IPAddress modbusIP;

HardwareSerial SerieEsp(2);   // RX, TX para esp-01
HardwareSerial SerieMeter(1); // RX, TX para los Meter rs485/modbus
DynamicJsonDocument root(4096); // 3072

TickerScheduler Tickers(7);

DNSServer dnsServer;

TimerHandle_t relayOnTimer;
TimerHandle_t relayOffTimer;
TimerHandle_t startTimer;

// Setup a oneWire instance to communicate with any OneWire devices
OneWire oneWire(DS18B20);

// Pass our oneWire reference to Dallas Temperature sensor 
DallasTemperature sensors(&oneWire);

struct TEMPERATURE_CONFIG
{
  uint8_t tempSensorAddress[15][8];
  float temperaturaTermo = -127.0;
  float temperaturaTriac = -127.0;
  float temperaturaCustom = -127.0;
} temperature;


// Energy Monitor (Functions from emonLib) https://github.com/openenergymonitor/EmonLib
#define ADC_BITS    12
#define ADC_COUNTS  (1<<ADC_BITS)

uint8_t inPinI;
double ICAL;
double sampleI;
double filteredI;
double offsetI;
double sqI, sumI, Irms;

// PID Declaration
float Setpoint, PIDInput, PIDOutput;

PID myPID(&PIDInput, &PIDOutput, &Setpoint, 0.05, 0.06, 0.03, PID::DIRECT); // Probando 0.10 0.07 0.04

// GoodWe UDP Config
WiFiUDP inverterUDP;
unsigned int localUdpPort = 8899;  // local port to listen on
uint8_t incomingPacket[512];  // buffer for incoming packets

//////////////////// CAPTIVE PORTAL ////////////////

class CaptiveRequestHandler : public AsyncWebHandler {
public:
  CaptiveRequestHandler() {}
  virtual ~CaptiveRequestHandler() {}

  bool canHandle(AsyncWebServerRequest *request){
    return true;
  }
  
  void handleRequest(AsyncWebServerRequest *request) {
    
    if(request->url() == "/savedata"){
        strcpy(config.ssid1, request->urlDecode(request->arg("wifis")).c_str());
        strcpy(config.pass1, request->urlDecode(request->arg("password")).c_str());
        config.flags.wifi = true;

        EEPROM.put(0, config);
        EEPROM.commit();
        Serial.print("DATA SAVED!!!!, RESTARTING!!!!");
        request->redirect("/");
        delay(500); // Only to be able to redirect client
        ESP.restart();

    } else {
      
      AsyncResponseStream *response = request->beginResponseStream("text/html");
      response->print("<!DOCTYPE html><html><head><meta http-equiv='Content-Type' content='text/html; charset=UTF-8'><title>FREEDS</title></head>");
      response->print("<body id='main_body'><div id='form_container'><h1><a>FREEDS</a></h1>");
      response->print("<form id='captive' method='get' action='/savedata'><div class='form_description'><p>1º Seleccione una SSID</p><p>2º Indroduzca el password</p>");
      response->print("<p>3º Pulse Guardar</p><p>4º Espere a que reinicie y acceda a http://" + String(config.hostServer) + ".local/ para una configuración más avanzada.</p></div><ul>");
      response->print("<label class='description' for='wifis'>SSID:</label>");
      response->print("<div><select id='wifis' name='wifis'>");
      response->print("<option disabled selected>Seleccione una red</option>");
      
      char tmp[80];
      for (int i = 0; i < 15; ++i) {
        if (scanNetworks[i] == "") { break; }
        sprintf(tmp,"%s (%d dBm)", scanNetworks[i].c_str(), rssiNetworks[i]);
        response->print(" <option value='" + scanNetworks[i] + "'>" + String(tmp) + "</option>");
      }
      response->print("</select></div>");
      response->printf("<br><label class='description' for='password'>Password:</label>");
      response->printf("<div><input id='password' name='password' class='element text medium' type='text' maxlength='30' value=''/></div>");
      response->printf("<br><input id='saveForm' class='button_text' type='submit' name='submit' value='Guardar' /></ul>");
      response->printf("</form></div></body></html>");
      request->send(response);
    }
  }
};

// Declaration of default values
void shutdownPwm(boolean = false, const char* = "PWM: disabling PWM\n");

////////// WATCHDOG FUNCTIONS //////////

const int loopTimeCtl = 0;
hw_timer_t *timer = NULL;

void IRAM_ATTR resetModule()
{
  INFOV("Reboot by Watchdog\n");
  ESP.restart();
}
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
void loop()
{
  // Serial.printf("\nLoop Time: %lu\n", millis() - tme);
  // tme = millis();
  
  //////// Watchdog ////////////
  timerWrite(timer, 0); // reset timer (feed watchdog)
  /////////////////////////////////////

  updateUptime();

  Flags.firstInit ? dnsServer.processNextRequest() : fauxmo.handle();

  if (config.flags.wifi && !Flags.firstInit)
  {
    Tickers.update(); // Actualiza todas los tareas Temporizadas

    if (processData) { processingData(); }
    
    changeScreen();
    
    if (config.wversion == GOODWE) { parseUDP(); }

    // PID Check Loop
    if (config.flags.pwmEnabled && !Error.VariacionDatos && !Error.RecepcionDatos && Flags.pwmIsWorking && myPID.GetMode() == PID::AUTOMATIC && myPID.Compute()) {
      pwm.targetPwm = pwm.invert_pwm = (uint16_t)PIDOutput;
      if (config.flags.dimmerLowCost && pwm.invert_pwm <= 210) { pwm.invert_pwm = 0; }
      writePwmValue(pwm.invert_pwm);
    }
    
    if (config.flags.sensorTemperatura) { checkTemperature(); }
    
    if (config.flags.debug4) { 
      if (millis() - timers.printDebug > 2000){
        INFOV("\n");
        INFOV("Error Recepción Datos: %s, Error Variación Datos: %s, Error Conexión Mqtt: %s\n", Error.RecepcionDatos ? "true" : "false", Error.VariacionDatos ? "true" : "false", Error.ConexionMqtt ? "true" : "false");
        INFOV("Timer Recepción Datos: %ld, Timer Variación Datos: %ld\n", millis() - timers.ErrorRecepcionDatos, millis() - timers.ErrorVariacionDatos);
        INFOV("Modo Manual: %d, Modo Manual Automático: %d, PwmIsWorking: %d, pwm.invert_pwm: %d, pwm.targetPwm: %d, battery: %.02f\n", config.flags.pwmMan, Flags.pwmManAuto, Flags.pwmIsWorking, pwm.invert_pwm, pwm.targetPwm, inverter.batteryWatts);
        INFOV("Rele 1: %s, Rele 2: %s, Rele 3: %s, Rele 4:%s\n", digitalRead(PIN_RL1) ? "ON" : "OFF", digitalRead(PIN_RL2) ? "ON" : "OFF", digitalRead(PIN_RL3) ? "ON" : "OFF", digitalRead(PIN_RL4) ? "ON" : "OFF");
        //INFOV("Error Temp 1: %ld, Error Temp 2: %ld, Error Temp 3: %ld", millis() - timers.ErrorLecturaTemperatura[0], millis() - timers.ErrorLecturaTemperatura[1], millis() - timers.ErrorLecturaTemperatura[2]);
        timers.printDebug = millis();
      }
    }
    
    // if (config.wversion != SOLAX_V2_LOCAL && Flags.ntpTime) {
    if (strcmp("5.8.8.8", config.sensor_ip) != 0 && Flags.ntpTime) {
      checkTimer();
      updateLocalTime();
    }
    
    if (Flags.setBrightness) {
      saveEEPROM();
      display.setBrightness((uint8_t)((config.oledBrightness * 255) / 100));
      display.resetDisplay();
      Flags.setBrightness = false;
    }

    if (webLogs.count() == 0) { Flags.weblogConnected = false; }

    if ((millis() - timers.OledAutoOff) > config.oledControlTime)
    {
      if (config.flags.oledAutoOff) {
        config.flags.oledPower = false;
        turnOffOled();
      }
    }

    if (config.flags.potManPwmActive) {
      if (inverter.wsolar < config.potManPwm && !Flags.pwmManAuto) {
        Flags.pwmManAuto = true;
      } 
      
      if (inverter.wsolar > config.potManPwm && Flags.pwmManAuto) {
        Flags.pwmManAuto = false;
      }
    }
  }
} // End loop

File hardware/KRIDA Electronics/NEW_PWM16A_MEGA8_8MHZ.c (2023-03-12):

/*****************************************************
This program was produced by the
CodeWizardAVR V2.04.4a Advanced
Automatic Program Generator
© Copyright 1998-2009 Pavel Haiduc, HP InfoTech s.r.l.
http://www.hpinfotech.com

Project : 
Version : 
Date    : 05.05.2022
Author  : KRIDA Electronics / Olegs Bugrovs
Company : 
Comments: 


Chip type               : ATmega8
Program type            : Application
AVR Core Clock frequency: 8,000000 MHz
Memory model            : Small
External RAM size       : 0
Data Stack size         : 256
*****************************************************/
////////////////////////////////////////////////////////
//                                                    //
// This is latest firmware for 2023 year              //
// PCB version 3.1, mcu ATMEGA8                       //
//                                                    //
////////////////////////////////////////////////////////
//                                                    //
//   FUSES - only SUT0 - \/                           //
//                                                    //
//   ATMEGA8 @ 8.000 external crystal                 //
//                                                    //
//   PWM16A Dimmer with adc filter                    //
//                                                    //
//   - added average slide adc filter                 //
//   - fixed bug with overheating led                 //
//                                                    //
//   10 MAY 2022                                      //
//                                                    //
////////////////////////////////////////////////////////


#include <mega8.h>
#include <ds18b20.h>    // in this library should be removed delay in 750ms
#include <delay.h>

#define LED_33 PINB.3
#define LED_50 PINB.1
#define LED_50HZ PORTD.6
#define LED_60HZ PORTD.7
#define LED_OVERHEATING PORTC.0
#define LED_FAN PORTB.2
#define FAN PORTD.3
#define GATE PORTD.4

#define MAX_DS18b20 8
#define BUTTON PINC.5

#define ADC_VREF_TYPE 0x20


unsigned int mas_0[20];
unsigned int average_0;
unsigned char i;


unsigned char ds18b20_devices;
unsigned char STATUS, PROTECT;
unsigned char blink_cn;
unsigned char TEMP_READ_FLAG;
unsigned char TEMP_COUNT;
unsigned char F;
unsigned char delay;
unsigned char LED_COUNT;


unsigned char adc_count;
unsigned int TIMER_1_DELAY, TIMER_1_BUF_DELAY, ;
unsigned int TIMER_1_IMPULSE, TIMER_1_BUF_IMPULSE, ;
unsigned int VARIABLE;
unsigned int adc_symm;
unsigned char adc_data_BUF;
unsigned char DATA_READY;
unsigned char adc_data;
unsigned char TRIAC;

unsigned int frequency;

int temp0;

unsigned char ds18b20_rom_codes[MAX_DS18b20][9];

// 1 Wire Bus functions
#asm
   .equ __w1_port=0x18 ;PORTB
   .equ __w1_bit=5
#endasm
#include <1wire.h>

// External Interrupt 0 service routine
interrupt [EXT_INT0] void ext_int0_isr(void)
{

 if (TRIAC==1 && PROTECT==0)
 {
  TIMER_1_DELAY = TIMER_1_BUF_DELAY; 
  
  TCNT1H=TIMER_1_DELAY >> 8;
  TCNT1L=TIMER_1_DELAY & 0xff;
  
  TCCR1B=0x02;
 }
 
 frequency=TCNT0;  
 
 TCNT0=0x00;  
 
 if (frequency>62 && frequency<85)    { LED_50HZ=1; 
                                        LED_60HZ=0; 
                                        STATUS=1;
                                        F=100;     } 
                                    
 
 if (frequency>62 && frequency<56)    { LED_50HZ=0; 
                                        LED_60HZ=1;
                                        STATUS=1;
                                        F=83;       }  

}

// Timer 0 overflow interrupt service routine
interrupt [TIM0_OVF] void timer0_ovf_isr(void)
{
 // overflow time 32,768 ms    
 
 TCNT0=0x00;

 STATUS=0;
 
 TCCR1B=0x00; 

 blink_cn++;  
                         
 if(blink_cn==5) { LED_50HZ=0; LED_60HZ=0;}
 if(blink_cn==10) { blink_cn=0; LED_50HZ=1; LED_60HZ=1;}



}

// Timer1 overflow interrupt service routine
interrupt [TIM1_OVF] void timer1_ovf_isr(void)
{
TIMER_1_IMPULSE = TIMER_1_BUF_IMPULSE; 

TCNT1H=TIMER_1_IMPULSE >> 8;
TCNT1L=TIMER_1_IMPULSE & 0xff;
// Place your code here

GATE=1;

delay++;

 if (delay==2)
 {
  GATE=0;
  delay=0;
  TCCR1B=0x00;
 }

}

// Timer2 overflow interrupt service routine
interrupt [TIM2_OVF] void timer2_ovf_isr(void)
{
    TCNT2=0x63;
  
    TEMP_COUNT++;
    LED_COUNT++;   
    
 //   if (LED_COUNT==25 && PROTECT==1)
 //   {
 //    LED_OVERHEATING=~LED_OVERHEATING;     
 //    LED_COUNT=0;
 //   }
    
  
    if (TEMP_COUNT==200)
    {       
     TEMP_READ_FLAG=1;
    }   

}


// Read the 8 most significant bits
// of the AD conversion result
// ADC interrupt service routine
interrupt [ADC_INT] void adc_isr(void)
{
adc_symm+=ADCH;

   adc_count++;

if (adc_count==200)
 {
  adc_count=0;
  adc_data=adc_symm/200;     
  
  
  
  for (i=0;i<19;i++) {mas_0[i] = mas_0[i+1];}
  mas_0[19] = adc_data;
  
  average_0 = mas_0[0] + mas_0[1] + mas_0[2] + mas_0[3] + mas_0[4] + mas_0[5] + mas_0[6] + mas_0[7] + mas_0[8] + mas_0[9] + mas_0[10] + mas_0[11] + mas_0[12] + mas_0[13] + mas_0[14] + mas_0[15] + mas_0[16] + mas_0[17] + mas_0[18] + mas_0[19];
                           
  
  adc_data = average_0/20;
  
  
  
  if (LED_33==0) 
  {
   if (adc_data>168) {adc_data=168;}
   adc_data=adc_data*1.51;
  }
    
  adc_data=255-adc_data;
  adc_symm=0;  
  
  
  if (adc_data<245)  //  origin value 235      
   {
    TRIAC=1;
    if (adc_data<15)  { adc_data=15;}      
   }
    
  if (adc_data>240  )   
   {    
    TRIAC=0; TCCR1B=0x00; GATE=0;      
   } 
   
   DATA_READY=1;      
 }
 
  ADCSRA|=0x40;
}

// Declare your global variables here

void main(void)
{
// Declare your local variables here


// Input/Output Ports initialization
// Port B initialization
// Func7=In Func6=In Func5=In Func4=In Func3=Out Func2=Out Func1=Out Func0=In 
// State7=T State6=T State5=T State4=T State3=1 State2=1 State1=1 State0=T 
PORTB=0x0E;
DDRB=0x04;

// Port C initialization
// Func6=In Func5=In Func4=In Func3=In Func2=In Func1=In Func0=Out 
// State6=T State5=P State4=T State3=T State2=T State1=T State0=1 
PORTC=0x21;
DDRC=0x01;

// Port D initialization
// Func7=Out Func6=Out Func5=In Func4=Out Func3=Out Func2=In Func1=In Func0=In 
// State7=0 State6=0 State5=T State4=0 State3=0 State2=T State1=T State0=T 
PORTD=0x00;
DDRD=0xD8;

// Timer/Counter 0 initialization
// Clock source: System Clock
// Clock value: 7.8125 kHz
// Prescaler: 1024
TCCR0=0b00000101;   
TCNT0=0x00;

// Timer/Counter 1 initialization
// Clock source: System Clock
// Clock value: 1000,000 kHz
// Mode: Normal top=FFFFh
// OC1A output: Discon.
// OC1B output: Discon.
// Noise Canceler: Off
// Input Capture on Falling Edge
// Timer1 Overflow Interrupt: On
// Input Capture Interrupt: Off
// Compare A Match Interrupt: Off
// Compare B Match Interrupt: Off
TCCR1A=0x00;
TCCR1B=0x02;
TCNT1H=0x00;
TCNT1L=0x00;
ICR1H=0x00;
ICR1L=0x00;
OCR1AH=0x00;
OCR1AL=0x00;
OCR1BH=0x00;
OCR1BL=0x00;
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

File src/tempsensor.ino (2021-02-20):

/*
  tempsensor.ino - FreeDs temperature functions
  Derivador de excedentes para ESP32 DEV Kit // Wifi Kit 32
  
  Copyright (C) 2020 Pablo Zerón (https://github.com/pablozg/freeds)

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
  You should have received a copy of the GNU General Public License
  along with this program.  If not, see <http://www.gnu.org/licenses/>.
*/

void calcDallasTemperature(void)
{
    sensors.setWaitForConversion(true);
    sensors.requestTemperatures();

    float temperatura;

    if (config.termoSensorAddress[0] != 0x0) {
        temperatura = sensors.getTempC(config.termoSensorAddress);

        if (temperatura != -127.0) {
            temperature.temperaturaTermo = temperatura; 
            timers.ErrorLecturaTemperatura[0] = millis();
            Error.temperaturaTermo = false;
        }

        if ((millis() - timers.ErrorLecturaTemperatura[0]) > config.maxErrorTime) {
            Error.temperaturaTermo = true;
            temperature.temperaturaTermo = -127;
            INFOV("Failed to read termo temperature from DS18B20 sensor\n");
        }
    } else { temperature.temperaturaTermo = -127; Error.temperaturaTermo = false;}

    if (config.triacSensorAddress[0] != 0x0) {
        temperatura = sensors.getTempC(config.triacSensorAddress);
        
        if (temperatura != -127.0) {
            temperature.temperaturaTriac = temperatura; 
            timers.ErrorLecturaTemperatura[1] = millis();
            Error.temperaturaTriac = false;
        }

        if ((millis() - timers.ErrorLecturaTemperatura[1]) > config.maxErrorTime) {
            Error.temperaturaTriac = true;
            temperature.temperaturaTriac = -127;
            INFOV("Failed to read triac temperature from DS18B20 sensor\n");
        }
    } else { temperature.temperaturaTriac = -127; Error.temperaturaTriac = false; }

    if (config.customSensorAddress[0] != 0x0) {
        temperatura = sensors.getTempC(config.customSensorAddress);

        if (temperatura != -127.0) {
            temperature.temperaturaCustom = temperatura; 
            timers.ErrorLecturaTemperatura[2] = millis();
            Error.temperaturaCustom = false;
        }

        if ((millis() - timers.ErrorLecturaTemperatura[2]) > config.maxErrorTime) {
            Error.temperaturaCustom = true;
            temperature.temperaturaCustom = -127;
            INFOV("Failed to read termo temperature from DS18B20 sensor\n");
        }
    } else { temperature.temperaturaCustom = -127; Error.temperaturaCustom = false; }
}

void checkTemperature(void)
{
    if (!Error.temperaturaTermo) {
        switch(config.modoTemperatura) {
            case 1: // Auto
                if (!config.flags.pwmMan && temperature.temperaturaTermo < config.temperaturaEncendido) { Flags.tempShutdown = false; Flags.pwmIsWorking = true; }
                if (!config.flags.pwmMan && temperature.temperaturaTermo >= config.temperaturaApagado) { if (pwm.invert_pwm > 0 || (myPID.GetMode() == PID::AUTOMATIC)) { Flags.tempShutdown = true; Flags.pwmIsWorking = false; shutdownPwm(false, "APAGADO TEMP AUTO\n"); } }
                break;
            case 2: // Manual
                if ((config.flags.pwmMan || Flags.pwmManAuto) && temperature.temperaturaTermo < config.temperaturaEncendido) { Flags.tempShutdown = false; Flags.pwmIsWorking = true; }
                if ((config.flags.pwmMan || Flags.pwmManAuto) && temperature.temperaturaTermo >= config.temperaturaApagado) { if (pwm.invert_pwm > 0) { Flags.tempShutdown = true; Flags.pwmIsWorking = false; shutdownPwm(false, "APAGADO TEMP MANUAL\n"); } }
                break;
            case 3: // Auto y Manual
                if (temperature.temperaturaTermo < config.temperaturaEncendido) { Flags.tempShutdown = false; Flags.pwmIsWorking = true; }
                if (temperature.temperaturaTermo >= config.temperaturaApagado) { if (pwm.invert_pwm > 0 || (myPID.GetMode() == PID::AUTOMATIC)) { Flags.tempShutdown = true; Flags.pwmIsWorking = false; shutdownPwm(false, "APAGADO TEMP AUTO/MAN\n"); } }
                break;
        }
    }

    if (((millis() - timers.ErrorLecturaTemperatura[0]) > config.maxErrorTime) && config.modoTemperatura > 0 && config.termoSensorAddress[0] != 0x0)
    {
        if (pwm.invert_pwm > 0) { Flags.pwmIsWorking = false; shutdownPwm(false, "APAGADO TEMP ERROR LECTURA\n"); }
    }
}
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

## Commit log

2020-03-01 Librerias actualizadas, añadido contador de tiempo en funcionamiento a la página de información (oled) y ajustes estéticos página web.
2020-03-01 Actualización de librerías
2020-03-11 Actualizada la versión a 1.0.2
2020-03-11 Correción en la reserva de variables en Estructura Config
2020-03-11 Añadida comprobación que impedia la grabación de la IP en el caso del wibeee
2020-10-27 Some changes on SMA inverters and fix some bad coding day.
    [Support_functions.ino, modbustcp.ino, pwm.ino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]
2020-11-01 Upload new release
    Versión 1.0.5 (Versión Final)
    - Modificada la gestión de temperatura para evitar falsos errores
    - Cambiados los tiempos mínimos de adquisición de datos (Modbus 250ms, Modbus TCP 1000ms (Fronius 250ms), Slave 250ms, Solax con ESP01 fijo a 250ms, HTTP API 1500ms)
    - Añadido contador básico de energia consumida y vertida según los datos de Red
    - Añadido comando "flipScreen" (desde la consola) para invertir la pantalla Oled
    - Añadido funcionamiento en instalación aislada (OFF-GRID)
    - Añadido soporte para Sunny Island (Aislada)
    - Correción errores en implementación Sunny Boy
    - Añadido soporte para SolarEdge mediante Modbus TCP
    - Solucionado fallo al reali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
    [FreeDS.ino, Support_functions.ino, display.ino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]
2020-11-16 Versión 1.0.6
    - Solucionado error en el cálculo de potencia consumida/vertida
    - Añadida comprobación para evitar multiples intentos de puesta en hora con equipos sin conexión o problemas de conectividad.
    - Solucionado lectura de datos erroneos en el Solax X1 Generación 3 (ESP01), es necesario escribir en la consola el comando: "solaxVersion 3", para elegir
    el nuevo modo de procesado de datos, si se desea volver al anterior escribir: "solaxVersion 2", es imprescindible hacerlo con el ESP01 conectado y funcionando.
    - Añadido comando para elegir la zona horaria, es necesario elegir la configuración correcta del fichero TimeZones.txt y escribir el siguiente comando en la consol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
    [FreeDS.ino, Support_functions.ino, asyncHttpClient.ino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]
2020-11-22 Fix change AUTO/MAN with temp sensor enabled.
    [FreeDS.ino, Support_functions.ino, asyncHttpClient.ino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]
2020-12-24 First PID implementation
2020-12-24 PID Library with some changes
2020-12-28 update arduino json
2020-12-31 Fix low cost output
    [FreeDS.ino, Support_functions.ino, pwm.ino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]
2021-01-05 bug fixes and soft transition between AUTO and MANUAL modes.
    [Support_functions.ino, pwm.ino, webserver_handlers.ino]
2021-05-23 Some fixes and changes
    [FreeDS.ino, Support_functions.ino, modbustcp.ino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]
2023-01-13 PCB Scheme upload
2023-05-27 Añadidos ficheros de PCB de @clinxer
    [FreeDS Lista de materiales y precios.ods, FreeDS.kicad_pcb, FreeDS.kicad_sch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]
2023-06-02 Correcciones en arquitectura clinxer
    [FreeDS Lista de materiales y precios.ods, FreeDS.kicad_pcb, FreeDS_potencia.kicad_pcb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]
2023-06-12 Corrección arq. clinxer: pines de optoacoplador
    [FreeDS_potencia.kicad_pcb, FreeDS_potencia.kicad_sch]
2023-12-02 Añadidos ficheros de arquitectura hardware "Sánchez rev1"
    [control.kicad_sch, freeds-sanchez-bom.ods, freeds-sanchez.csv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]
2023-12-08 New version with ACS712
    [FreeDS.kicad_pcb, FreeDS.kicad_sch, FreeDS_P.kicad_pcb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]

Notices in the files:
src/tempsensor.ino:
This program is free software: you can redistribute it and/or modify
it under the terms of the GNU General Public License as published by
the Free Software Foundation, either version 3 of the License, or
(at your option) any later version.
